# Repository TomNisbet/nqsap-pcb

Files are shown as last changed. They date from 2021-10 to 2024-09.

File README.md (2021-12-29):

# NQSAP-PCB

A multi-PCB version of the [NQSAP 8-bit computer](https://tomnisbet.github.io/nqsap/)

NQSAP-PCB

Visit the [NQSAP-PCB documentation pages](https://tomnisbet.github.io/nqsap-pcb/) for
detailed design notes and schematics.

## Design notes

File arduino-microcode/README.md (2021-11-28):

# NQSAP Microcode

This folder contains the Arduino sketch for the NQSAP Microcode Burner.  Some
documentation on the microcode is in the
[microcode documentation](https://tomnisbet.github.io/nqsap-pcb/docs/microcode/) section,
but the definitive resource is the burner code itself.

The hardware for the microcode burner is identical to the
[TommyPROM EEPROM Programmer](https://github.com/TomNisbet/TommyPROM) design.  The best
way to get started is to build and debug the hardware using that code and then compile
and load the microcode burner once the hardware is known to be working.  The TommyPROM
project has a better set of tools and more feedback to verify the design and even
includes a separate sketch for hardware troubleshooting if problems are encountered.

## Building

The Microcode Burner software is compiled using the Arduino IDE.  Load the
ardino-microcode.ino file and burn it to the target hardware.  Be sure to select the
correct Arduino board type under the tools->board menu.

## Burning microcode

The Microcode Burner sketch will burn a microcode ROM when the Arduino boots.  No user
interaction is needed.  When the burn is complete, the D13 LED will flash until the
Arduino is reset again.

If a USB cable is connected, progress messages will be printed to the serial output.

Every ROM burned receives a complete copy of the code for all of the Microcode ROMs, so
there is no need to make any selection when burning - just install each chip and then
power up the Arduino.

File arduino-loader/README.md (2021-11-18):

# NQSAP Loader and Debugger

This folder contains the Arduino sketch for the NQSAP Loader and Interactive Debugger.
The hardware design and features of the Loader/Debugger are listed in the
[Loader documentation](https://tomnisbet.github.io/nqsap-pcb/docs/loader/) in this repo.

This part of the project borrows heavily from the
[TommyPROM EEPROM Programmer](https://github.com/TomNisbet/TommyPROM) software.
Some details of the usage of the debugger, like the XMODEM transfers, may have additional
documentation available in that project.

## Building

The Loader software is compiled using the Arduino IDE.  Load the ardino-loader.ino file
and all of the supporting files should be included automatically.  Be certain to select
"Arduino Nano" as the Tools->Board menu of the IDE.

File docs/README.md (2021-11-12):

# NQSAP Documentation

To view the documentation, visit the [NQSAP-PCB github project page](https://tomnisbet.github.io/nqsap-pcb/)

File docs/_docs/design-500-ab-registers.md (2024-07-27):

---
title: "A/B and Shift Registers"
permalink: /docs/ab-registers/
excerpt: "A, B and Shift registers for the NQSAP-PCB computer"
---

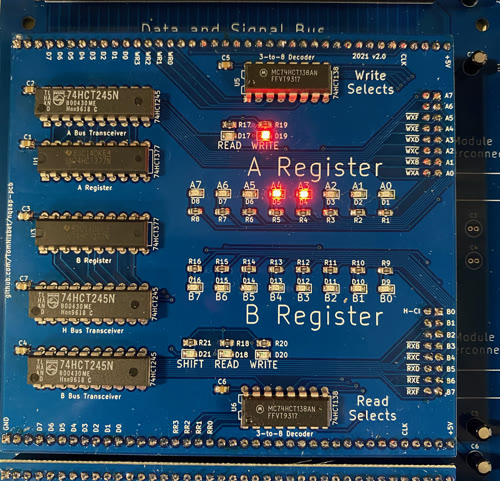
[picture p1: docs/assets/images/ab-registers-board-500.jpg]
A-B Registers


The A and B registers are 8-bit registers that provide the inputs to the ALU.  The A
register acts as an accumulator and general-purpose register that is accessible from
instructions available to the user.

The B register is only used as an operand register for the ALU operations.  It is not
accessible as a general-purpose register and there are no instructions to directly read or
write its contents.  The microcode may also use this register as temporarly storage for
non-ALU instructions.

The sHift register (register H), is a read-only register that returns the contents of the
B register shifted one position to the right.  The LSB of B shifts into the Carry flag.
The MSB of H is populated by the carry flag for the ROR (rotate right) instruction and is
hard-coded to zero for the LSR (logical shift right) instruction.  Note that H is not an
actual register.  It is simply a alternate way of reading the value of the B register.

The logic that controls the Carry Flag input, whether from the ALU or the B register, is on the [ALU Module](../alu).
The Carry Flag input for the H register is produced by the [Flags Module](../flags).

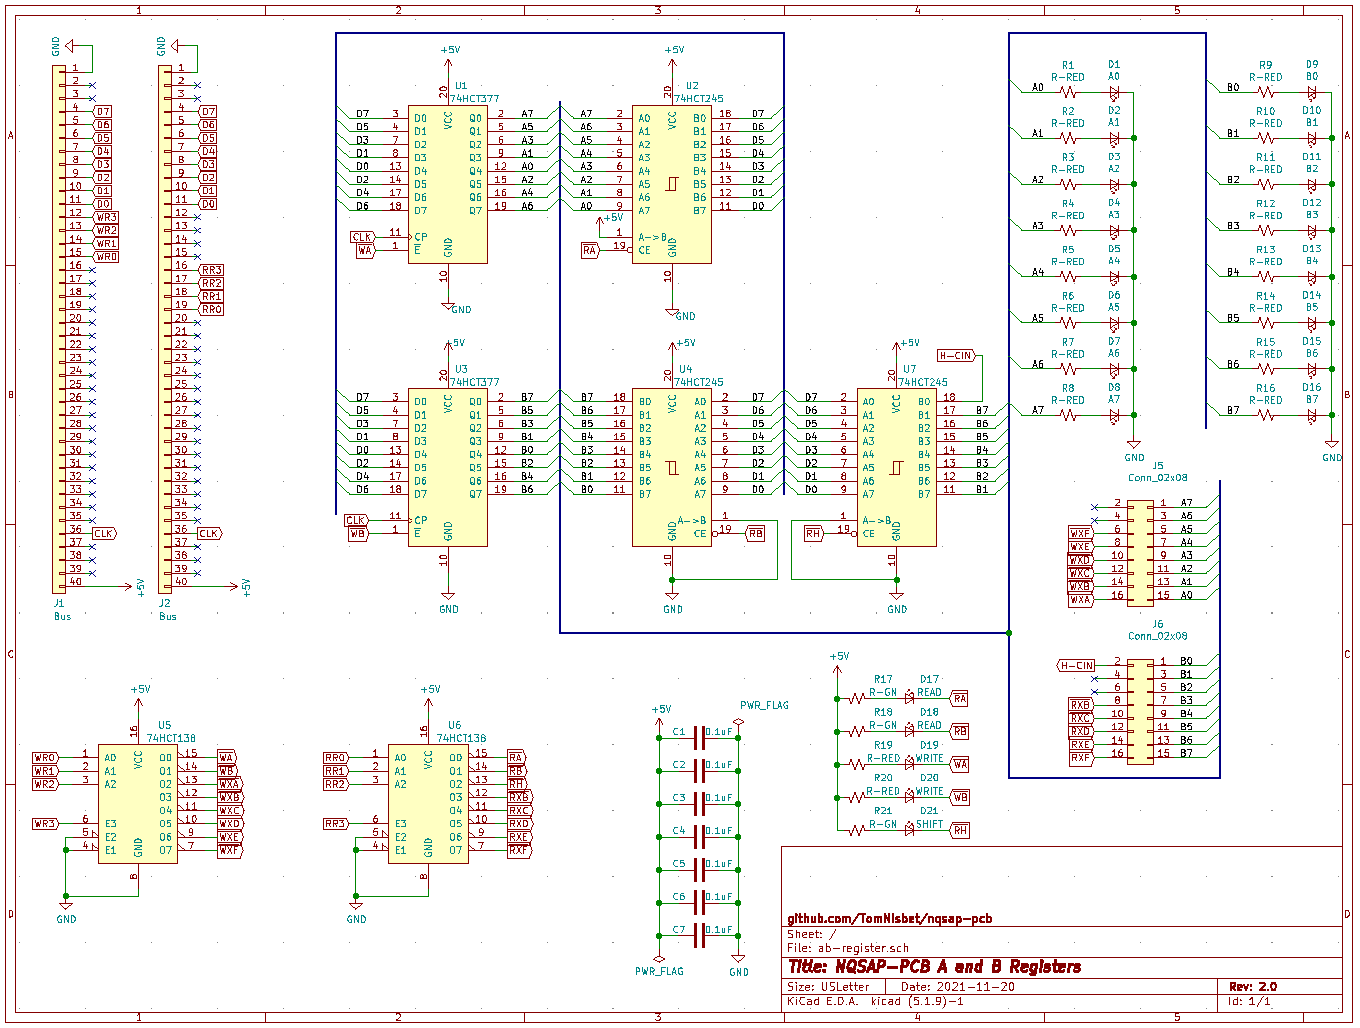
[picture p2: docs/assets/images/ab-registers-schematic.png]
A-B registers schematic


The A and B registers are each implemented using a 74HCT377 register and a 74HCT245 8-bit
bus transceiver. The H register is implemented using a second 74HCT245 wired to the B
register outputs, but offset by one bit.  The B7 bit is the H6 bit, B6 is H5 and so on.

The A/B Register module also has a pair of 74HCT138 3-to-8 decoders for read and write
register decoding.  These selects are used for the A/B/H registers on board and remaining
selects are presented on the module interconnect headers for use by the ALU and Flags
modules.

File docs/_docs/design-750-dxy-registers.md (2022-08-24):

---
title: "DXY Adder and Registers"
permalink: /docs/dxy-registers/
excerpt: "XY registers and Index Adder of the NQSAP computer"
---

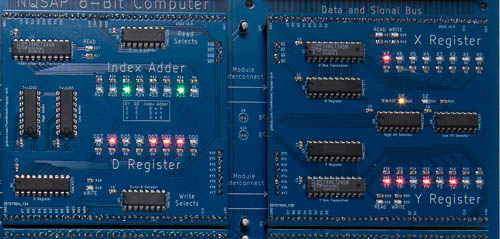
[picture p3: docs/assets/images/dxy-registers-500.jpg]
DXY Registers DXY registers and Index Adder


The XY registers and Index Adder are a set of three registers plus a dedicated adder to
implement two user-accessible registers and a set of new addressing modes.  The X and Y
registers are general-purpose registers that are also used as index registers. The D
register is a temporary register and adder that is only accessible at the microcode level.

With this hardware, NQSAP is able to use a set of addressing modes similar to those found
on a 6502.  The only difference is that the NQSAP does not have a sixteen-bit bus, so all
of the absolute address modes are the same as the zero-page modes of the 6502.  The
address modes available are:

* implicit
* accumulator
* immediate
* relative
* absolute
* absolute + X
* absolute + Y
* indirect
* indexed indirect (with X)
* indirect indexed (with Y)

With adder hardware dedicated to addressing modes, ALU instructions that access memory can
be implemented in fewer cycles.  Without the adder, the instruction _AND $40,X_ would need
to use the ALU to calculate $40+X and then would need the ALU again to do the AND
operation. This could be done in ten cycles and would need temporary storage to save the
accumulator while doing the address calculation.  With the DXY register, the instruction
can be implemented in only seven microinstructions, including the two for the opcode
fetch.

The D register can be added to either the X or Y register to produce a sum that can be
read onto the bus.  The diagram below shows how the registers are connected.

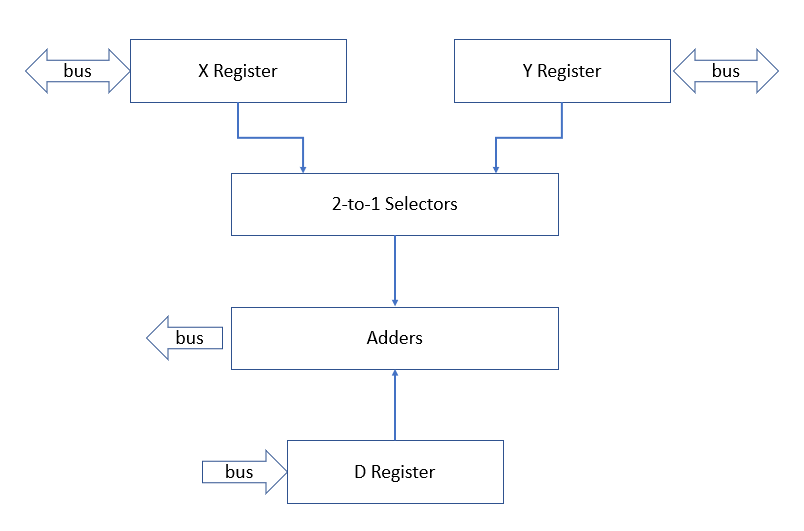
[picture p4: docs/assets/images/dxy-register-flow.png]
DXY Registers Flow DXY Registers data flow


The 2-to-one selectors allow either X or Y to be selected as a source for the adder.  The
selectors also have an enable line that presents zero at all of the outputs.  By wiring
the select and enable lines to the microcode ROMs, the functions D+X, D+Y, or D+0 can be
selected.

## Hardware

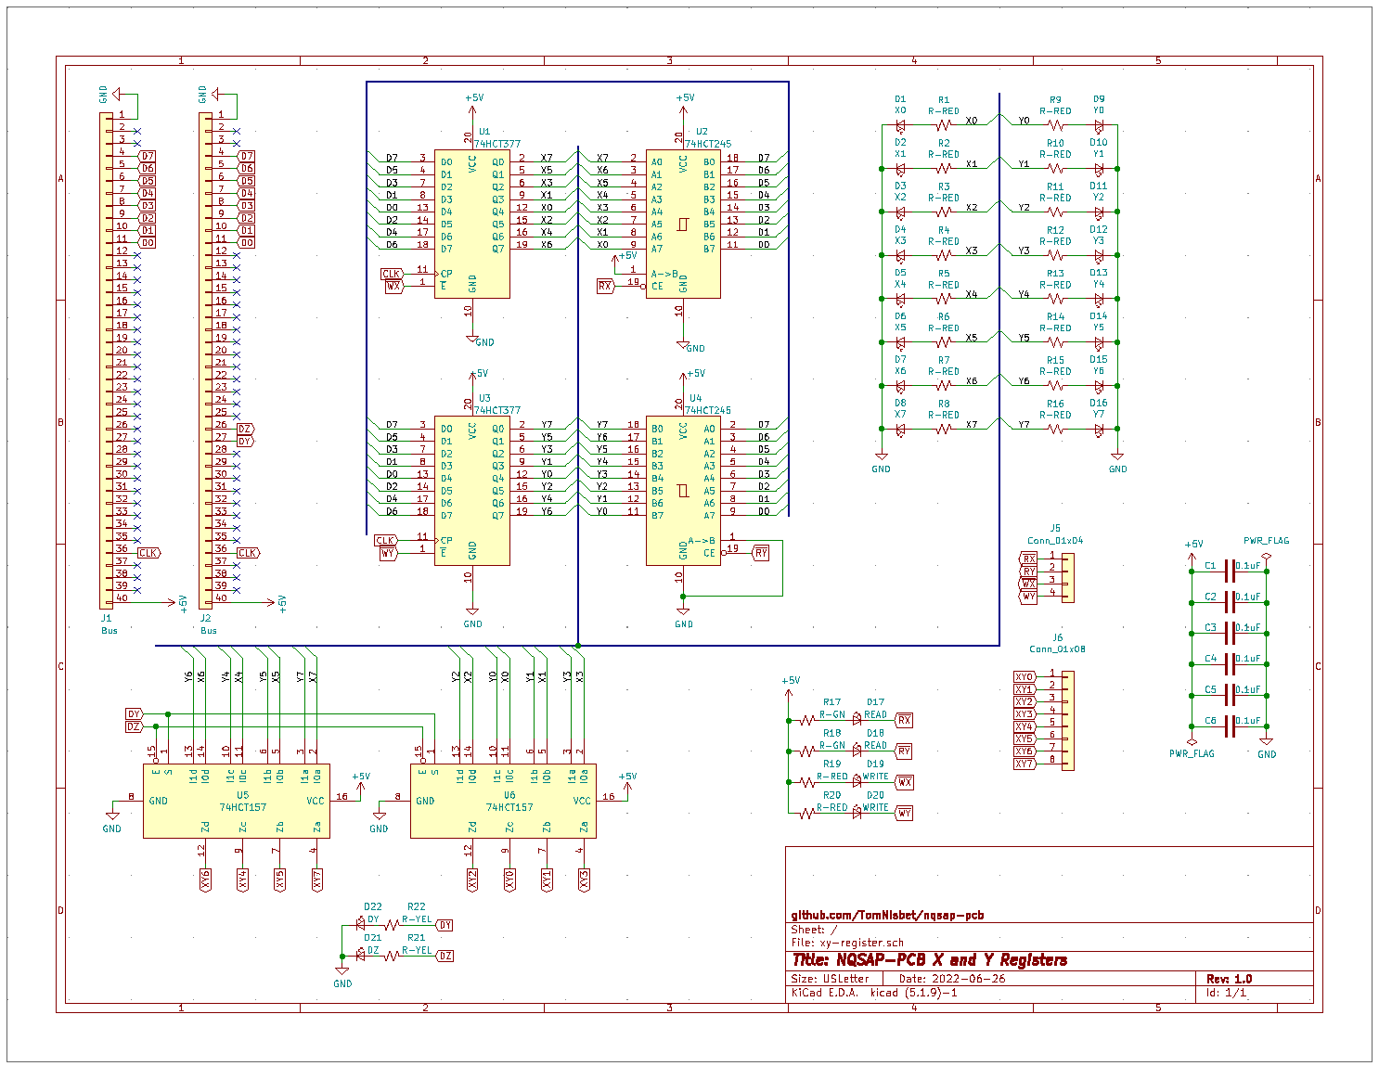
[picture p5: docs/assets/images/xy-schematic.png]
XY Registers Schematic XY registers

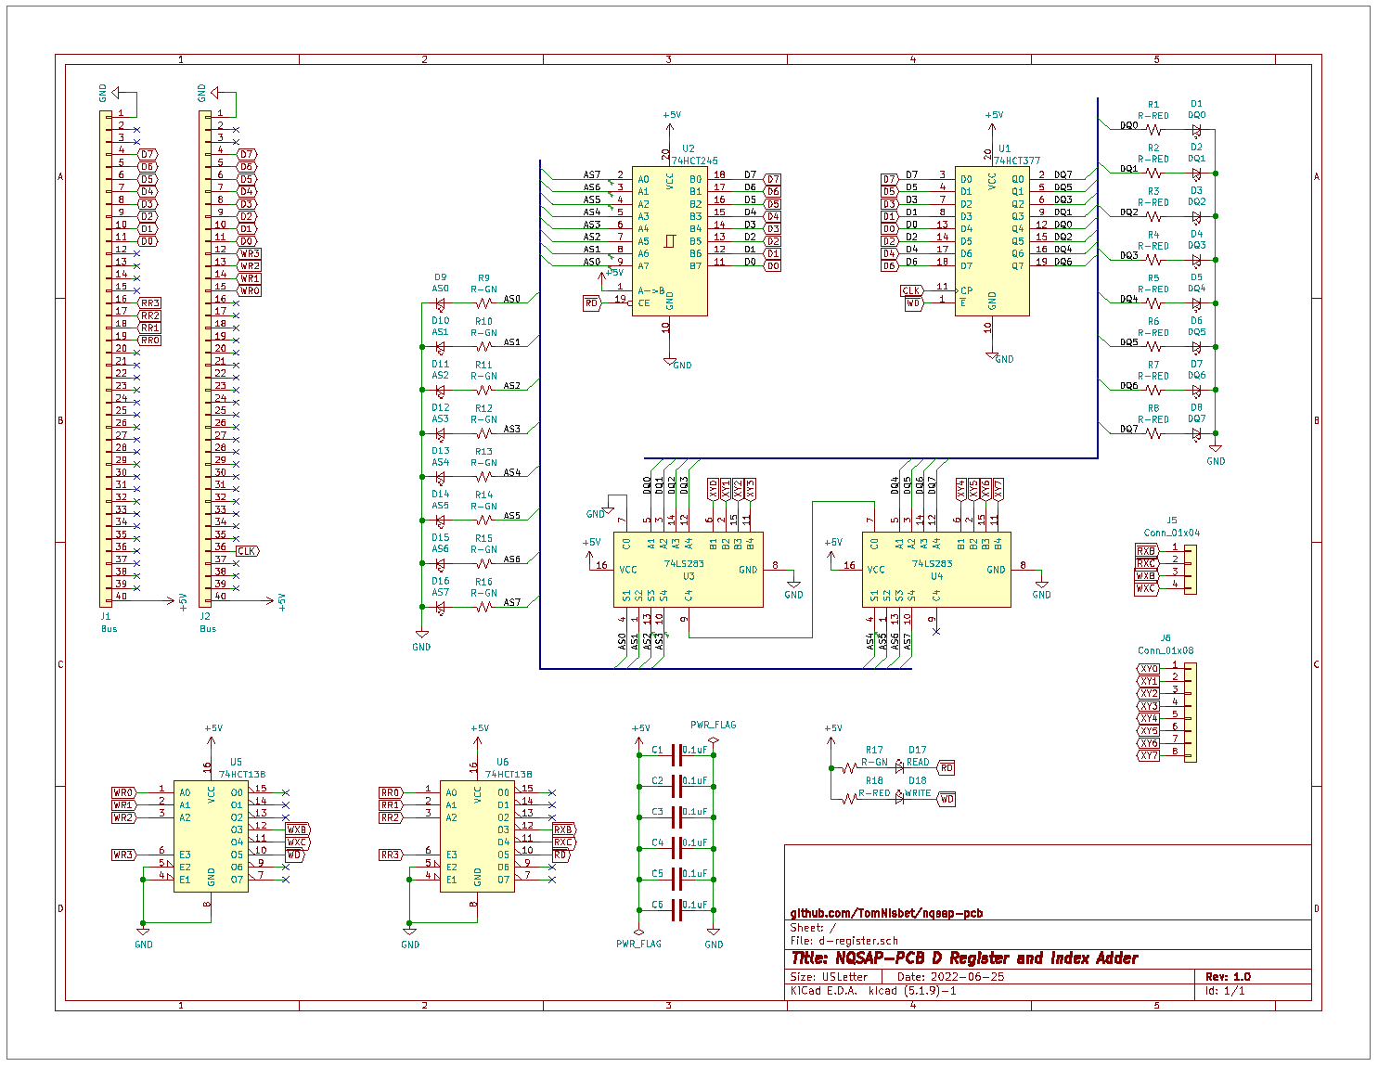
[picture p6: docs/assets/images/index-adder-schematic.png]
Index Adder D register and index adder


The Index Adder and XY Registers are spread over two module boards, mostly due to the
space needed for all of the LEDs. The X and Y registers are each implemented using a
74HCT377 8-bit register and a 74HCT245 8-bit bus transceiver.  The X and Y register
outputs are connected to the A and B inputs of a pair of 74HCT157 quad 2-to-1 selectors.
The selector outputs provide the XY<sub>0..7</sub> outputs on the module interconnect bus
for the Index Adder module.

The D register on the Index Adder module also uses the 74HCT377 register.  The board
contains a pair of 74HCT283 4-bit adders and a 74HCT245 bus transceiver.  The inputs to
the adders are the D register and the XY data output from the XY module.  The DY and DZ
lines from the microcode (shared with the C0 and C1 lines) are used to select the XY
source for the adder as X, Y, or zero.  The outputs of the adders are connected to the bus
through the 74HCT245.  The D register is not connected to the bus, but it can be read
through the adders by selecting the D+zero operation with the DZ control line.

The register select hardware for both boards is contained on the Index Adder module.  The
read and write signals for X and Y are passed through the module interconnect headers.

### Bill of Materials

* 74HCT138 3-to-8 selector(3)
* 74HCT157 quad 2-to-1 selector (2)
* 74HCT283 4-bit adder (2)
* 74HCT245 8-bit bus transceiver (3)
* 74HCT377 8-bit register (3)

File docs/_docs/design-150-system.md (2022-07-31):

---
title: "System Design"
permalink: /docs/system/
excerpt: "System-level design of the NQSAP-PCB computer"
---

## Register Decoding

The original breadboarded NQSAP had 4 control lines for read selects and 4 for write
selects.  Each of these was decoded to provide 15 rgister read and 15 register write
select signals.  The breadboard build had a single set of decoders, and then the 30
control lines were distributed out to the individual modules.  For the PCB build, the
limited number of bus lines makes this approach impractical.

The desire to keep the module boards at 100mm square and the use of a single row of
connector pins limited the bus to 40 pins total.  Using 30 of these pins just for register
decoding obviously would not work.  The tradeoff was to move the register decode hardware
to the module boards.

On the NQSAP-PCB build, the 4 register write selects and 4 register read selects are
presented on the bus, using a total of 8 pins.  Register select decoding is performed
locally and can be distributed across the module interconnects so that a group of three
module boards on a single backplane board can share a single set of decoders. Rather than
decode all 15 addresses, a module board will use a single 3-to-8 decoder to produce either
the low 7 addresses or the high eight addresses.

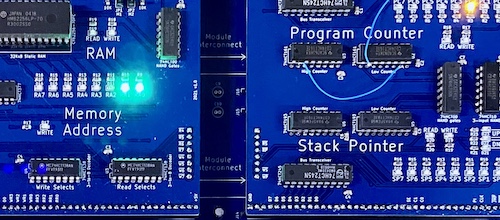
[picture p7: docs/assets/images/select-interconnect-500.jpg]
Register Select Interconnect register select interconnect


The picture above shows an example of a set of module boards sharing register select
decode logic.  The RAM board has a pair of 3-to-8 decoders to provide read and write
selects for the onboard RAM and MAR Register.  Additional selects are sent via the
interconnects for use by the PC/SP module.  While this does create dependencies between
groups of modules, it does eliminate the need for decode logic on each board or a larger
bus with centralized decoding.  In most cases, there are related boards that are already
passing other signals as well.

## Layout and Interconnects

The module interconnect headers on the backplane are used to connect signals that are
common to a small number of boards.  These interconnects keep the bus connectors limited
to signals that are typically used system-wide.  This does force the placement of some
modules in the final assembled computer.  The current design has four groups of related
modules that need to occupy the same backplane:

**Loader, Microcode, IR/RC**

The outputs of the Instruction Register and Ring Counter are sent to the Microcode module
to be used as address inputs to the EEPROMs.  The Loader sends control signals to the
Microcode board to disable the EEPROMs when the loader is active.

**A/B Registers, ALU, Flags**

The A/B board passes the outputs of its registers to the ALU as the as the operands for
arithmetic and logic calculations.  It also shares its register select signals.  The ALU
board passes calculated flag values to the Flags board and also forwards register selects
from the A/B board.

**RAM and PC/SP**

The RAM board has register select decoding for its own use and it shares additional select
lines over the intrconnect that are used by the PC/SP.  There are no other signals passed
between the boards, so the PC/SP could just as easily get its register selects from another
module or be re-spun to have them local.

**D/Index Adder and X/Y Registers**

An 8-bit value from the X/Y selector is passed to the Index Adder over the interconnects.
The D/Index Adder Module also provides the X/Y register select values.

## Register Selects

|Decimal|Hex  |Write|Read |Write Module|Read Module|
|:---:  |:---:|:---:|:---:|:---: |:---: |
|  0 | 0 |none |none | | |
|  1 | 1 |RAM  |RAM  |RAM |RAM |
|2 |2 |MAR  | |RAM | |
|3 |3 | | | | |
|4 |4 | | | | |
|5 |5 | | | | |
|6 |6 |SP |SP |RAM |RAM |
|7 |7 |PC (Jump)|PC|RAM |RAM |
|8 |8 |A |A |A/B |A/B |
|9 |9 |B |B |A/B |A/B |
|10 |A |Output|H (sHift)|Output |A/B |
|11 |B |X |X |D |D |
|12 |C |Y |Y |D |D |
|13 |D |D |Adder|D |D |
|14 |E | |ALU  | |A/B |
|15 |F |IR |Flags|IR |A/B |
|====

Note that modules use only one 3-to-8 decoder chip, so they can decode
either addresses 0-7 or 8-15.  The ALU and Flags modules use a local
copy of the IR, so even though the A/B and IR board do not share any
signals, they must both use addresses in the same group.

## Bus Signal List

|Pin|Name|Description|
|:---:|:---:|:---|
|1 |GND|Ground|
|2 |n/c|(spare)|
|3 |n/c|(spare)|
|4 |D7 |Data 7|
|5 |D7 |Data 6|
|6 |D7 |Data 5|
|7 |D7 |Data 4|
|8 |D7 |Data 3|
|9 |D7 |Data 2|
|10|D7 |Data 1|
|11|D7 |Data 0|
|12|WR3|Write Register 3|
|13|WR2|Write Register 2|
|14|WR1|Write Register 1|
|15|WR0|Write Register 0|
|16|RR3|Read Register 3|
|17|RR2|Read Register 2|
|18|RR1|Read Register 1|
|19|RR0|Read Register 0|
|20|FN |Flag write Negative|
|21|FV |Flag write oVerflow|
|22|FZ |Flag write Zero|
|23|FC |Flag write Carry|
|24|FB |write Flags from Bus|
|25|SE |Stack increment/decrement Enable|
|26|C1 |Carry select 1 (also DZ, Stack Increment)|
|27|C0 |Carry select 0 (also DY, Stack Decrement)|
|28|CS |Carry flag force Set|
|29|CC |Carry flag force Clear|
|30|M1 |Memory Select 1 (RAM)|
|31|M0 |Memory Select 0 (RAM)|
|32|LF |ALU Force select bit|
|33|~JE |Jump Enable (active low)|
|34|N  |Next instruction (clear ring counter)|
|35|PI |Program counter Increment|
|36|CLK|master Clock pulse|
|37|n/c|(spare)|
|38|n/c|(spare)|
|39|~RST|master RESET (active low)|
|40|Vcc|+5 Volts|
|====

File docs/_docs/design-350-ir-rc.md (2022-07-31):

---
title: "Instruction Register and Ring Counter"
permalink: /docs/ir-rc/
excerpt: "Instruction Register and Ring Counter for the NQSAP-PCB computer"
---

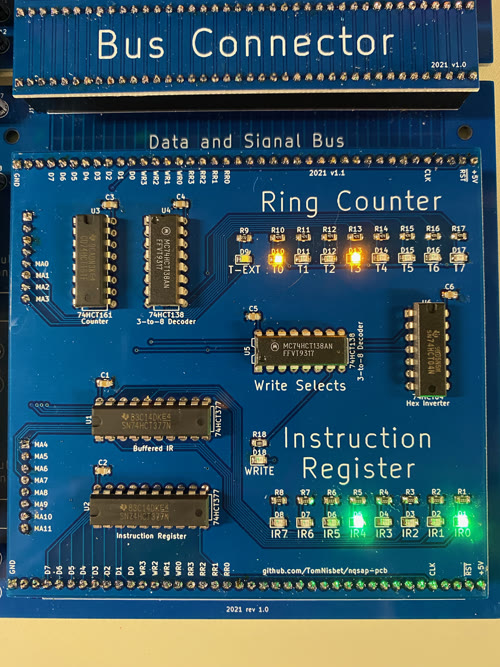
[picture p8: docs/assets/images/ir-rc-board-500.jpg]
Instruction Register and Ring Counter


The Instruction Register (IR) and Ring Counter (RC) provide a 12-bit address for the microcode ROMs.

## Ring Counter
This is really a binary microinstruction counter but it has two attached 3-to-8 decoders
that give output that looks like a ring counter.  This output is only used for the LED
display that indicates the step - the input to the ROMs will be the 4-bit binary output of
the counter. Still, the ring counter terminology is used to match the Ben Eater builds.

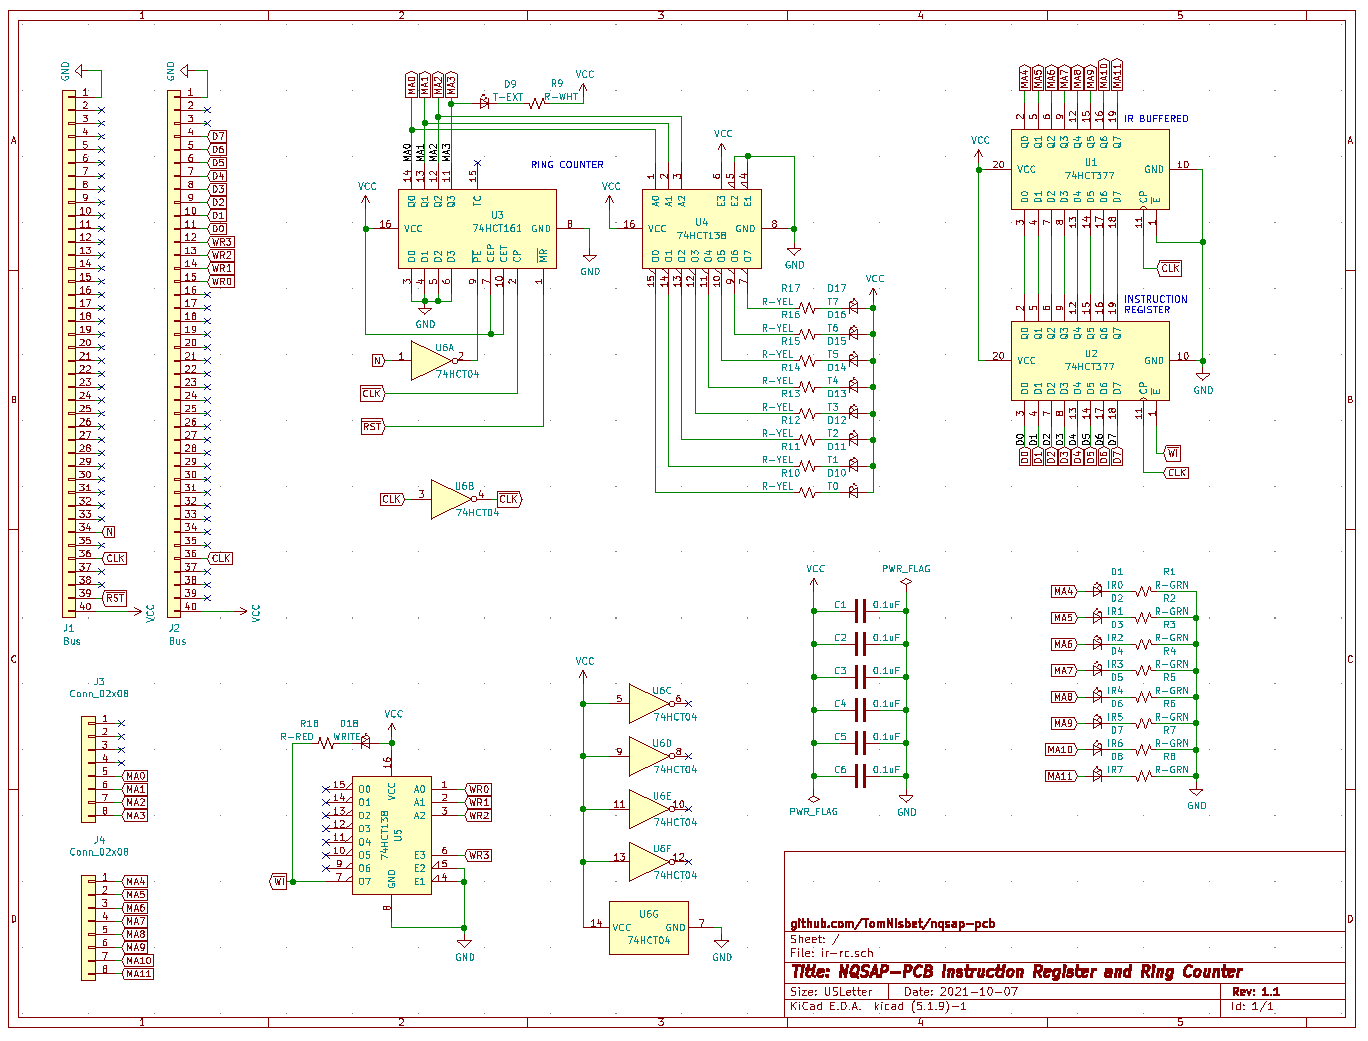
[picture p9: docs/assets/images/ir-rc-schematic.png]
Instruction Register and Ring Counter schematic


## Instruction Register

The Instruction Register is double buffered to reduce
[glitches when the EEPROM address lines change](../eeprom-glitch).  In the non-buffered
design, the EEPROM outputs will be in an unknown state for about 100ns when the Ring
Counter address changes on every falling edge of the system clock.  In addition, the
outputs will also glitch on the rising edge of the clock at instruction step T1 when the
IR is loaded with the new opcode.  The double buffer adds a second register following the
IR register that loads at T1.  This register loads the contents of the IR and presents
them to the ROM address lines on every falling edge.  As a result, the EEPROM address
lines only ever change on a falling clock edge, allowing logic that combines ROM signals
with a positive clock signal.

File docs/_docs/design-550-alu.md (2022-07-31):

---
title: "ALU"
permalink: /docs/alu/
excerpt: "Building the Arithmetic Logic Unit (ALU) of the NQSAP computer"
---

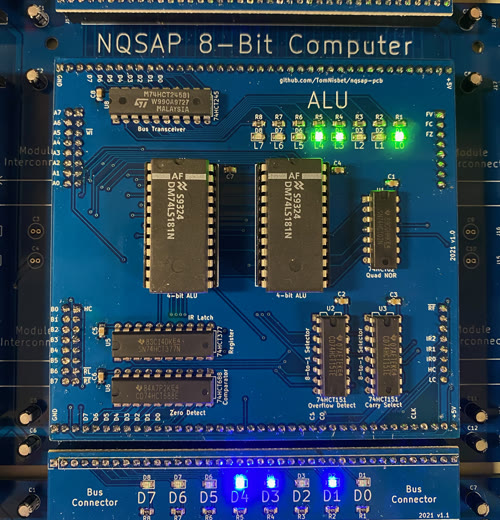
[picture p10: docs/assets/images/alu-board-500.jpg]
Arithmetic Logic Unit (ALU) ALU


The NQSAP-PCB computer uses a pair of 74LS181 4-bit ALU chips instead of the simple
adder/subtractor circuit in the SAP-1.  The advantage to this is a greatly increased set
of operations available, including increment/decrement as well as bitwise AND OR, and XOR.

The disadvantage to the use of an ALU chip is that the 74181 requires 6 control lines to
select an operation, rather than the single ADD/SUBTRACT needed for the simple adder.

In the NQSAP-PCB design, the Mode bit and the 4 Operation Select bits are hard-wired to
the Instruction Register, so that the opcode of the instruction directly determines the
operation selected on the ALU.  This saves the need for 5 additional control lines from
the microcode ROMs.  It also makes the microcode for all ALU operations identical, so they
can be generated programmatically in the Arduino code.  Because the Mode and Select lines
are wired to the Instruction Register, only the Carry-in signal is provided by the
microcode ROMs.

Rather than providing the outputs of the Instruction Register on the bus or requiring an
interconnect between the IR and ALU, the ALU module keeps its own copy of the IR in a
local register that loads on the WI signal.  Five bits of this register are used by the
ALU, and three more are passed to the Flags Module for conditinal jump selection.

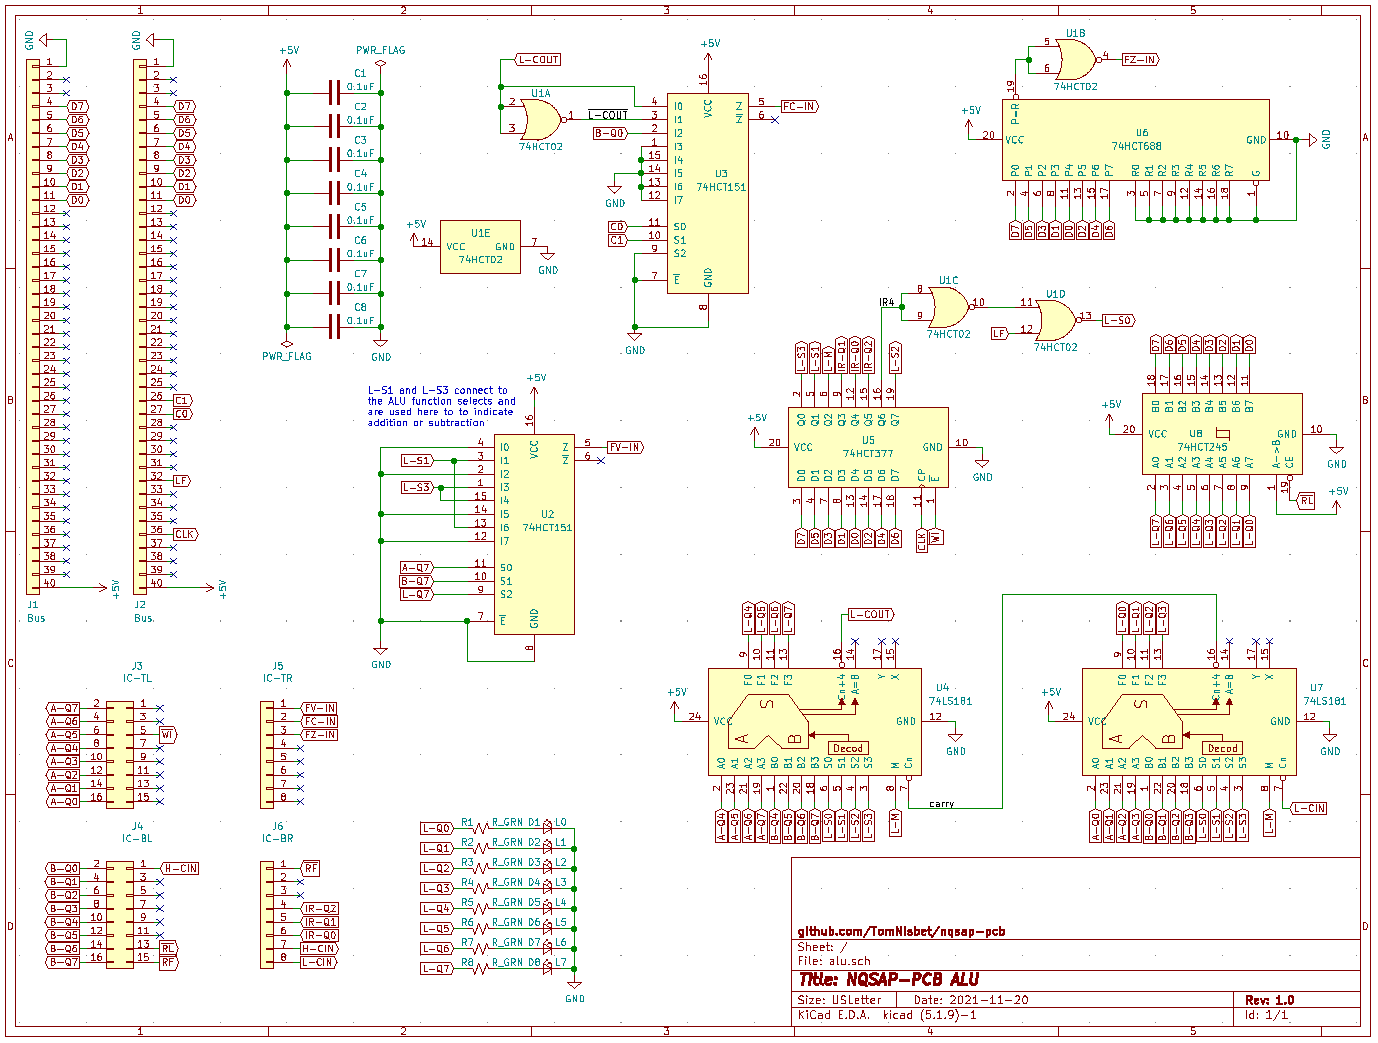
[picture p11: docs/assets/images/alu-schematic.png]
NQSAP ALU schematic) ALU schematic


The inputs to the ALU are the A Register (H) and the B register.  All ALU instructions
write their result to the A register.

Note that the subtract and compare instructions both need the ALU to be in subtract mode.
Because the ALU select lines are hard-wired to the IR, there are only eight opcodes
available that put the ALU in the correct mode.  To create the sixteen different opcodes
that are needed for all of the addressing mode combinations of the subtract and compare
instructions, a NOR gate is placed between the inverted IR output and the ALU S0 input.
The other NOR input is the microcode ROM LF (aLu Force) line.  When this is asserted,
the ALU S0 is forced to zero.  This is used to create a new set of eight subtract mode
instructions by setting the ALU select bits to 0110 when the low IR bits are 0111.  The
ALU operation for 0111 would normally be A and not B, which isn't useful.

In addition to the 74181 ALUs, the NQSAP ALU module needs a few more chips.  As with other
read registers in the NQSAP, a 74HCT245 bus transceiver is used to selectively place the
ALU result on the bus.  

Note that the ALU result is a read-only register.

## 74181 ALU operations used by NQSAP

|M | Cn| S3| S2| S1| S0|Operation|
|:---:|:---:|:---:|:---:|:---:|:---:|---|
|0 | 0 | 0 | 0 | 0 | 0 | A plus 1
|0 | 0 | 0 | 0 | 1 | 1 | zero
|0 | 0 | 0 | 1 | 1 | 0 | A minus B
|0 | 1 | 0 | 0 | 1 | 1 | all ones
|0 | 1 | 1 | 0 | 0 | 1 | A plus B
|0 | 1 | 1 | 1 | 0 | 0 | A plus A _[left shift]_
|0 | 1 | 1 | 1 | 1 | 1 | A minus 1
|1 | x | 0 | 0 | 0 | 0 | not A
|1 | x | 0 | 1 | 1 | 0 | A xor B
|1 | x | 1 | 0 | 1 | 0 | B
|1 | x | 1 | 0 | 1 | 1 | A and B
|1 | x | 1 | 1 | 1 | 0 | A or B
|====

The ALU all-zero bits and all-one bits operations are used in the microcode to get zeros
or ones onto the bus for the flag set and clear operations.

The B operation is no longer used.  It was originally used by the CALL instruction to read
B for temporary storage.  The B register was later redesigned to add its own bus
transceiver to allow direct read access.

## Flags

Most of the flag condition detection circuitry is present on the ALU module, rather than
on the Flags module.  Ths was done because the Flags module was already densly populated
and the ALU module had free space.  It was easy enough to place the three flag detection
outputs on the interconnect between the boards.

See the [Flag Calculations section of the Flags page](../flags/#flag-calculations) for a
description of the flag detection hardware.

### Zero flag

The 74181 ALU does not have an output to indicate a zero result from an operation so a
74HCT688 8-bit comparator is used to detect all zeroes on the bus.  The ALU does have an
_A=B_ bit that can be used for comparison operations, but it is not used in the NQSAP
design.

Using the bus instead of the ALU output for zero-detect means that it can also be used
with non-ALU operations like register loads or transfers.

### Carry flag

Using the carry flag output (C<sub>n+4</sub>) as a processor flag is not straightforward
to understand because the logic state used to indicate an overflow changes depending on
the operation.  For the addition operations, a logic LOW indicates carry occurred, but
logic HIGH is used to indicate borrow needed for subtraction.  See the
[74181 ALU notes](../74181-alu-notes/) section for an explanation of why the chip does
this.

|Selects|Operation|C<sub>n+4</sub> on overflow|
|:---:  |:---: |:---:|
| LLLL  | A + 1 |  L  |
| LHHL  | A - B |  H  |
| HLLH  | A + B |  L  |
| HHLL  | A + A |  L  |
| HHHH  | A - 1 |  H  |
|====

The NQSAP addition and subtraction operations are modeled after the 6502 processor.  An
addition with carry instruction will produce A+B when carry is clear and A+B+1 when carry
is set.  The carry flag will be set at the completion of the operation if the addition
carried into the non-existent ninth bit.

A subtraction with carry operation will produce A-B-1 when the carry bit is clear and A-B
when the carry is set.  The carry flag will be cleared at the completion of the operation
if the subtraction required a borrow from the non-existent ninth bit.

This usage is consistent with the 74181 ALU, but the use of the flag is inverted because
the 74181 uses an active low carry signal.  The C<sub>n+4</sub> carry out signal from the
high ALU is inverted to provide the 6502-like flag.

### oVerflow flag

## Bill of Materials

* 74HCT02 quad 2-input NOR gates (1)
* 74HCT151 8-to-1 selector (2)
* 74LS181 4-bit Arithmetic Logic Unit (2)
* 74HCT245 8-bit bus transceiver (1)
* 74HCT377 8-bit register (1)
* 74HCT688 8-bit comparator (1)

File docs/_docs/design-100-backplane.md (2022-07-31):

---
title: "Backplane"
permalink: /docs/backplane/
excerpt: "Backplane for the NQSAP-PCB computer"
---

The NQSAP-PCB backplane and interconnect design is based on an [8-bit PCB implementation
by
djh82uk](https://www.reddit.com/r/beneater/comments/pn4j6j/finally_complete_with_all_bugs_fixed/)

The system is built from three types of boards.  The Backplane board is a passive base
board with a generic 40 pin bus.  Module boards have the functional circuitry for the
computer, like the registers, ALU, or Program Counter.  Module boards plug into the bus
connectors on the Backplane board.  A single Backplane can hold three Module boards.  Bus
Connector boards connect two adjacent Backplane boards, extending the system vertically to
accomodate additional modules.  

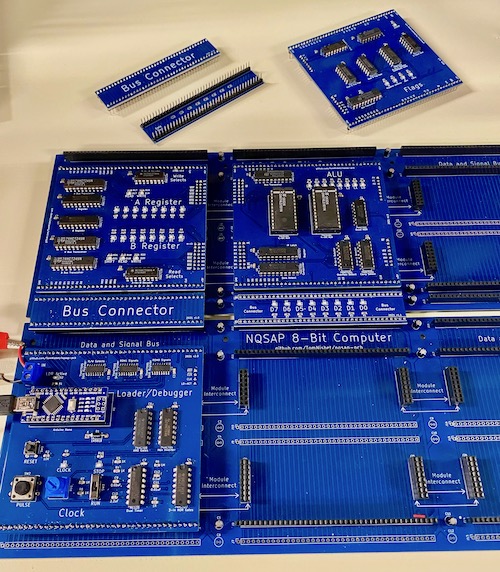
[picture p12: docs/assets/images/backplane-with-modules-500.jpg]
Backplane with modules backplane with module boards


In addition to the bus signals, which connect to all modules, the Backplane board also has
interconnect headers that allow signals to be passed between two adjacent Module boards.
For example, the A/B Register module uses the interconnects to pass the A and B outputs to
the ALU module.

The Backplane boards contain no active components.  Other than the ground and power
connections on pins 1 and 40 of the bus, there are no other bus signals that are
interpreted by the backplane.  This makes it suitable to any number of generic designs.

## Backplane and Bus

The main system bus is 40 pins using 2.54mm spacing.  This was chosen as the largest
number of pins that would find on a 100mm board.  All of the 40 pin connectors on the
bakplane are wired together, so pin one on a connector is wired to pin one on every other
connector.

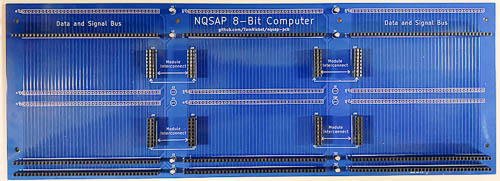
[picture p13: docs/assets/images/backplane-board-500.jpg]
Backplane backplane


Each Backplane board can hold three full-height modules across.  Any module slot can hold
one full-height or two half-height modules.  The full size module boards measure 90mm from
the top row of pins to the bottom row.  The total board height is 96mm.  The current
system is not using and half-height modules.

Module boards attach to the Backplane board using 40 pin headers along the top and bottom
edge of the module.  This provides both the electirial and mechanical connection - there
are no screws or fasteners to hold the modules in place.  The signals are identical on the
top and bottom connectors, so the modules can pull signals from either set of pins, giving
flexibility in their routing.

Backplane boards have additional 40-pin bus connectors along the top and bottom so that
multiple backplane boards can be chained together to accomodate additional groups of three
module boards.  A small Bus Connector board is used to connect the backplanes. Three Bus
Connectors are used to provide mechanical stability between a pair of backplanes. Each one
of the three is connecting the entire bus, so only one Bus Connector is technically needed
to make the electrical connections.

## Backplane module interconnects

A 2x8 pin header is provided between each half-height board to make module-to-module
connections.  A full height board can use both sets of connectors for a total of 32 pins.
Rather than being connected left to left and right to right, the interconnects have the
inner pins connected and the outer pins connected.  A module needing 8 or fewer
connections could populate just a 1x8 connector instead of a 2x8 to save space.

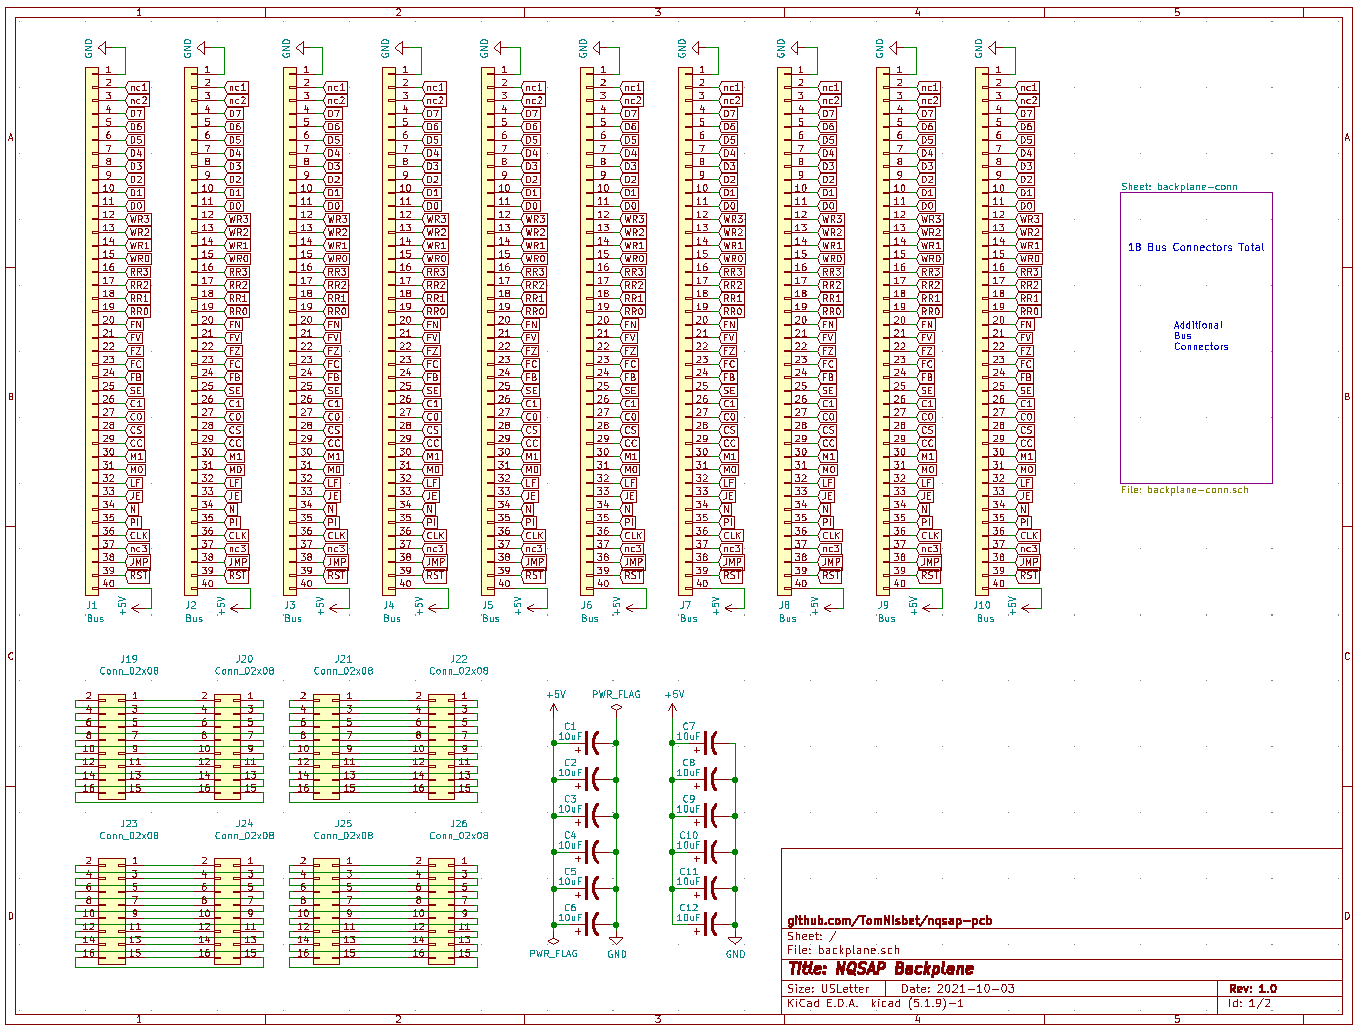
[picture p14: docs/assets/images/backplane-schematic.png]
Backplane backplane


Note that the interconnects are not connected all the way across the backplane.  If the
left module and right module need to talk, the signals will need to route through the
middle module.  Because the interconnects do not connect all the way across, it is
possible that the left and middle modules could use a different set of interconnects as
the middle and right modules.

There are no module-specific interconnects vertically, so related boards should share the
same backplane board to leverage the horizontal interconnects.

## Bus connectors

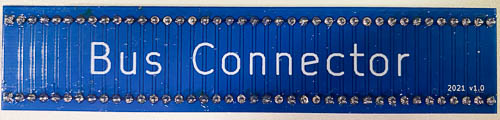
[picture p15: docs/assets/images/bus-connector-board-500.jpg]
Bus connector bus connector
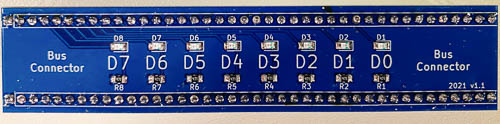
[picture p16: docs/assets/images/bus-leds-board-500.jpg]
Bus LEDs bus LEDs


The Bus Connector boards connect Backplane boards together to expand the computer
vertically. Three connectors are used between each pair of backplane boards.  The bus
connectors wire all 40 lines top-to-bottom.

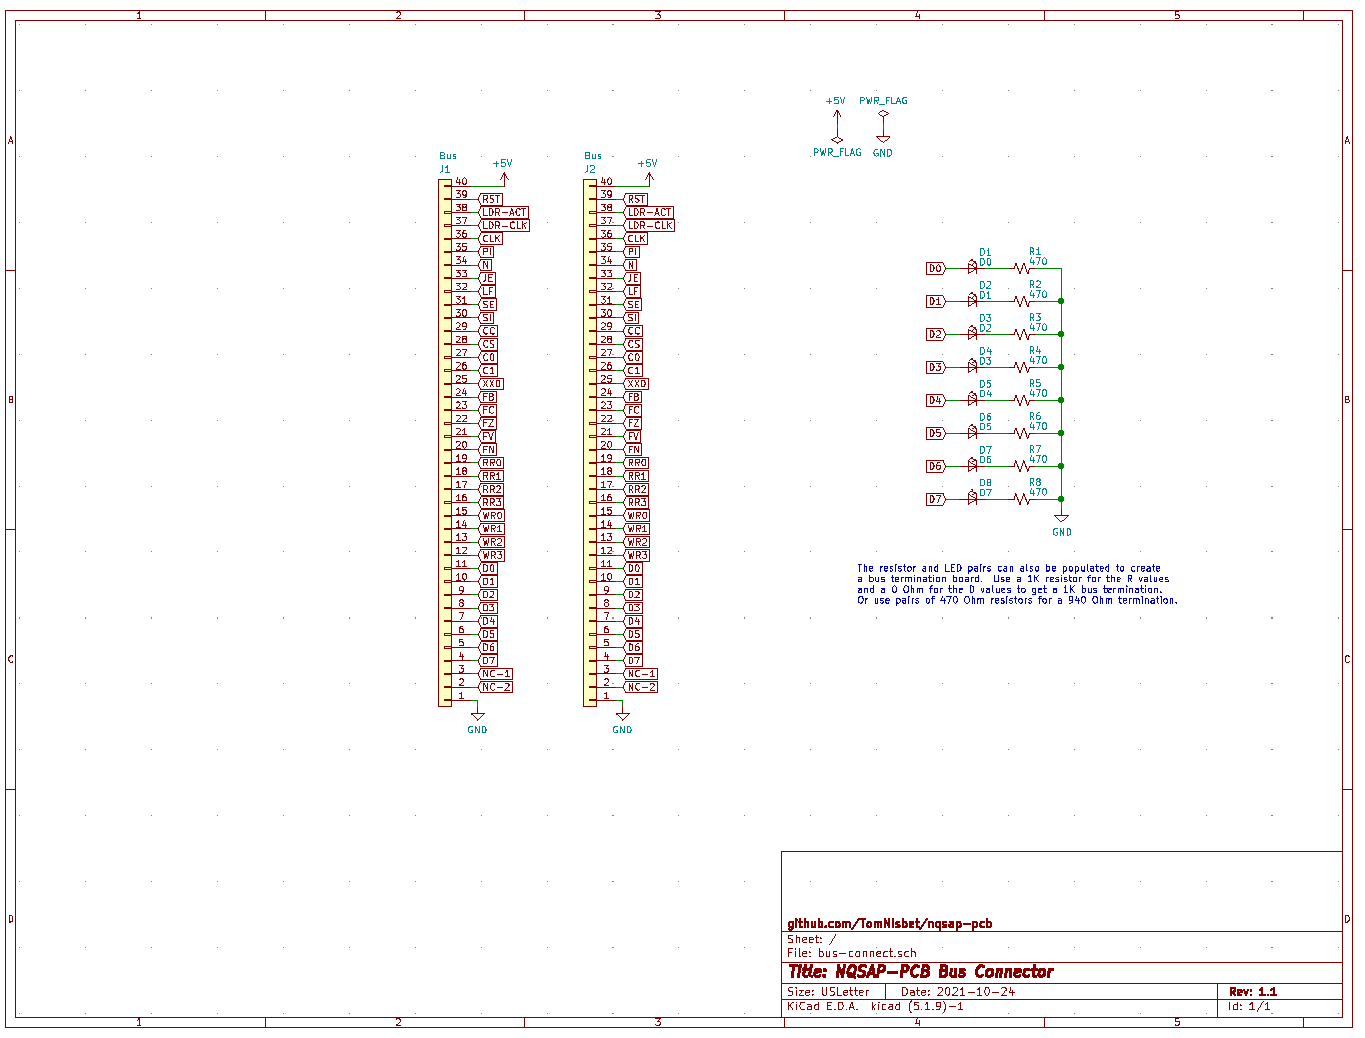
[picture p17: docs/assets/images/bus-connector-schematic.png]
Bus connector schematic bus connector schematic


### Data LEDs and termination
The Bus Connector boards have additional functionality on the reverse side.  With the board flipped and the pin headers installed on the other side, LEDs and resistors can be added to display the status of the data bus.

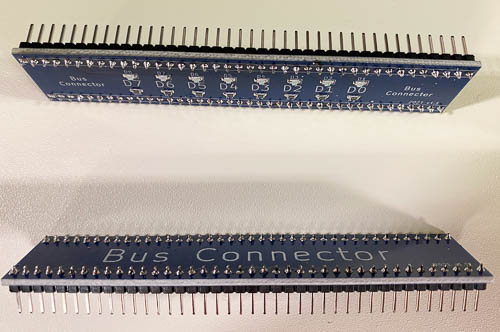
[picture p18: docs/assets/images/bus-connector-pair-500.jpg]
Bus connector variations bus connector variations


The resistor and LED pairs can also be populated to create a bus termination board.  Use a 1K resistor for the R values and a 0 Ohm for the D values to get a 1K bus termination. Or use pairs of 470 Ohm resistors for a 940 Ohm termination.

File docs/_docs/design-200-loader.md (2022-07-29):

---
title: "Loader / Debugger"
permalink: /docs/loader/
excerpt: "Arduino-based Loader/Debugger for the NQSAP-PCB computer"
---

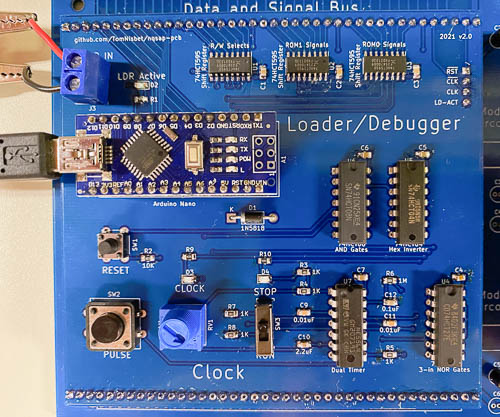
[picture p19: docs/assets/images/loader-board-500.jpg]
Arduino Loader loader


Version 2.0 of the Loader module adds the system clock and master reset circuits to the
board.  There was space on the board and it makes sense to co-locate these functions to
reduce the number of signals that need to be on the control bus.  The
[clock module page](../clock/) has the schematics and circuit description for the clock
functionality.

The program memory loader uses an Arduino Nano in place of manual-entry DIP switches on
the SAP-1.  The Loader/Debugger has eight of the Arduino I/O lines connected directly to
the NQSAP host bus for read and write access.  It can drive all of the microcode control
lines plus the CLK and RST lines.

Beyond the ability to simply load programs into memory, the Loader can read and write all
of the NQSAP registers and drive any other control signals. This gives the Loader the
capability to perform a comprehensive system verification.  This system test is helpful
for verifying the operation of new modules.

The Loader writes a default program to the NQSAP memory at power up, allowing unattended
operation.  If a USB connection is established, the Loader provides a ROM monitor-like
command line interface to interact with the NQSAP hardware.  The following features are
available via the USB interface:

* Memory
  * Load memory from a set of programs or patterns that are hard-coded into the Loader
  * Dump the contents of memory in hex and ASCII
  * Edit memory values
  * Fill a section of memory with a value
  * Load or save memory to a file using the XMODEM protocol
* Registers
  * Read and print the value from a register
  * Write a value to a register
  * Transfer the value from one register to another
* Diagnostics
  * Test all microcode control lines with a walking LED pattern
  * Test all registers with a pattern that can be visually observed
  * Test all read/write registers by reading back the patterns written
  * Test memory with a set of patterns including walking bits
  * Test the ALU by writing operands and operations and verifying the result
  * Test the right-shifted value of the B register as presented on the H register
  * Test the calculation of the flag values and the conditional jumps
  * Test the increment and decrement operations of the Stack Pointer

## Loader Design

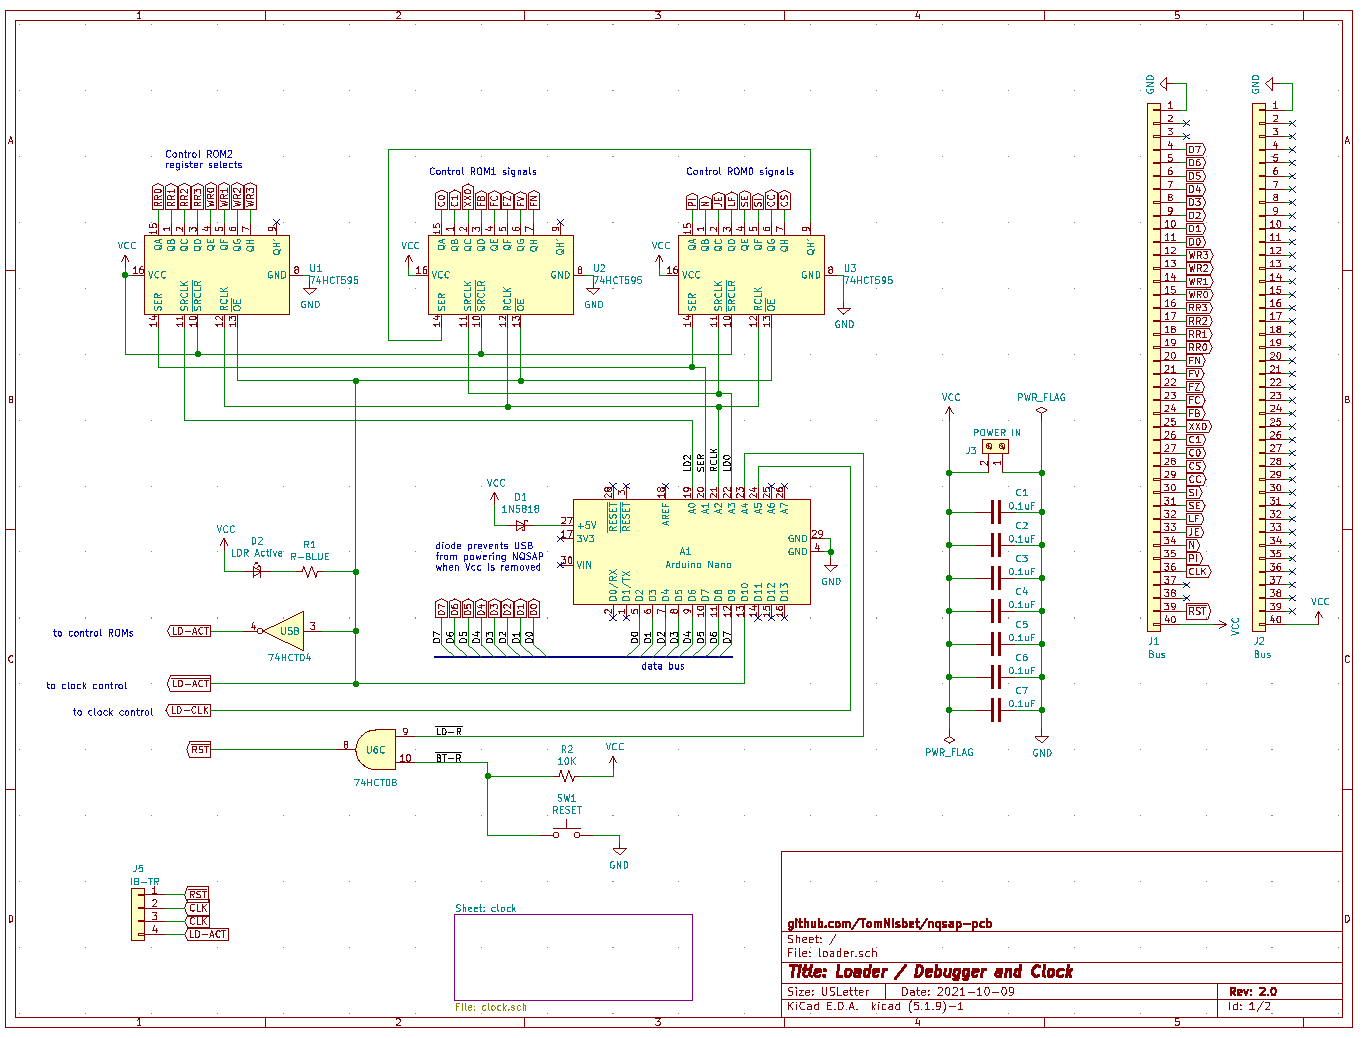
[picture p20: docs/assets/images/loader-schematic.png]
Arduino Loader loader/debugger


The Loader uses three 74HCT595 8-bit shift registers to drive the twenty-four microcode
ROM control outputs. The output enable of these registers is tied to the Loader's ACTIVE
signal and the output enable of the microcode ROMs is the inverted ACTIVE signal, ensuring
that only one source will be outputting a signal at any time. The Loader uses four Arduino
outputs to drive the inputs of the shift registers.  

## Loader implementation

The loader uses an Arduino Nano clone.  Note that the Loader Arduino is designed to be
left in the circuit even when not connected to a controlling computer through USB.  Upon
power up, the loader will activate itself and then load a default program into the NQSAP.
So even in standalone mode, the NQSAP will power up into a state where it has code to
execute.  There is no manual dip switch loader, so there is no way to load memory without
the Arduino.

The Arduino is powered from the NQSAP Vcc through a diode so that if the NQSAP is powered
off it does not try to draw power from the Arduino's USB port.  The USB port is connected
to the host computer with a hub that has individual power switched, allowing the host
computer's power to be disconnected from the NQSAP.

## Bill of Materials

This BOM includes the reset and clock circuitry as well as the Loader.
* 74HCT04 hex inverter (1)
* 74HCT08 quad 2-input AND gate (1)
* 74HCT27 triple 3-input NOR gate (1)
* 74HCT595 8-bit shift register (3)
* NE556 dual timer (1)
* Arduino Nano

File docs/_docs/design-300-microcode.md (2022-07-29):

---
title: "Microcode ROMs"
permalink: /docs/microcode/
excerpt: "Microcode ROMs for the NQSAP-PCB computer"
---

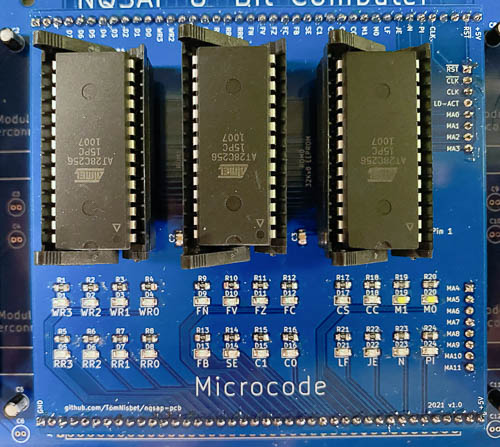
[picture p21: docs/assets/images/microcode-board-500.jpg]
Microcode ROMs


The microcode ROMs drive the 24 control signals for the NQSAP-PCB computer.  This board
contains LEDs for all control signals.

With an 8-bit Instruction Register and a 4-bit Ring Counter, the NQSAP
can support 256 unique instructions with 16 microcode steps each.  This consumes 12 of the 15 available address pins on the ROMs.  The
chip select uses 2 more pins, and 1 address pin is unused.

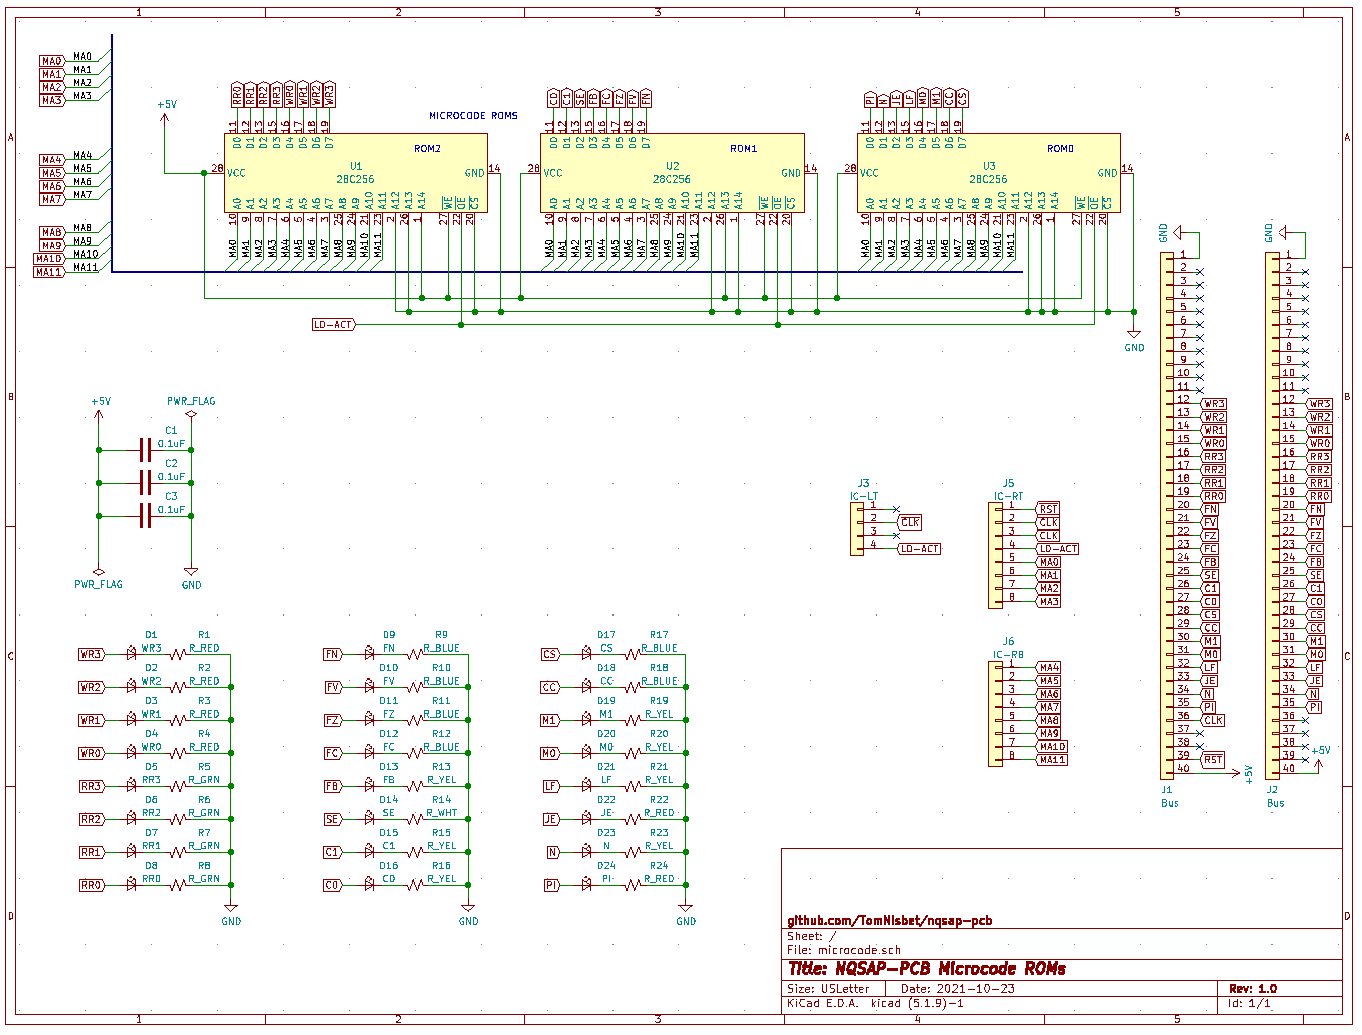
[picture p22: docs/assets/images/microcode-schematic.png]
Microcode ROMs schematic


The microcode is stored in three 28C256 32Kx8 EEPROMs, giving 24 control signals.  The
signals can be driven by the ROMs or by the Arduino Loader/Debugger.  When the Arduino
is active, the OE signal of the ROMs is disabled.  The LEDs always show the state of the
control lines, whether they are driven by the ROMs or by the Loader.

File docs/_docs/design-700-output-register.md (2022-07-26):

---
title: "Output Register"
permalink: /docs/output-register/
excerpt: "Output register and display of the NQSAP computer"
---

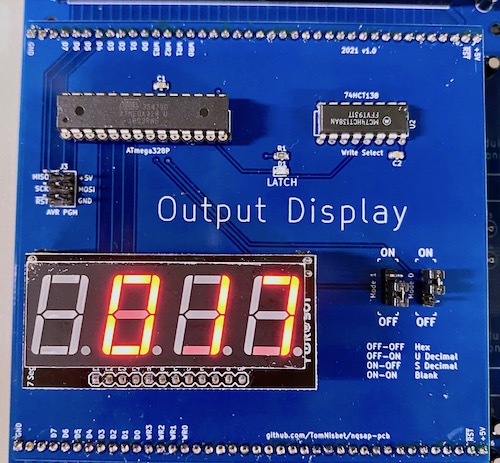
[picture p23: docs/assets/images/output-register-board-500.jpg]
Output register and display output register


The NQSAP uses a different approach to the output display than the Ben Eater SAP-1.
Instead of driving an LED display with a sequencer and an EEPROM, an ATmega328 is used.
The Atmega replaces not only the EEPROM and counter hardware, but it also takes care of
the buffering, eliminating the 74ls173 registers.

The board includes its own address decoding hardware, so it has no dependencies on other boards and requires no interconnet. There is a space to populate an AVR connector to
flash new code onto the ATmega328P.

The output register can be jumpered to display its result in one of three modes:

* hex (00 to ff)
* signed decimal (-128 to 127)
* unsigned decimal (0 to 255)

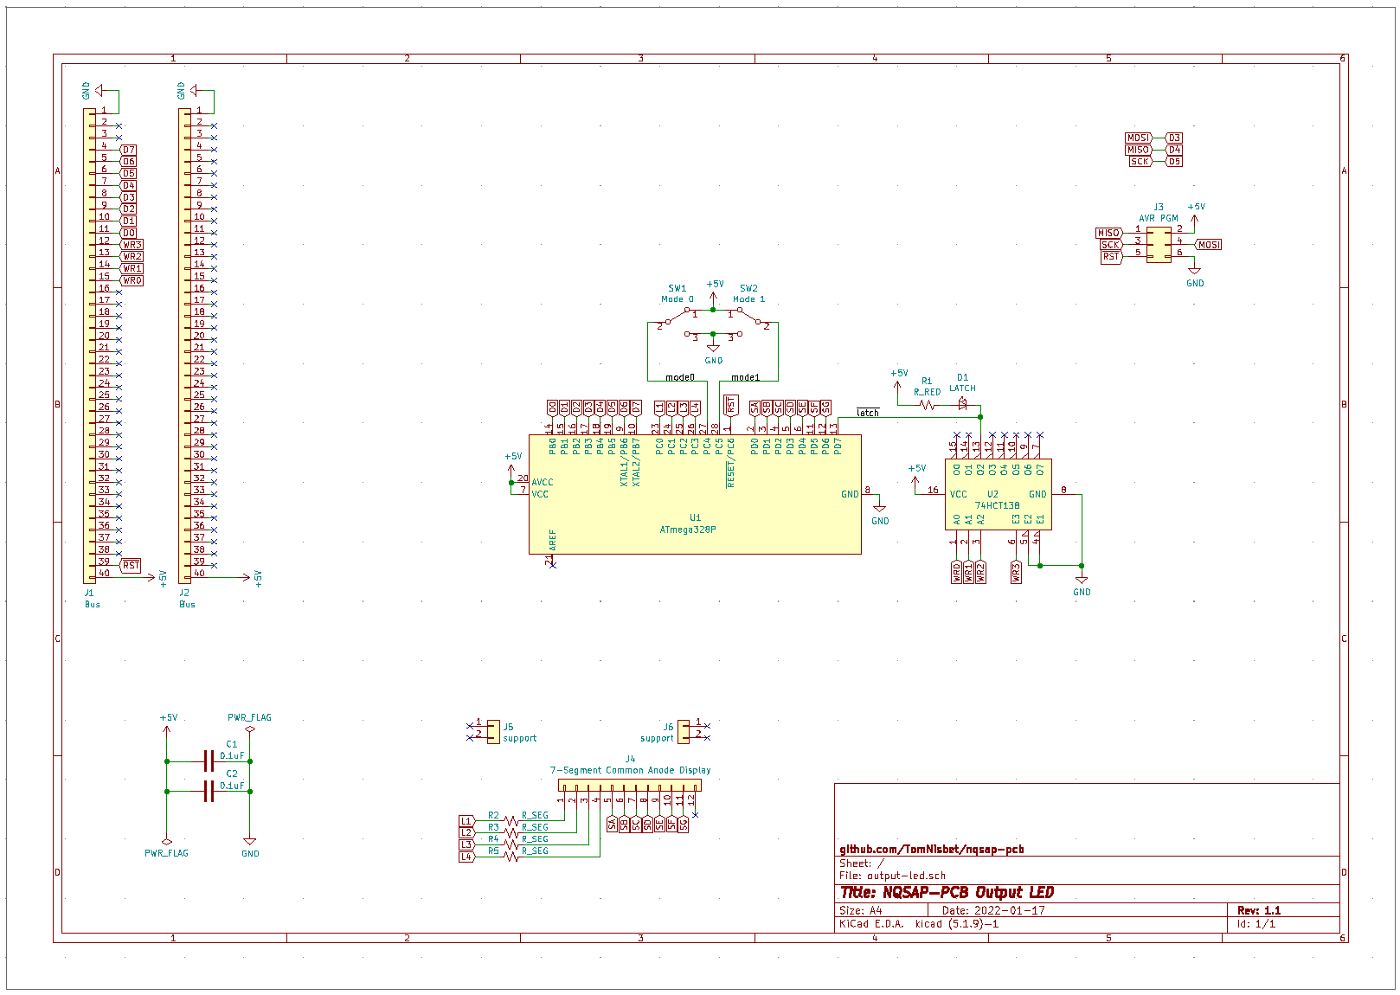
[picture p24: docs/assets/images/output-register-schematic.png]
Output Register Schematic output register


The output register hardware is exteremely minimal due to the use of segment multiplexing
instead of digit multiplexing.  The removes the need for transistors or other drivers so
that the complete hardware consists of just the Atmege328, the display, and four
resistors.

Because the design is useful outside of the NQSAP-PCB, the Output Register is documented
in its own repository.  The
[minimal-hardware 7 segment display](https://github.com/TomNisbet/minimal-hardware-7-segment-display)
repository has complete details, including source code.

It is a bit of a cheat for a TTL computer build to use a microcontroller that has vastly
more power than the entire resulting computer.  But the 328 version was an interesting
design exercise and it can be argued that the display is really more of a peripheral than
an integrated part of the computer.

## Bill of Materials

* ATmega328P microcontroller
* 74HCT138 3-to-8 decoder
* 4-digit, 7-segment LED display

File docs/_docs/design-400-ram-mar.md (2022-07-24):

---
title: "RAM and MAR"
permalink: /docs/ram-mar/
excerpt: "RAM and Memory Address Register (MAR) for the NQSAP-PCB computer"
---

RAM and MAR

The RAM provides 256 bytes of storage for programs and storage.  The Memory Address
Register (MAR) provides the 8-bit address. Two additional address lines from the microcode
can segment the RAM into separate areas for program, data, and stack storage to allow for
a total of 1K of storage.

RAM and MAR schematic

The RAM is implemented using a 32Kx8 bit static RAM.  Only a small portion of this is
used and the additional address lines are tied to ground.

The MAR is read-only, using a single 74HCT377 register.  The RAM uses a 32Kx8 static RAM
which is extreme overkill, since only 256 of the 32768 bytes are used.  But it is easy to
wire because it does not require a separate bus driver.

The 32K RAM chip is only using eight of the fifteen available address lines to access only
256 bytes of memory.  Two additional address lines from the microcode (M0 and M1) can
segment the RAM into separate areas for program, data, and stack storage to allow for a
total of 1K of storage.  Jumpers are used to connect the M0 and M1 lines to the RAM, so
the use of either of these features is optional.  This allows the RAM to be used as 256,
512, or 1024 bytes with separate or combined data/code and data/stack areas.  Because ROM
control lines are scarse in this design, the use of jumpers also lets the M0 and M1 lines
be used elsewhere to add new functionality.

This use of separate data and code areas would mean that the NQSAP-PCB would not support
self-modifying code because the register load and store operations would not be able to
access program storage.  This is another reason to use jumpers for the M0 and M1 selects.
Combined areas can be used if self-modifying code is desired and separate areas can be
used to maximize RAM for larger programs.

Note that the M0 and M1 jumpers allow for a total of four RAM areas.  In addition to data,
code, and stack, a fourth area could be defined by adding additional instructions in the
microcode.  This could be a second stack with its own push and pull instructions, or a
second data area with new register load and save instructions to access the new block.

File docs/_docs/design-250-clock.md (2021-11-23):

---
title: "System Clock"
permalink: /docs/clock/
excerpt: "System clock for the NQSAP-PCB computer"
---

System clock

The system clock and master reset circuits are co-located with the Loader/Debugger module.
board.  There was space on the board and it makes sense to co-locate these functions to
reduce the number of signals that need to be on the control bus.

System clock

## Clock implementation

The clock uses an NE556 dual-timer for the astable and one-shot clock pulses.  An S-R
latch is used for the run-stop switch debounce, rather than using a third timer as in the
Ben Eater design.  This could have been constructed from a pair of 2-input NAND or 2-input
NOR gates, but there was already a spare pair of 3-input gates available, so those were
used instead.

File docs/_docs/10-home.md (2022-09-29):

---
title: "NQSAP-PCB 8-bit TTL Computer"
permalink: /
excerpt: "NQSAP-PCB: PCB version of the Not Quite Simple As Possible computer"
---

NQSAP-PCB TTL computer NQSAP-PCB
The Not Quite Simple As Possible Computer - PCB version

NQSAP-PCB is the second iteration of the
[NQSAP breadboard TTL computer](https://tomnisbet.github.io/nqsap/).

Highlights of the design are:

* Modular [backplane](docs/backplane) and bus connectors, providing flexible arrangement
 of the computing boards to easily modify and extend the computer's functionality.
* [Arduino-based loader/debugger](docs/loader/) with full access to all data and microcode
control lines to load programs and run interactive diagnostics
* [74LS181 ALU](docs/alu) provides arithmetic and logic operations including add,
subtract, AND, OR, and XOR
* Four [flag registers](docs/flags) with hardware-based conditional jumps
* Double-buffered [Instruction Register](docs/ir-rc) to mitigate issues with control EEPROM output glitching
* [Instruction set](docs/in-summary) and addressing modes similar to the 6502.

Most of this design was prototyped in original
[NQSAP breadboard build](https://tomnisbet.github.io/nqsap/). Some of the enhancements
from that original design are:

* Loader design with shift registers now allows access to all microcode control lines
* Microcode ROM count reduced from 4 to 3 by combining some signals
* ALU shift register design replaced with a simple offset register for the right shift
operation
* Maximum number of microcode steps increased from 8 to 16
* RAM can now optionally address four different 256-byte blocks, allowing for separate
program, data, and stack areas.

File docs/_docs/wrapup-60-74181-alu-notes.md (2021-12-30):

---
title: "74181 ALU Notes"
permalink: /docs/74181-alu-notes/
excerpt: "74181 / 74LS181 Arithmetic Logic Unit (ALU) notes"
---

## Pitfalls
### A=B Bit

The _A=B_ bit does not detect that the A and B inputs are the same.  Instead, it is active
when all result bits are one. This can be used with the A minus 1 operation to detect
A==0, or with A-B-1 to detect A=B, but it is not useful for other operations. A bit that detects an all-zero result would seem to be more useful.

**NOTE:** The _A=B_ pin is wired as low or tri-state rather than low or high, so it will
never display anything if an LED is wired from _A=B_ to ground.  Instead, the state can
be observed by wiring an LED and resistor from Vcc to _A=B_ pin. See
<https://electronics.stackexchange.com/a/454342> for details.

### Conflicting datasheets

Several datasheets for the 74181 have errors or inconsistencies:
* The Texas Instruments 1988 datasheet appears to be correct
* The Fairchild 2000 datasheet has differences compared to the TI sheet
  * the _A and not B_ operation is incorrectly listed as _A and B_
  * the _not (A xor B)_ operation is listed as _not A xor not B_ (which would be the same
      as just _A xor B_)
* The Texas Instruments 1983 Databook shows the _A plus A_ operation as _A_

## Carry flag

The carry flag output (C<sub>n+4</sub>) is not a simple output that indicates overflow
for all arithmetic operations.  Instead, it outputs LOW for addition overflow and HIGH
for subtraction overflow.  While this seems confusing at first glance, it makes sense
when seen in the context of chaining multiple ALUs together to do operations on larger
word lengths.

For the purpose of this discussion, some terminology is defined here that is not in the 74181 datasheet:
* CIN, or carry in, refers to the C<sub>n</sub> pin of the ALU
* COUT, or carry out, refers to the C<sub>n+4</sub> pin of the ALU
* The "normal case" refers to an operation that does not cause a carry or borrow condition
* The "upper" and "lower" ALU refer to a case where two ALUs are wired together to do operations on 8 bits, where the lower ALU holds the least significant 4 bits and the upper ALU holds the most significant 4 bits

The CIN pin is active low.  When it is low, any arithmetic operation adds an additional 1
to the final result.

The table below shows five useful arithmetic operations that can be performed by the 74181
ALU.  By showing the CIN=1 and CIN=0 operations side by side, it is  easier to see how
operations are related so that two (or more) ALUs can be used together to work with more
than 4 bits.

| Selects|CIN=H Operation|CIN=L Operation|
|:---: |:---: |:---: |
| LLLL | A | **A + 1** |
| LHHL | A - B - 1 | **A - B** |
| HLLH | **A + B** | A + B + 1 |
| HHLL | **A + A** | A + A + 1 |
| HHHH | **A - 1** | A |
|====

When using more than one ALU, the Mode and Select bits are connected to the same sets of pins on all ALUs.  the COUT (C<sub>n+4</sub>) of the lower ALU is connected to
the CIN (C<sub>n</sub>) of the upper ALU.  The CIN of the lower ALU is used, along with
the Mode and Select bits, to select an operation to be performed.  The COUT of the upper
ALU can be used, with some interpretation, to indicate an overflow of the entire
operation.  

The examples below use two ALUs, but the principles are the same using any arbitrary
number of 74181s to achieve the desired bit width.  There may be delay issues when using
multiple ALUs, but those are beyond the scope of this discussion.  See the 74S182 Carry
Lookahead chip datasheets for details.

For the _A+B_ addition operation, the CIN of the lower ALU is not asserted.  Note that
this means it is in a HIGH state, because the CIN pin is active low. The COUT from the
lower ALU is also not asserted in the normal case where the result of the addition does
not cause an overflow out of the lower 4 bits.  The COUT of the lower ALU is connected to
the CIN of the upper ALU, so both ALUs will do an _A+B_ operation on their respective 4
bits of data.

In the case where the lower ALU addition overflows, the COUT connected to the upper ALU's
CIN is asserted, so the lower ALU will do an _A+B_ operation on its 4 bits, and the upper
ALU will do an _A+B+1_ operation on its 4 bits. This gives the desired result of the carry
from the overflow of the lower ALU cascading into the upper ALU.

The addition cases described above for _A+B_ are identical for the _A+A_ operation as
well.

For subtraction, the no-carry operation is _A-B-1_, but asserting the CIN bit gives an
_A-B_ operation.  This is why CIN must be asserted on the lower ALU for subtraction but
not for addition.  Similar to addition, the lower ALU asserts the same value on COUT as it
receives on CIN for the normal case, so the lower ALU and upper ALU will both perform an
_A-B_ operation on their respective 4 bits.

In the case where the subtraction in the lower ALU needs a borrow from the upper ALU, the
lower ALU will not assert the COUT signal, causing the upper ALU to perform an _A-B-1_
operation.  This effectively borrows a one from the upper ALU value.

From the above operations, it would seem like a carry/borrow bit to indicate 8-bit
overflow/underflow could be implemented by checking to see if the CIN to the lower ALU has
a different value than the COUT of the upper ALU.  This could be accomplished by just an
XOR of the two signals and would work for both the addition and subtraction case.
Unfortunately, the increment and decrement (_A+1_ and _A-1_) operations break this model.

For both addition and subtraction, the upper and lower ALUs perform the same operation in the normal case and perform different operations in the lower ALU overflow case.  The
increment and decrement functions behave differently.

Consider the case to increment the number 5, or 0000 0101 in binary.  The lower ALU will
perform an _A+1_ operation, but the upper ALU must perform an _A_ operation to leave the
upper 4 bits unchanged.  The result would be 6, or 0000 0110.  In this normal case, the
lower ALU will have CIN asserted and the upper ALU will not.  For the overflow case, such
as an increment of 0000 1111, both ALUs will have CIN asserted and will both do an _A+1_
operation, giving 0001 0000 as the result. The decrement operation is similar, with the
ALUs doing different operations in the normal case and the same operation in the lower ALU
overflow case.

The following tables summarize the usage of the carry bits for the 5 arithmetic operations.

The columns in the table represent these pins and conditions:
* Selects - function select bits S<sub>3</sub> to S<sub>0</sub>
* Upper ALU - function performed by lower ALU
* Lower ALU - function performed by upper ALU
* CIN<sub>U</sub> - CIN (C<sub>n</sub>) to upper ALU produced by COUT (C<sub>n+4</sub>) of lower ALU
* CIN<sub>L</sub> - CIN (C<sub>n</sub>) to lower ALU
* COUT<sub>UN</sub> - COUT (C<sub>n+4</sub>) from upper ALU in "normal" (non-overflow) case
* COUT<sub>UC</sub> - COUT (C<sub>n+4</sub>) from upper ALU in overflow case

This table shows the five operations in the normal case, when the lower ALU does not have
an overflow condition.

|Selects|Lower ALU|Upper ALU|CIN<sub>L</sub>|CIN<sub>U</sub>|COUT<sub>UN</sub>|COUT<sub>UC</sub>|
|:---: |:---: |:---: |:---:|:---:|:---:|:---:|
| LLLL | A + 1 | A |  L  |  H  |  H  |  L  |
| LHHL | A - B | A - B |  L  |  L  |  L  |  H  |
| HLLH | A + B | A + B |  H  |  H  |  H  |  L  |
| HHLL | A + A | A + A |  H  |  H  |  H  |  L  |
| HHHH | A - 1 | A |  H  |  L  |  L  |  H  |
|====

The next table shows the same five operations in the case when the lower ALU has an
overflow condition.  The only differences with the previous table are the upper ALU
operations that are produced by the different values produced by the COUT of the lower ALU
pin that is connected to the CIN of the upper ALU.

|Selects|Lower ALU|Upper ALU|CIN<sub>L</sub>|CIN<sub>U</sub>|COUT<sub>UN</sub>|COUT<sub>UC</sub>|
|:---: |:---: |:---: |:---:|:---:|:---:|:---:|
| LLLL | A + 1 | A + 1 |  L  |  L  |  H  |  L  |
| LHHL | A - B | A - B - 1 |  L  |  H  |  L  |  H  |
| HLLH | A + B | A + B + 1 |  H  |  L  |  H  |  L  |
| HHLL | A + A | A + A + 1 |  H  |  L  |  H  |  L  |
| HHHH | A - 1 | A - 1 |  H  |  H  |  L  |  H  |
|====

## Carry Flag Usage in 8-bit Microprocessors

To understand how the 74LS181 might be used, it is helpful to compare the use of the carry
flag with arithmetic operations of some real microprocessors.

The Z-80 and 8080/8085 have a Carry Flag for arithmetic operations.  This same flag is
sometimes referred to as the Borrow Flag for subtraction, but it is still just one
physical flag.

For addition with carry, the operation is A+B+C.  A cleared carry flag produces A+B and a
set carry flag produces A+B+1.  The carry bit is set if the result overflows into the
ninth bit.  For subtraction, the operation is A-B-C.  A cleared carry flag produces A-B
and a set carry flag produces A-B-1.  The carry flag is set if the result of the
subtraction borrows from the ninth bit.

The 6502 processor also has a single Carry Flag that is used for addition and subtraction
operations, but it functions differently than the Z-80/8080/8085.

Like the Z-80, the addition with carry the operation is A+B+C.  A cleared carry flag
produces A+B and a set carry flag produces A+B+1.  The carry flag is set if the result
overflows into the ninth bit.  

Subtraction on the 6502 is a bit different. The operation is A-B-(1-C), which can also be
written as A-B-1+C.  A cleared carry flag produces A-B-1 and a set carry flag produces
A-B.  The carry flag is cleared if the result of the subtraction borrows from the
ninth bit.

In both processors, the carry can be used to do multiple byte addition or subtraction
because the carry result produced by an operation is the result needed to do the operation
on the next byte of data.

The Z-80 model is easier to understand - a set carry flag always indicates a carry or
borrow from the operation.  The 6502 model is actually a better match for the 74LS181 ALU
because it uses different values of the carry bit depending on whether addition or
subtraction is performed.  The only complication is that interpretation of the carry bit
is inverted between the 6502 and the 74181.

## ALU Operations List

The following is a list of all possible operations of the ALU using a simplified syntax.
All operations are spelled out explicitly, like 'or' and 'plus' instead of '+' and 'plus'
as in the datasheets.

### Arithmetic
```
M Cn S3 S2 S1 S0
0  0  0  0  0  0  A plus 1
0  0  0  0  0  1  (A or B) plus 1
0  0  0  0  1  0  (A or not B) plus 1
0  0  0  0  1  1  zero   [all zeroes]
0  0  0  1  0  0  A plus (A and not B) plus 1
0  0  0  1  0  1  (A or B) plus (A and not B) plus 1
0  0  0  1  1  0  A minus B
0  0  0  1  1  1  A and not B
0  0  1  0  0  0  A plus (A and B) plus 1
0  0  1  0  0  1  A plus B plus 1
0  0  1  0  1  0  (A or not B) plus (A and B) plus 1
0  0  1  0  1  1  A and B
0  0  1  1  0  0  A plus A plus 1
0  0  1  1  0  1  (A or B) plus A plus 1
0  0  1  1  1  0  (A or not B) plus A plus 1
0  0  1  1  1  1  A
0  1  0  0  0  0  A
0  1  0  0  0  1  A or B
0  1  0  0  1  0  A or not B
0  1  0  0  1  1  negative 1   [all ones]
0  1  0  1  0  0  A plus (A and not B)
0  1  0  1  0  1  (A or B) plus (A and not B)
0  1  0  1  1  0  A minus B minus 1
0  1  0  1  1  1  (A and not B) minus 1
0  1  1  0  0  0  A plus (A and B)
0  1  1  0  0  1  A plus B
0  1  1  0  1  0  (A or not B) plus (A and B)
0  1  1  0  1  1  (A and B) minus 1
0  1  1  1  0  0  A plus A
0  1  1  1  0  1  (A or B) plus A
0  1  1  1  1  0  (A or not B) plus A
0  1  1  1  1  1  A minus 1
```

### Logic
```
M Cn S3 S2 S1 S0
1  x  0  0  0  0  not A
1  x  0  0  0  1  not A or not B
1  x  0  0  1  0  not A and B
1  x  0  0  1  1  0
1  x  0  1  0  0  not (A and B)
1  x  0  1  0  1  not B
1  x  0  1  1  0  A xor B
1  x  0  1  1  1  A and not B
1  x  1  0  0  0  not A or B
1  x  1  0  0  1  not (A xor B)
1  x  1  0  1  0  B
1  x  1  0  1  1  A and B
1  x  1  1  0  0  1
1  x  1  1  0  1  A or not B
1  x  1  1  1  0  A or B
1  x  1  1  1  1  A
```

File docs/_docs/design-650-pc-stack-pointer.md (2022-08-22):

---
title: "Program Counter and Stack Pointer"
permalink: /docs/program-counter-stack-pointer/
excerpt: "Building the stack pointer of the NQSAP computer"
---

Program Counter and Stack Pointer program counter and stack pointer build

The Program Counter and Stack Pointer module implements two unrelated resisters.  There
are no interconnections or dependencies between the PC and SP, so they are co-located only
because each design is simple and both could be implemented together on one board.  The
PC/SP board does not contain any register select hardware, so the read and write selects
for the PC and SP are provided over the interconnects from the
[RAM/MAR board](../ram-mar).

Program Counter and Stack Pointer Schematic program counter and stack pointer

## Program Counter

The Program Counter (PC) is implemented using two 74HCT161 4-bit counters.  It increments
on any clock cycle that has the Program Increment (PI) signal asserted.  The PC is loaded
with a new value when either the Write Program (WP) signal or the conditional JMP signal
is low. The WP signal is produced by the register selects to perform an unconditional jump.
The JMP signal is produced by the [Flags Module](../flags).

## Stack Pointer

The stack pointer (SP) is an 8-bit register with read/write access to the bus.  It enables
new instructions to push and pull registers (PHA, PLA) and to call and return from
subroutines (JSR, RTS).  There are also instructions to load the SP to and from the X
register using the TXS and TSX instructions.  If no stack operations are needed, the SP
can also be used as a general-purpose register.

The SP is implemented using a pair of 74HCT193 4-bit up/down counters.  Output to the bus
is controlled via the usual 74LS245 bus transceiver.

The CLR signal is not used to reset the counter at system reset so the SP always starts in
an unknown state.  This isn't a problem, because any programs that use the SP will want to
initialize it to point to a free memory area before any stack operations are performed.

Unlike the 74HCT161, the 74HCT193 counters do not have a master clock or a count enable
control.  Counting is performed by pulsing the UP or DOWN pins and loading a new value is
performed by pulsing the LOAD signal.  Additional logic is used to AND these signals with
the master system clock.  To load a new value, the CLK and WS signals are combined.

Spare bus and microcode signals are in short supply.  Rather than adding two new signals
for the SP count up and down operations, a single Stack Enable (SE) signal was added.
This is used in conjunction with the C0 and C1 carry control signals to control counting
in the SP. The SE and C0 signals are asserted to count down and the SE and C1 signals are
used to count up.  These are combined with the CLK signal to produce the pulses for the
DOWN and UP lines.

The shared use of the C0 and C1 signals means that the carry flag cannot be modified in
the same microinstruction step where the SP is counting.  The normal use of the C0 and C1
signals will not cause the SP to count because the SE signal will not be asserted.  Note
that the C0 and C1 signals will also be shared by the XY registers, so SP and indexing
operations also cannot happen in a single microinstruction step.

## Microcode

The SP counts up when pushing values to the stack and counts down when pulling values.
There is no overflow protection, so the counter will quietly wrap if it hits the top
or bottom of memory.  The push operation uses a post-increment, so the value is stored and
then the SP is bumped to point to the next available stack address.  In other words, the
SP always points to the address after the location of the value on the top of the stack.
The pull operations pre-decrement, so the SP is moved to point to the value and then the
value is retrieved.

Note that the Jump to Subroutine (JSR) uses a few tricks in the microcode.  The value of
the PC is needed to retrieve the subroutine address, but the PC also needs to be saved
onto the stack before being overwritten with the new address.  The ALU B register is used
for temporary storage to save the subroutine address.  The B register is not directly
accessible by the user, so it is a good candidate for the microcode to use.  The example
below shows a JSR instruction at memory address 20.

| Address | Contents |
|:---: | :--- |
| 20 | JSR opcode  |
| 21 | JSR address |
| 22 | next opcode |
|====

After the instruction fetch, the PC will have the value 21 and JSR microcode performs the
following steps:

1. move the PC value to the MAR and increment the PC.  MAR contains 21 and PC contains 22.
1. read the subroutine address from RAM[21] and place it in B for temp storage
1. move the SP value into the MAR and increment the SP.
1. store the PC value (which points to the next instruction) in memory, i.e. push the JSR return address on the stack.
1. move the B register value into the PC, effectively jumping to the subroutine

Note that the B register is needed because the PC value that is pushed to the stack is the
one address after the location that hold the subroutine address.  If the PC value was
incremented and pushed before fetching the subroutine address, there would be no way to
fetch the address because the PC has already moved past it.

An alternate approach that would not require temporary storage would be to push the PC
while it was still pointing to the subroutine address instead of pointing to the next
opcode. The RTS instruction would then need to increment the PC after fetching it from the
stack. The downside to this is that the PC address on the stack would not be the true
return address.

## Bill of Materials

* 74HCT00 quad 2-input NAND gate(1)
* 74HCT10 triple 3-input NAND(1)
* 74LS161 4-bit counter (2)
* 74LS193 4-bit up/down counter (2)
* 74HCT245 8-bit bus transceiver (2)

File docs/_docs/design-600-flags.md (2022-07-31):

---
title: "Flags and Conditional Jumps"
permalink: /docs/flags/
excerpt: "Building the flags and conditional jump logic of the NQSAP computer"
---

Flags Design flags and jump logic

The processor status flags and conditional jump logic is the most complex part of the
NQSAP computer.  It consumes a large number of the available
[microcode ROM outputs](#control-rom-summary).

The flags and conditional jump design has the following features:
* Four flags that match the behavior of the 6502's Carry, Zero, oVerflow, and Negative flags
* Hardware-controlled conditional jump instructions require no ROM address lines
* An instruction's microcode can alter any or all of the flags independently
* Flags can be read or written to the bus, allowing save and restore of the processor status

## Differences from SAP-1

The Ben Eater SAP-1 supports two flags, Zero and Carry, using a single 74HCT173 register to
store the values.  This means that any instruction that alters flags needs to provide a
value for both flags.  The conditional jump logic of SAP-1 design is implemented in
microcode by wiring the status flag register outputs to address lines of the microcode
ROMs.  

The NQSAP design addresses the following SAP-1 limitations:
* Flags cannot be set independently
* Limited number of ROM address lines available to expand to more flags
* Changing flag values causes the control ROM outputs to briefly glitch to unknown values

## Hardware overview

Flags Schematic flags and jump logic

The left side of the schematic contains logic to calculate values input to the flags based
on the ALU and other sources.  The 74HCT157 selector in the center allows the flags to be
loaded from the calculation hardware or loaded from the value on the bus.  The flag values
are stored in the pair of 74HCT74 flip flops in the center of the drawing. On the right
side of the schematic, the outputs of the flags go to a 74HCT245 that allows them to be
placed on the bus.  The outputs also go to a 74HCT151 8-to-1 selector that controls the
conditional jump.

The NQSAP-PCB data bus is used as an input for flag calculations on the left side of the
drawing, a direct input to the flag registers in the center, and an output source for the
flags on the right.

The star of this design is the 74HCT151 8-to-1 selector.  It is used to replace conditional
logic for the Carry and oVerflow flag calculations and also to select a flag source for
the conditional jump.

## Flag registers

Each of the four flags is stored in its own D flip flop rather than a single register chip
for all flags.  This is implemented as a pair of 74HCT74 dual D flip flops.  Each flag has
its own Flag Load (FC,FZ,FV,FN) signal from the Control ROMs that is ANDed with the master
clock (CLK) to load new data into a flag register.  This allows selective updating of
only the flags that are appropriate for each instruction.  For example, the Add with Carry
(ADC) instruction sets all four flags, but the Increment Memory (INC) sets only the Zero
and Negative flags.

The outputs of the flag registers go to the conditional jump circuit and also to a
74HCT245 8-bit transceiver that is connected to the bus.  This allows the all of the flag
bits to be read as a single byte of processor status on the bus.  This capability is used
by the Push Processor Status (PSP) instruction to save flag values to memory.

The inputs to the flag registers are connected to a 74HCT157 quad 2-to-1 selector.  This
selects from either the bus or the individual flag calculation hardware as the source when
loading new values into the flags.  The Pull Processor Status (PLP) instruction uses the
bus read capability to restore previously saved values of the flags.

## Setting and clearing

The Reset inputs of the flag registers are tied to the master reset (RST) signal so that
the flags are all cleared at reset.  The Set inputs are not used.

The CLC, CLV, and SEC instructions clear or set individual flags.  This requires no
additional hardware or ROM control signals.  The NQSAP's ALU has modes that will output
all-ones or all-zeros to the bus, regardless of the ALU inputs.  The flag registers can be
loaded from the bus, so putting zeroes on the bus and then selectively loading individual
flags allows instructions to clear flags.  Similarly, flags are set using the ALU all-ones
and loading from the bus.

## Conditional jump

The conditional jump determination is done in hardware, with a circuit that drives the
LOAD enable of the Program Counter (PC).  Unlike the SAP-1, the flag values are not
connected to address lines in the Control ROM and the microcode cannot execute differently
dependent on flag values.  The choice was made to allow for more flags, because ROM
address lines are in short supply.  The other benefit is reduced
[EEPROM output glitching](../eeprom-glitch) because changes in flags don't cause a new
address to be set on the microcode ROM in the middle of an instruction execution.

The inverted and non-inverted values of the four flags are fed into the inputs of a
74HCT151 8-to-1 selector.  Because the flip flops provide both Q and not-Q outputs, the
selector can choose to jump on a flag set or flag clear value with no additional inverters
or gates needed.  The active-low JMP output of the selector drives the LOAD line of the
PC.  The enable line of the selector is controlled by the Conditional Jump Enable (JE)
signal from the microcode ROM.  If the JE signal is not asserted then the values at the
selector inputs are ignored and the PC LOAD is not enabled.

Before going to the PC LOAD input, the output of the conditional jump selector is NORed
with the Write PC (WP) signal from the register selectors.  This allows the control ROM to
do an unconditional jump and it also allows the Loader to do self-tests on the PC.

The three select inputs that determine the flag for the conditional jump are tied to the
three least significant output bits of the Instruction Register (IR).  This encodes the
flag selection into the opcode of the conditional jump instructions and does not require
any additional control lines from the Control ROM.  It also simplifies the microcode
because all of the conditional jump instructions will have identical microcode.  This is
similar to the operation selection for the ALU, which uses the upper five bits of the
opcode to select an ALU function so that ALU instructions with the same addressing mode
shared common microcode.

Note that the Instruction Register bits for the conditional jump select are provided by
the ALU module over the module interconnect lines.

All conditional jump instructions are coded as unconditional jumps in the ROM with the JE
signal asserted.  If the selected flag (or the selected inverted flag) is not HIGH, the
jump steps are executed but the LOAD line will not go active and the instruction will have
no effect.  

The downside to this is that a jump not taken will effectively be a long NOP instruction,
using more cycles than other approaches might need.  It might be possible for the
conditional jump logic to drive the Next Instruction (N) signal instead of the PC LOAD
signal, allowing a flag condition to terminate a jump instruction early.

## Flag calculations

The Negative flag is simply the MSB of the data bus.  Because it is wired to the bus
instead of the ALU output, the Negative flag can be updated on non-ALU  operations such as
register to register transfers or shift register instructions.

The Zero flag uses a 74HCT688 8-bit comparator to test for zero.  This saves a chip over
the AND/OR circuit used in the Ben Eater SAP-1 computer but is functionally equivalent.
One other difference from the SAP-1 is that the zero test, like the negative test, is
performed on the value on the bus instead of the output value of the ALU.

The oVerflow flag is calculated using a 74HCT151 8-to-1 selector as described in
[74181 with V_Flag](http://6502.org/users/dieter/v_flag/v_4.htm) on 6502.org.  The MSB of
the ALU operands in H and B, as well as the MSB of the ALU result, are used as inputs.
Two of the ALU operation select lines are used to differentiate between addition and
subtraction.

The Carry flag has several inputs that can set it.  For arithmetic operations, it uses the
carry output or the inverted carry output of the 74HCT181 ALU chip.  For shift right
operations, it is set by the LSB of the B register.  A 74HCT151 chooses from the
different inputs as selected by the C0 and C1 bits from the control ROMs.

Any or all of the flags can also be loaded from the bus.  This allows for a "pull flags"
instruction to restore the set of flags.  This capability is also leveraged for the
individual flag set and clear instructions, like CLC, CLV, and SEC.  The ALU chip has an
operation that puts all ones on the bus and another that puts out all zeroes.  By putting
the ALU in one of these modes and enabling individual flag load lines, a flag can be set
or cleared by the microcode.

## Carry Flag usage by the ALU and H Register

In addition to its use in the conditional jump instructions, the Carry flag output is also
used as an input to the ALU (L) and the sHift (H) Register.  Depending on the operation,
the carry supplied to the ALU and H registers can be either a hard-coded one or zero, the
value of the Carry flag, or the inverted value of the Carry flag.  The inversion is needed
because the Carry flag uses positive logic, with a one indicating a carry is present, but
the ALU uses negative logic, where a zero indicates that a carry should be used in the
operation being performed.  

Two control signals from the ROM are used to force the carry flag output HIGH or LOW or
just pass it through unchanged.  The initial design used three different types of gates,
but applying De Morgan to the AND gate simplified the design to just two NOR gates.  The
two versions of the circuit are shown below.

Carry Flag Output carry flag output logic

The table below shows the usage of the carry flag for each instruction.

| Operation|Register|Input to Register|Input to Carry Flag|
|:---: |:---: |:---: |:---: |
| ADC | ALU | ~C | ~ALU-carry-out |
| ASL | H | 0 | ~ALU-carry-out |
| DEC | ALU | 1 | flag not changed  |
| INC | ALU | 0 | flag not changed  |
| LSR | H | 0 | B-Q<sub>0</sub> |
| ROL | H | C | ~ALU-carry-out |
| ROR | H | C | B-Q<sub>0</sub> |
| SBC | ALU | ~C | ~ALU-carry-out |
|====

The input to the Carry flag is described in the [Flag Calculations](#flag-calculations)
section.  

The output of the Carry flag to the ALU and H register is controlled by the CC and CS
lines from the Control ROM.  These two lines can force a clear or set value or just pass
through the current value of the Carry flag.  Note that the ALU uses negative logic for
the carry flag, so the inverted value of the Carry flag is used.  The inverter is placed
after the CC and CS logic, so asserting CS will present a LOW to the ALU and CC will
present a HIGH to the ALU.

## Control ROM summary

The table below shows the Control ROM lines related to flags.

|Signal|Description |
|:---: |:--- |
| FC | write Carry flag |
| FZ | write Zero flag |
| FV | write oVerflow flag |
| FN | write Negative flag |
| FB | load flags from the bus|
| JC | jump conditional |
| C0 | carry source select 0  |
| C1 | carry source select 1  |
| LC | ALU carry input clear  |
| LC | ALU carry input clear  |
|====

## Bill of materials

* 74HCT02 quad 2-input NOR gate (1)
* 74HCT08 quad 2-input AND gate (1)
* 74HCT75 dual D flip flop (2)
* 74HCT151 8-to-1 selector (1)
* 74HCT157 quad 2-to-1 selector (1)
* 74HCT245 8-bit bus transceiver (1)

## Other References

[Question for all 74ls181 alu people](https://www.reddit.com/r/beneater/comments/kmuuex/question_for_all_74ls181_alu_people)
on reddit led to the design of the oVerflow flag.

[How to add a decremental and incremental circuit to the ALU ?](https://www.reddit.com/r/beneater/comments/jwxke0/how_to_add_a_decremental_and_incremental_circuit/)
on reddit inspired the idea to drive the PC load line from the flags instead of running
the flags through the microcode.

[Opcodes and Flag decoding circuit](https://www.reddit.com/r/beneater/comments/m76ijz/opcodes_and_flag_decoding_circuit/)
on reddit has a different approach to conditional jumps using hardware.  Instead of
driving the LOAD line of the PC, the circuit sits between the Instruction Register and the
ROM and conditionally jams a NOP or JMP instruction to the microcode depending on the
state of the flags.  One interesting part of the design is that the opcodes of the jump
instructions are arranged so that the flag of interest can be determined by bits from the
IR.  NQSAP already did something similar with the ALU select lines, so the concept was
used again for the conditional jump select lines.

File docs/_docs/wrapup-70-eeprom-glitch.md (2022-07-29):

---
title: "EEPROM Glitch"
permalink: /docs/eeprom-glitch/
excerpt: "Issues when using EEPROMs to produce control signals"
---

EEPROMs are a straightforward and convenient way to produce the system control signals.
Microcode is stored in EEPROMs with the Step Counter (Ring Counter) and Instruction
Register values driving the EEPROM address lines and the EEPROM data outputs providing the
system control signals.  However, there is an important property of EEPROM operation that
causes problems.

## The EEPROM "glitch"

When the address lines on an EEPROM are changed, there is a settling period before the
outputs show the data value at the associated address.  During this time, the outputs are
still being driven (they are not floating), but it is not known if they will be in a high
state or a low state.  For example, if the bytes at address 4 and address 5 both contain a
zero bit for pin D0, the pin could still briefly produce a one value when the address is
changed from 4 to 5.  Although this is a normal property of memory chips, it causes issues
because of the way the chips are used in TTL computer builds.  The problem has been
referred to as EEPROM glitching.

Unpredictable signals from the Microcode EEPROM can cause spurious signals to be
generated.  For example, if multiple register read lines are active at once, it will cause
brief bus contention.  If the signals are combined with other logic to generate clocks for
other chips, then spurious clock pulses could be generated.

## Instruction cycle

The [WaveDrom](https://wavedrom.com) timing diagram below shows the first four clock
cycles for an instruction in the SAP-1 and NQSAP computers.  The Ring Counter value
changes on every falling clock edge and the Instruction Register value changes on the
rising edge of instruction step 1 (T1).  Both of these events change the address
inputs to the EEPROMs and cause a brief period of uncertainty for all of the control
outputs.  In addition, the SAP-1 also drives address lines with the outputs of the Flags
Register, so this causes uncertainty on any rising edge that modifies the flags.

Instruction cycle timing cycle timing showing EEPROM glitch

For the SAP-1 design, these output glitches are not usually a problem.
Many of the instruction steps in the SAP-1 designs move values from one register to
another.  The SAP-1 uses 74LS173 registers to read and store values from the bus and
74LS245 tranceivers to put values on the bus. For example, the T0 step of every instruction
moves the contents of the Program Counter (PC) to the Memory Address Register (MAR).  
The timing diagram below shows the Program Counter Out (CO) and MAR In (MI) lines.

Move PC to MAR timing cycle timing to move PC to MAR

The following steps take place during the first instruction step:
* At marker 1, the Ring Counter is set to zero on the falling edge of CLK
* The Control EEPROM address is set to the T0 instruction cycle
* The CO and MI signals are asserted after briefly being in an unknown state while the EEPROM settles
* The CO signal places the contents of the PC on the bus
* At marker 3, the rising CLK edge, along with the MI signal, causes the PC value on the bus to be loaded into the MAR

The glitching of the MI signal does not cause any problems because the 74LS173 registers
only load new values when the Load Enable signal is asserted and the clock is at a rising edge.  The signals are always in a known state at the rising CLK edge.

## Issues when generating clock signals

Unlike the 74LS173 registers, some chips do not have two independent lines for Load Enable
and CLK.  Instead, a single pin is pulsed and the chip loads when a clock pulse edge is
detected.  Examples in the NQSAP-PCB design are the static RAM, the 74HCT193 counters used
by the Stack Pointer, and the 74HCT74 flip flops used to store the flags. For these chips,
a clock signal is generated by ANDing a control signal with the system clock.  This
produces a pulse whenever the signal is asserted and the CLK is high.  

The timing diagram below shows a control clock pulse being generated in instruction
cycle T3.  The control signal is asserted at marker 13 and the clock pulse begins at
marker 15.  

Instruction cycle with control clock cycle timing with control clock

Note that the signal uncertaintly at marker 13 does not cause a problem because the clock
signal is still low at that point, so the state of the control signal does not matter.  Similarly, none of the other EEPROM glitching on the falling edge of the clock causes
an issue.

The EEPROM glitch behavior does cause a problem in instruction step T1 at marker 7.
This is the point where the Instruction Register is loaded, and that causes the EEPROM
address to change on the positive edge of the system clock.  With the CLK signal high,
any glitch on the control line will produce one or more brief control clock pulses that
could cause their register to idadvertantly load a value from the bus.  

In the SAP-1 design, the flag outputs also drive microcode EEPROM address lines to do
conditional jumps, so the glitch would also be a problem after the rising edge clock of
any instruction step that loads new flag values.

## Mitigating the glitch with analog solutions

Several analog solutions have been proposed to mitigate the EEPROM glitching in TTL
computer builds.  One approach is to add low-pass filters to the control lines to
eliminate the high frequency spikes that occur during the EEPROM address switching.

Another solution is to use pull-up or pull-down resistors on the control lines.
Because the lines are not floating during the glitch period, this does not actually
pull the signals to a desired state.  Instead, it just flattens the rise or fall time of
the signal a bit.  If the period of the glitch is short enough, this may cause the
glitch pulse to never cross a logic threshold that would make other hardware act on it.

## NQSAP-PCB design to avoid the glitch

The NQSAP-PCB solves the EEPROM glitch in the digital domain by making changes
to the design of the conditional jumps and the Instruction Register.  The
[conditional jumps](../flags#conditional-jump) are performed completly in hardware, without the use of separate microcode for
the flag set and flag clear conditions.  Because the flags are not wired to the EEPROM
address lines, changing flag values does not cause any glitches.

The Instruction Register uses a double-buffered design to move the address line changes to
the falling edge of the clock pulse.  The IR is loaded as usual on the positive edge of
the clock in T1.  The outputs of this register are connected to the inputs of a second
register which is loaded on every falling clock pulse.  The outputs of this second
register are used to drive the address lines of the EEPROM.  The result is that the
address lines driven by the IR now change on the falling edge of instruction cycle T1, at
the same time as the address lines driven by the Ring Counter.  With these two design
changes, the outputs of the microcode EEPROMs are always stable when the clock is high, so
they can safely be used with rising clock edges or ANDed with the clock signal.

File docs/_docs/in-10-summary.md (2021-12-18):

---
title: "NQSAP and 6502 Instructions"
permalink: /docs/in-summary/
excerpt: "Instruction set summary for the NQSAP Computer"
---

## 6502 Compatibility

The NQSAP has a 6502-inspired architecture and instruction set.  The instructions and
registers are similar, but the opcodes of the NQSAP do not map to the same values as
a 6502.  This means that the NQSAP and 6502 are somewhat compatible at the assembly
language source level, but the object code they use is completely different.

The major difference in the two implementations is that the NQSAP is an 8-bit only machine
with no 16-bit addressing modes.  This means that the absolute addressing modes and the
zero-page addressing modes are the same because all memory is in page zero.  For
simplicity of the documentation, the instructions are listed as using absolute,
absolute+X, and absolute+Y modes instead of the zero-page modes.

Two other features of the 6502 are also not implemented: decimal mode and interrupts.
This removes a few instructions from the complete set.

One interesting difference between the two implementations is the branch instructions.
On the 6502, these use fewer cycles than an unconditional jump instruction because they
only need to specify a single byte offset instead of a two byte absolute or relative
address.  On the NQSAP, the branch instructions are expensive because they need to save
and restore one of the index registers in order to calculate relative addresses.  A set
of conditional jump instructions was added that mimics all of the conditional branches
but uses absolute addressing instead of relative addressing.  These jumps use only four
cycles instead of the eight needed for a conditional branch.

## Instructions Common to 6502 and NQSAP

|Name|Description|Flags|Address Modes|
|:---|:---|:---:|:---|
|[ADC](../in-details#adc)|Add with Carry|CZVN|IM,AB,AX,AY,IX,IY|
|[AND](../in-details#and)|Logical AND|-Z-N|IM,AB,AX,AY,IX,IY|
|[ASL](../in-details#asl)|Arithmetic Shift Left|CZ-N|AA,AB,AX|
|[BCC](../in-details#bcc)|Branch if Carry Clear|----|RE|
|[BCS](../in-details#bcs)|Branch if Carry Set|----|RE|
|[BEQ](../in-details#beq)|Branch if Equal|----|RE|
|[BIT](../in-details#bit)|Bit Test|-Z--|AB|
|[BMI](../in-details#bmi)|Branch if Minus|----|RE|
|[BNE](../in-details#bne)|Branch if Not Equal|----|RE|
|[BPL](../in-details#bpl)|Branch if Positive|----|RE|
|[BVC](../in-details#bvc)|Branch if Overflow Clear|----|RE|
|[BVS](../in-details#bvs)|Branch if Overflow Set|----|RE|
|[CLC](../in-details#clc)|Clear Carry|C---|IP|
|[CLV](../in-details#clv)|Clear Overflow|--V-|IP|
|[CMP](../in-details#cmp)|Compare A|CZ-N|IM,AB,AX,AY,IX,IY|
|[CPX](../in-details#cpx)|Compare X|CZ-N|IM,AB|
|[CPY](../in-details#cpy)|Compare Y|CZ-N|IM,AB|
|[DEC](../in-details#dec)|Decrement Memory|-Z-N|AB,AX|
|[DEX](../in-details#dex)|Decrement X|-Z-N|IP|
|[DEY](../in-details#dey)|Decrement Y|-Z-N|IP|
|[EOR](../in-details#eor)|Exclusive OR|-Z-N|IM,AB,AX,AY,IX,IY|
|[INC](../in-details#inc)|Increment Memory|-Z-N|AB,AX|
|[INX](../in-details#inx)|Increment X|-Z-N|IP|
|[INY](../in-details#iny)|Increment Y|-Z-N|IP|
|[JMP](../in-details#jmp)|Jump|----|AB,IN|
|[JSR](../in-details#jsr)|Jump to Subroutine|----|AB|
|[LDA](../in-details#lda)|Load A|-Z-N|IM,AB,AX,AY,IX,IY|
|[LDX](../in-details#ldx)|Load X|-Z-N|IM,AB,AY|
|[LDY](../in-details#ldy)|Load Y|-Z-N|IM,AB,AX|
|[LSR](../in-details#lsr)|Logical Shift Right|CZ-N|AA,AB,AX|
|[NOP](../in-details#nop)|No Operation|----|IP|
|[ORA](../in-details#ora)|Logical Inclusive OR|-Z-N|IM,AB,AX,AY,IX,IY|
|[PHA](../in-details#pha)|Push A|----|IP|
|[PHP](../in-details#php)|Push Processor Status|----|IP|
|[PLA](../in-details#pla)|Pull A|-Z-N|IP|
|[PLP](../in-details#plp)|Pull Processor Status|CZVN|IP|
|[ROL](../in-details#rol)|Rotate Left|CZ-N|AA,AB,AX|
|[ROR](../in-details#ror)|Rotate Right|CZ-N|AA,AB,AX|
|[RTS](../in-details#rts)|Return from Subroutine|----|IP|
|[SBC](../in-details#sbc)|Subtract with Carry|CZVN|IM,AB,AX,AY,IX,IY|
|[SEC](../in-details#sec)|Set Carry|C---|IP|
|[STA](../in-details#sta)|Store A|----|AB,AX,AY,IX,IY|
|[STX](../in-details#stx)|Store X|----|AB,AY|
|[STY](../in-details#sty)|Store Y|----|AB,AX|
|[TAX](../in-details#tax)|Transfer A to X|-Z-N|IP|
|[TAY](../in-details#tay)|Transfer A to Y|-Z-N|IP|
|[TSX](../in-details#tsx)|Transfer SP to X|-Z-N|IP|
|[TXA](../in-details#txa)|Transfer X to A|-Z-N|IP|
|[TXS](../in-details#txs)|Transfer X to SP|----|IP|
|[TYA](../in-details#tya)|Transfer Y to A|-Z-N|IP|

## 6502 Instructions Not Implemented in NQSAP

|Name|Description|Flags|Address Modes|
|:---|:---|:---:|:---|
|[BRK](../in-details#brk)<sub>1</sub>|Force Interrupt|----||
|[CLD](../in-details#cld)<sub>2</sub>|Clear Decimal Mode|----||
|[CLI](../in-details#cli)<sub>1</sub>|Clear Interrupt Disable|----||
|[RTI](../in-details#rti)<sub>1</sub>|Return from Interrupt|----||
|[SED](../in-details#sed)<sub>2</sub>|Set Decimal Mode|----||
|[SEI](../in-details#sei)<sub>1</sub>|Set interrupt Disable|----||

**Notes:**
1. No support for interrupts
1. No support for decimal mode

## NQSAP Extensions

|Name|Description|Flags|Address Modes|
|:---|:---|:---:|:---|
|[DEA](../in-details#dea)|Decrement A|-Z-N|AA|
|[INA](../in-details#ina)|Increment A|-Z-N|AA|
|[JCC](../in-details#jcc)|Jump if Carry Clear|----|AB|
|[JCS](../in-details#jcs)|Jump if Carry Set|----|AB|
|[JEQ](../in-details#jeq)|Jump if Equal|----|AB|
|[JMI](../in-details#jmi)|Jump if Minus|----|AB|
|[JNE](../in-details#jne)|Jump if Not Equal|----|AB|
|[JPL](../in-details#jpl)|Jump if Positive|----|AB|
|[JVC](../in-details#jvc)|Jump if Overflow Clear|----|AB|
|[JVS](../in-details#jvs)|Jump if Overflow Set|----|AB|
|[NOT](../in-details#not)|Bitwise NOT A|-Z-N|AA|
|[OUT](../in-details#out)|Output A|----|IP|

*this file was generated by nqsap-instructions.py at 17-Dec-2021 21:15:08*

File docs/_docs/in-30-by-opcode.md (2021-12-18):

---
title: "NQSAP Instructions by Opcode"
permalink: /docs/in-by-opcode/
excerpt: "NQSAP Computer Instruction set by opcode"
---

## NQSAP Instructions by Opcode

| |  x0  |  x1  |  x2  |  x3  |  x4  |  x5  |  x6  |  x7  |  x8  |  x9  |  xa  |  xb  |  xc  |  xd  |  xe  |  xf  |
|:---: |:---: |:---: |:---: |:---: |:---: |:---: |:---: |:---: |:---: |:---: |:---: |:---: |:---: |:---: |:---: |:---: |
|**0x**|[IP_NOP](../in-details#nop)|[**AA_INA**](../in-details#ina)|[**AB_INC**](../in-details#inc)|[**AX_INC**](../in-details#inc)| |[**IP_INX**](../in-details#inx)|[**IP_INY**](../in-details#iny)| |[**AA_NOT**](../in-details#not)| | | | | | | |
|**1x**|[IP_OUT](../in-details#out)|[IM_LDA](../in-details#lda)|[AB_LDA](../in-details#lda)|[AX_LDA](../in-details#lda)|[AY_LDA](../in-details#lda)|[IX_LDA](../in-details#lda)|[IY_LDA](../in-details#lda)| | |[IM_LDX](../in-details#ldx)|[AB_LDX](../in-details#ldx)|[IP_TAX](../in-details#tax)|[AY_LDX](../in-details#ldx)|[IP_TSX](../in-details#tsx)| | |
|**2x**| | |[AB_STA](../in-details#sta)|[AX_STA](../in-details#sta)|[AY_STA](../in-details#sta)|[IX_STA](../in-details#sta)|[IY_STA](../in-details#sta)| | | |[AB_STX](../in-details#stx)|[IP_TXA](../in-details#txa)|[AY_STX](../in-details#stx)|[IP_TXS](../in-details#txs)| | |
|**3x**|[**IP_CLC**](../in-details#clc)|[**IP_SEC**](../in-details#sec)|[**IP_CLV**](../in-details#clv)| | | | | | |[IM_LDY](../in-details#ldy)|[AB_LDY](../in-details#ldy)|[AX_LDY](../in-details#ldy)|[IP_TAY](../in-details#tay)| | | |
|**4x**| | | | | | | | | | |[AB_STY](../in-details#sty)|[AX_STY](../in-details#sty)|[IP_TYA](../in-details#tya)| | | |
|**5x**| | | | | | | | | | | | | | | | |
|**6x**|[**IM_CPX**](../in-details#cpx)|[**IM_SBC**](../in-details#sbc)|[**AB_SBC**](../in-details#sbc)|[**AX_SBC**](../in-details#sbc)|[**AY_SBC**](../in-details#sbc)|[**IX_SBC**](../in-details#sbc)|[**IY_SBC**](../in-details#sbc)|[**AB_CPX**](../in-details#cpx)|[IP_PHA](../in-details#pha)|[**IM_EOR**](../in-details#eor)|[**AB_EOR**](../in-details#eor)|[**AX_EOR**](../in-details#eor)|[**AY_EOR**](../in-details#eor)|[**IX_EOR**](../in-details#eor)|[**IY_EOR**](../in-details#eor)| |
|**7x**|[**IM_CPY**](../in-details#cpy)|[**IM_CMP**](../in-details#cmp)|[**AB_CMP**](../in-details#cmp)|[**AX_CMP**](../in-details#cmp)|[**AY_CMP**](../in-details#cmp)|[**IX_CMP**](../in-details#cmp)|[**IY_CMP**](../in-details#cmp)|[**AB_CPY**](../in-details#cpy)| | | | | | | | |
|**8x**| | | | | | | | | | | | | | | | |
|**9x**|[IP_PHP](../in-details#php)|[**IM_ADC**](../in-details#adc)|[**AB_ADC**](../in-details#adc)|[**AX_ADC**](../in-details#adc)|[**AY_ADC**](../in-details#adc)|[**IX_ADC**](../in-details#adc)|[**IY_ADC**](../in-details#adc)| | | | | | | | | |
|**ax**|[IP_RTS](../in-details#rts)| |[AB_JSR](../in-details#jsr)| | | | | | | | | | | | | |
|**bx**|[IN_JMP](../in-details#jmp)| |[AB_JMP](../in-details#jmp)| | | | | |[**AB_BIT**](../in-details#bit)|[**IM_AND**](../in-details#and)|[**AB_AND**](../in-details#and)|[**AX_AND**](../in-details#and)|[**AY_AND**](../in-details#and)|[**IX_AND**](../in-details#and)|[**IY_AND**](../in-details#and)| |
|**cx**|[**AA_ASL**](../in-details#asl)| |[**AB_ASL**](../in-details#asl)|[**AX_ASL**](../in-details#asl)|[**AA_ROL**](../in-details#rol)| |[**AB_ROL**](../in-details#rol)|[**AX_ROL**](../in-details#rol)|[RE_BCS](../in-details#bcs)|[RE_BCC](../in-details#bcc)|[RE_BEQ](../in-details#beq)|[RE_BNE](../in-details#bne)|[RE_BVS](../in-details#bvs)|[RE_BVC](../in-details#bvc)|[RE_BMI](../in-details#bmi)|[RE_BPL](../in-details#bpl)|
|**dx**|[AA_LSR](../in-details#lsr)| |[AB_LSR](../in-details#lsr)|[AX_LSR](../in-details#lsr)|[AA_ROR](../in-details#ror)| |[AB_ROR](../in-details#ror)|[AX_ROR](../in-details#ror)|[AB_JCS](../in-details#jcs)|[AB_JCC](../in-details#jcc)|[AB_JEQ](../in-details#jeq)|[AB_JNE](../in-details#jne)|[AB_JVS](../in-details#jvs)|[AB_JVC](../in-details#jvc)|[AB_JMI](../in-details#jmi)|[AB_JPL](../in-details#jpl)|
|**ex**| | | | | | | | |[IP_PLA](../in-details#pla)|[**IM_ORA**](../in-details#ora)|[**AB_ORA**](../in-details#ora)|[**AX_ORA**](../in-details#ora)|[**AY_ORA**](../in-details#ora)|[**IX_ORA**](../in-details#ora)|[**IY_ORA**](../in-details#ora)| |
|**fx**|[IP_PLP](../in-details#plp)|[**AA_DEA**](../in-details#dea)|[**AB_DEC**](../in-details#dec)|[**AX_DEC**](../in-details#dec)| |[**IP_DEX**](../in-details#dex)|[**IP_DEY**](../in-details#dey)| | | | | | | | | |

*this file was generated by nqsap-instructions.py at 17-Dec-2021 21:15:08*

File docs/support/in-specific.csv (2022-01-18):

Instance | Opcode | Description | ALU | Bytes | Cycles | Bold
IP_NOP | 0x00 | no operation | n | 1 | 3
AA_INA | 0x01 | increment A | y | 1 | 3
AB_INC | 0x02 | increment memory | y | 2 | 7
AX_INC | 0x03 | increment memory | y | 2 | 8
IP_INX | 0x05 | increment X | y | 1 | 6
IP_INY | 0x06 | increment Y | y | 1 | 6
AA_NOT | 0x08 | NOT A | y | 1 | 3
IP_OUT | 0x10 | output A | n | 1 | 3
IM_LDA | 0x11 | load immediate to A | n | 2 | 4
AB_LDA | 0x12 | load A from memory | n | 2 | 5
AX_LDA | 0x13 | load A from memory | n | 2 | 6
AY_LDA | 0x14 | load A from memory | n | 2 | 6
IX_LDA | 0x15 | load A from memory | n | 2 | 7
IY_LDA | 0x16 | load A from memory | n | 2 | 7
IM_LDX | 0x19 | load immediate to X | n | 2 | 4 | y
AB_LDX | 0x1a | load X from memory | n | 2 | 5 | y
IP_TAX | 0x1b | transfer A to X | n | 1 | 3 | y
AY_LDX | 0x1c | load X from memory | n | 2 | 6 | y
IP_TSX | 0x1d | transfer SP to X | n | 1 | 3 | y
AB_STA | 0x22 | store A to memory | n | 2 | 5
AX_STA | 0x23 | store A to memory | n | 2 | 6
AY_STA | 0x24 | store A to memory | n | 2 | 6
IX_STA | 0x25 | store A to memory | n | 2 | 7
IY_STA | 0x26 | store A to memory | n | 2 | 7
AB_STX | 0x2a | store X to memory | n | 2 | 5 | y
IP_TXA | 0x2b | transfer X to A | n | 1 | 3 | y
AY_STX | 0x2c | store X to memory | n | 2 | 6 | y
IP_TXS | 0x2d | transfer X to SP | n | 1 | 3 | y
IP_CLC | 0x30 | clear carry flag | y | 1 | 3 | y
IP_SEC | 0x31 | set carry flag | y | 1 | 3 | y
IP_CLV | 0x32 | clear overflow flag | y | 1 | 3 | y
IM_LDY | 0x39 | load immediate to Y | n | 2 | 4 | y
AB_LDY | 0x3a | load Y from memory | n | 2 | 5 | y
AX_LDY | 0x3b | load Y from memory | n | 2 | 6 | y
IP_TAY | 0x3c | transfer A to Y | n | 1 | 3 | y
AB_STY | 0x4a | store Y to memory | n | 2 | 5 | y
AX_STY | 0x4b | store Y to memory | n | 2 | 6 | y
IP_TYA | 0x4c | transfer Y to A | n | 1 | 3 | y
IM_CPX | 0x60 | compare X immediate | y | 2 | 7 | y
IM_SBC | 0x61 | subtract with carry | y | 2 | 5
AB_SBC | 0x62 | subtract with carry memory | y | 2 | 6
AX_SBC | 0x63 | subtract with carry memory | y | 2 | 7
AY_SBC | 0x64 | subtract with carry memory | y | 2 | 7
IX_SBC | 0x65 | subtract with carry memory | y | 2 | 8
IY_SBC | 0x66 | subtract with carry memory | y | 2 | 8
AB_CPX | 0x67 | compare X | y | 2 | 8 | y
IP_PHA | 0x68 | push A | n | 1 | 4
IM_EOR | 0x69 | exlcusive OR A | y | 2 | 5
AB_EOR | 0x6a | exlcusive OR A | y | 2 | 6
AX_EOR | 0x6b | exlcusive OR A | y | 2 | 7
AY_EOR | 0x6c | exlcusive OR A | y | 2 | 7
IX_EOR | 0x6d | exlcusive OR A | y | 2 | 8
IY_EOR | 0x6e | exlcusive OR A | y | 2 | 8
IM_CPY | 0x70 | compare Y immediate | y | 2 | 7 | y
IM_CMP | 0x71 | compare A immediate | y | 2 | 5 | y
AB_CMP | 0x72 | compare A | y | 2 | 6 | y
AX_CMP | 0x73 | compare A | y | 2 | 7 | y
AY_CMP | 0x74 | compare A | y | 2 | 7 | y
IX_CMP | 0x75 | compare A | y | 2 | 8 | y
IY_CMP | 0x76 | compare A | y | 2 | 8 | y
AB_CPY | 0x77 | compare Y | y | 2 | 8 | y
IP_PHP | 0x90 | push PS | n | 1 | 4 | y
IM_ADC | 0x91 | add with carry A | y | 2 | 5
AB_ADC | 0x92 | add with carry memory | y | 2 | 6
AX_ADC | 0x93 | add with carry memory | y | 2 | 7
AY_ADC | 0x94 | add with carry memory | y | 2 | 7
IX_ADC | 0x95 | add with carry memory | y | 2 | 8
IY_ADC | 0x96 | add with carry memory | y | 2 | 8
IP_RTS | 0xa0 | return from subroutine | n | 1 | 5
AB_JSR | 0xa2 | jump to subroutine | n | 2 | 7
IN_JMP | 0xb0 | jump | n | 2 | 5
AB_JMP | 0xb2 | jump | n | 2 | 4
AB_BIT | 0xb8 | bit test A with memory | y | 2 | 5
IM_AND | 0xb9 | AND A | y | 2 | 5
AB_AND | 0xba | AND A | y | 2 | 6
AX_AND | 0xbb | AND A | y | 2 | 7
AY_AND | 0xbc | AND A | y | 2 | 7
IX_AND | 0xbd | AND A | y | 2 | 8
IY_AND | 0xbe | AND A | y | 2 | 8
AA_ASL | 0xc0 | arithmetic shift left A | y | 1 | 4
AB_ASL | 0xc2 | arithmetic shift left memory | y | 1 | 8
AX_ASL | 0xc3 | arithmetic shift left memory | y | 1 | 9
AA_ROL | 0xc4 | rotate left thru carry | y | 1 | 4
AB_ROL | 0xc6 | rotate left thru carry memory | y | 2 | 8
AX_ROL | 0xc7 | rotate left thru carry memory | y | 2 | 9
RE_BCS | 0xc8 | branch if carry set | n | 2 | 8 | y
RE_BCC | 0xc9 | branch if carry clear | n | 2 | 8 | y
RE_BEQ | 0xca | branch if equal (zero set) | n | 2 | 8 | y
RE_BNE | 0xcb | branch if not equal (zero clear) | n | 2 | 8 | y
RE_BVS | 0xcc | branch if overflow set | n | 2 | 8 | y
RE_BVC | 0xcd | branch if overflow clear | n | 2 | 8 | y
RE_BMI | 0xce | branch if minus (negative set) | n | 2 | 8 | y
RE_BPL | 0xcf | branch if plus (negative clear) | n | 2 | 8 | y
AA_LSR | 0xd0 | logical shift right A | n | 1 | 4
AB_LSR | 0xd2 | logical shift right memory | n | 2 | 6
AX_LSR | 0xd3 | logical shift right memory | n | 2 | 7
AA_ROR | 0xd4 | rotate right thru carry | n | 1 | 4
AB_ROR | 0xd6 | rotate right thru carry memory | n | 2 | 6
AX_ROR | 0xd7 | rotate right thru carry memory | n | 2 | 7
AB_JCS | 0xd8 | jump if carry set | n | 2 | 4 | y
AB_JCC | 0xd9 | jump if carry clear | n | 2 | 4 | y
AB_JEQ | 0xda | jump if equal (zero set) | n | 2 | 4 | y
AB_JNE | 0xdb | jump if not equal (zero clear) | n | 2 | 4 | y
AB_JVS | 0xdc | jump if overflow set | n | 2 | 4 | y
AB_JVC | 0xdd | jump if overflow clear | n | 2 | 4 | y
AB_JMI | 0xde | jump if minus (negative set) | n | 2 | 4 | y
AB_JPL | 0xdf | jump if plus (negative clear) | n | 2 | 4 | y
IP_PLA | 0xe8 | pull A | n | 1 | 5
IM_ORA | 0xe9 | OR A | y | 2 | 5
AB_ORA | 0xea | OR A | y | 2 | 6
AX_ORA | 0xeb | OR A | y | 2 | 7
AY_ORA | 0xec | OR A | y | 2 | 7
IX_ORA | 0xed | OR A | y | 2 | 8
IY_ORA | 0xee | OR A | y | 2 | 8
IP_PLP | 0xf0 | pull PS | n | 1 | 5 | y
AA_DEA | 0xf1 | decrement A | y | 1 | 3
AB_DEC | 0xf2 | decrement memory | y | 2 | 7
AX_DEC | 0xf3 | decrement memory | y | 1 | 8
IP_DEX | 0xf5 | decrement X | y | 1 | 6
IP_DEY | 0xf6 | decrement Y | y | 1 | 6

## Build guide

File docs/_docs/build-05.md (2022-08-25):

---
title: "Build 5"
permalink: /docs/build-05/
excerpt: "NQSAP-PCB computer build 5"
---

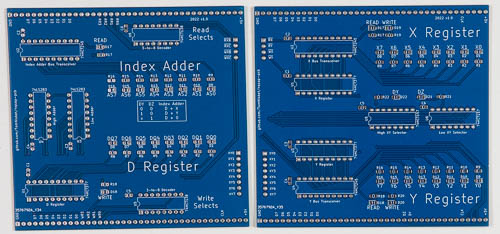
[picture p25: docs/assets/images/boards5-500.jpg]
Fifth set of boards


The fifth batch of boards contained the first boards for the Index Adder and the XY
registers.  Updated versions of the PC/SP board and the Output register were also included
to address minor errors.  A new ALU board was also done to add more status LEDs.

The eleven boards from the five builds can be assembled to form a Turing-complete 8-bit
CPU with many of the [instructions and addressing modes of a 6502 processor](../in-summary).

## X and Y Register and Index Adder

X and Y registers XY registers and index adder

The [XY Registers and Index Adder](../dxy-registers/) boards passed all self tests and ran
test programs with no issues.  The design of these was similar to the original NQSAP
breadboard build, but the functionality was split between two modules to accomodate the
LEDs needed to display three registers and the adder output.

## Program Counter and Stack Pointer

The swapped count enable pins were fixed on the [Program Counter](../program-counter-stack-pointer/)
and the module now works without the need for repair wires.

### Output Register

The missing enable pins on the [Output Register](../output-register/) boards were fixed
and the new boards worked as expected.

## Results

Fifth set running fifth set of boards

This shows the NQSAP-PCB with all of the boards from the first five builds. A fourth
backplane was added to hold the new XY and Index Adder modules.  This now leaves a module
slot empty - another opportunity!

The Arduino Loader is not active and the system is running a simple program that counts
and saves and restores values from the stack.

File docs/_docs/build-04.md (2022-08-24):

---
title: "Build 4"
permalink: /docs/build-04/
excerpt: "NQSAP-PCB computer build 4"
---

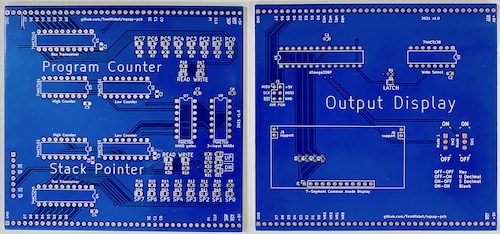
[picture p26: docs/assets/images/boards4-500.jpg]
Fourth set of boards


The fourth batch of boards contained the first boards for the Program Counter / Stack
Pointer and the LED Output Display.  The nine boards from the first four builds can be
assembled to form a Turing-complete 8-bit CPU.  One additional build is planned to add
the DXY Register functionality from the original breadboard NQSAP computer.

## Program Counter and Stack Pointer

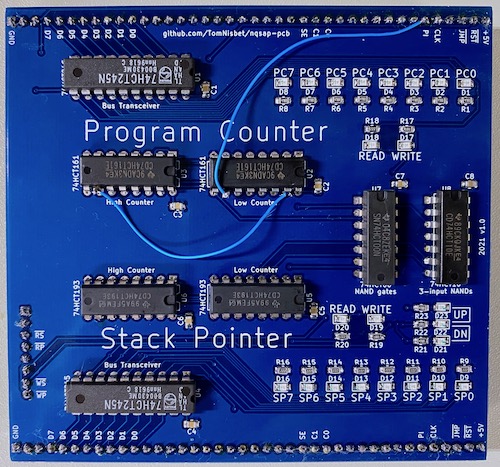
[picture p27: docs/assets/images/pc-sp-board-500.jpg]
Program Counter and Stack Pointer program counter / stack pointer


The [Program Counter and Stack Pointer](../program-counter-stack-pointer/) boards passed
the register load test, but the Program Counter (PC) would not count correctly.  The
Program Increment (PI) signal was mistakenly wired to the high counter and the carry out
from that counter was wired to the carry in of the low counter.  After a few wires to swap
the signals between the two chips, the PC passed all tests.

### Output Register

Despite the simple design, the [Output Register](../output-register/) boards
had one clumsy mistake.  Two enable pins on the 74HCT138 were left unconnected.  A simple
patch wire was added to ground these pins and then the board worked as expected.

## Results

Fourth set running fourth set of boards

This shows the NQSAP-PCB with all of the boards from the first four builds. The new PC/SP
board is in the upper right and the new Output Register is upper left.  The Arduino Loader
is not active and the system is running a simple program that counts and saves and
restores values from the stack.

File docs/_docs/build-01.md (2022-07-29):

---
title: "Build 1"
permalink: /docs/build-01/
excerpt: "NQSAP-PCB computer build 1"
---

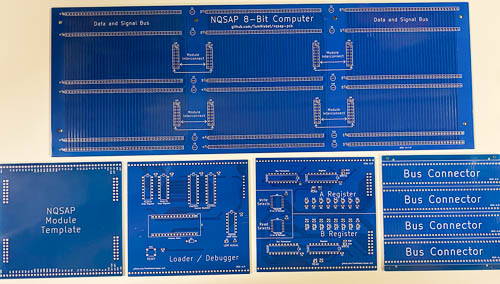
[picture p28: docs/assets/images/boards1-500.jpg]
Initial build initial NQSAP-PCB build


The goal of the initial order of boards was to verify the overall physical and electrical
design.  The backplane and interconnect boards were designed, along with a few other
boards to verify fit and basic functionality.

### Backplane and Interconnects

No errors were discovered with the [backplane boards](../backplane/).  This was fortunate,
because these were the most expensive to manufacture.  All of the interconnect and module
board connections fit perfectly.

The Bus Interconnect boards functioned as designed, but there was some missing silkscreen
text that will require a 1.1 version to fix.

### Loader

The version 1.0 [Loader board](../loader/) worked as designed and was able to test
operation of the backplane and the A/B registers.  While writing the Loader software, a
bus contention issue was discovered that required a hardware change.  In addition, the
design needed to use two different types of registers for the control signals.  

A new design was developed for a version 2.0 board that corrects the bus issue and
replaces the four register chips with three shift registers instead.  This had the added
advantage of simpler wiring and fewer Arduino pins used.

### A and B Registers

The [A and B registers](../ab-registers/) functioned as designed with no changes required.

A new version will be created when the ALU is completed.  This version will add a second
output bus transceiver to the B register to implement a right-shift operation.  

The original AB Register board mistakenly used a wide SIOC-16 footprint for the 74HCT138
selectors.  This required the sourcing of some obscure parts to complete the build.  The
next version will use a more common footprint, either DIP or SOIC, for the parts.

### Template Boards

A blank module board was created to serve as a layout template for all module boards.  A
set of these boards was included in the first board build.  A populated template board was
used as a guide when soldering connections onto backplane boards.  

A second template was assembled using longer pin connectors.  By inserting this template
board in place of a module and then using the top pins for breadboard connections,
temporary boards can be created that can be plugged in and removed from the system while
keeping all of the bus connections to the breadboard intact.

## Results

Initial build initial NQSAP-PCB build

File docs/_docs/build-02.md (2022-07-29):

---
title: "Build 2"
permalink: /docs/build-02/
excerpt: "NQSAP-PCB computer build 2"
---

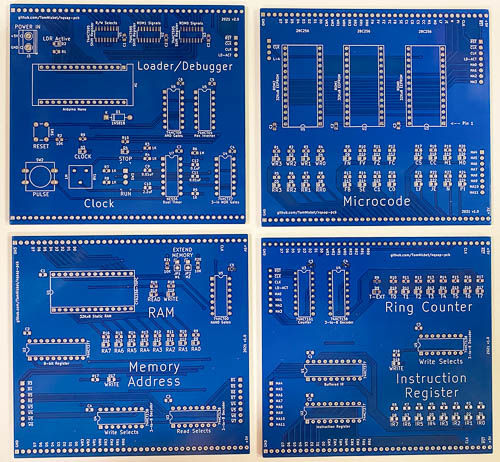
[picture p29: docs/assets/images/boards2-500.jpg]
Second set of boards


The second batch of boards contained a new Loader/Debugger as well as the first boards for
the microcode ROMs, Instruction Register/Ring Counter, and RAM/MAR.  These boards were
chosen for the second build because they form the core of the control circuitry.  The
addition of a program counter would allow a fully-functional, although somewhat boring,
computer. The next build will include the ALU and flags to round out the functionality.

### Loader plus Clock and Reset

The new [Loader](../loader/) functioned as designed.  The Arduino software from the V1
board was simplified to use the new shift register scheme.

### Microcode ROMs

The LED portion of the [Microcode module](../microcode/) was assembled early to help
verify operation of the Loader and other modules.  The actual ROMs were added later and
their operation was checked with the Loader/debugger.

### Instruction Register and Ring Counter

The dream of a perfect build ended with the [IR-RC](../ir-rc/) board.  This one had two minor
problems that will be fixed with a new board update.  

The first problem was the T-EXT LED wired to Vcc instead of ground.  The temporary fix was
to install the LED backwards, causing it to display the inverted signal.

The second problem is that the Ring Counter requires an inverted N signal from the bus.
The Loader was providing some inverted signals over the module interconnects, but this one
was not included.  As a temporary fix, the load input to the ring counter was wired to an
unused bus line where it can be manually set or wired to an external inverter.  The next
version of the board will add a hex inverter to produce the needed signals locally.

### RAM and MAR

The [RAM and MAR](../ram-mar/) module worked as designed and was verified by the self test
routines on the Loader/Debugger.  The timing of this test will need to be adjusted because
the Loader's new shift register design is slower that the previous parallel register
design. Most of the tests have timing delays built-in to allow visual observation of the
test, so these will be shortened appropriately.

## Results

Second set self test second set of boards

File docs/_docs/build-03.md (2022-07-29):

---
title: "Build 3"
permalink: /docs/build-03/
excerpt: "NQSAP-PCB computer build 3"
---

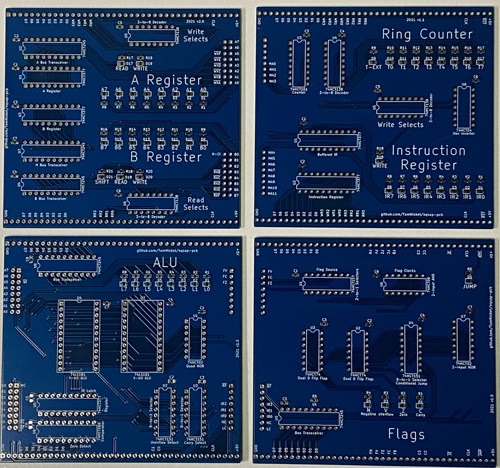
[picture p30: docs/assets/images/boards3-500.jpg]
Third set of boards


The third batch of boards contained an updated A/B Register module, an updated IR/RC
module, and the first boards for the ALU and Flags modules. The ALU and flags round out
the functionality and allow for programs that actually perform calculations and do
conditional jumps.

### Instruction Register and Ring Counter

The updated v1.1 [IR-RC](../ir-rc/) board fixes two minor problems from the initial board.
The T-EXT LED is now correctly wired so that it lights to indicate that the Ring Counter
is executing the extended microcode steps 8 to 15.

The new board also adds a onboard hex inverter to invert The CLK and N control signals for
its use. The inverted CLK was originaly created by the Loader module and passed through
the Microcode module on the interconnect bus.

### A/B Registers

The original [A and B Registers](../ab-registers/) functioned as designed, but a v2.0
board was designed for this build to add new functionality.  The new version adds a
virtual shift register (register H) output from the B register.  When selected, this
outputs the contents of the B register shifted one place to the right.  The LSB of B is
shifted into the Carry flag.  The MSB of the H register is the current contents of the
Carry flag, although it can also be forced to zero using the CC bit from the microcode.
This register is used for the LSR and ROR instructions.  Note that left shift instructions
(ASL and ROL) don't require a shift register because they can be produced by the ALU's A+A
operation.  Note also that H is not actually a register, it is just a second bus
transceiver that reads to contents of the B register.

The new A/B Register module also swapped out the hard-to-find SOP-16 74HCT138s for
standard DIP-16 packages.

The v2.0 board worked as designed with no changes required. The Loader's self test code
was updated to add a new test for the shift register.

### ALU

The [ALU board](../alu/) functioned as designed with no errors found.  This board also
contains the flag detection circuits for the Zero, Carry, and oVeflow flags.  

On thing that was overlooked for this board was the addition of LEDs to indicate status.
At a minimum, it should have a READ indicator when the ALU results are being output to the
bus.  Indicators for the flag detection would be helpful as well.  By themselves, these
missing features probably don't warrant a new spin of the board, but should be added if a
new version is built for any other reason.

### Flags and Jump Control

The [Flags board](../flags/) functioned as designed with no errors found.  This
functionality was never fully working on the original breadboard NQSAP, so it was a nice
surprise that it didn't need any follow-up debugging for the PCB version.

The Flags board also contains logic to produce the conditional jump signal for the
Program Counter.  The Loader's self test code was updated with several new tests:
* load and store of the flags to the bus
* program counter conditional jump for all flag value combinations
* flag register values as the result of all ALU operations

Like the ALU module, the Flags module should have had additional LED indicators.  At a
minumum, a READ signal should be present to show when the flag bits are being read to the
bus.

## Results

Third set self test third set of boards

This shows the NQSAP-PCB with the ALU and Flags boards from the third build, as well as a
prototyped Program Counter (upper right) and a proof-of-concept Stack Pointer (upper
left). The Arduino Loader is not active and the system is running a simple program that
loads a sequence of values into the A register.

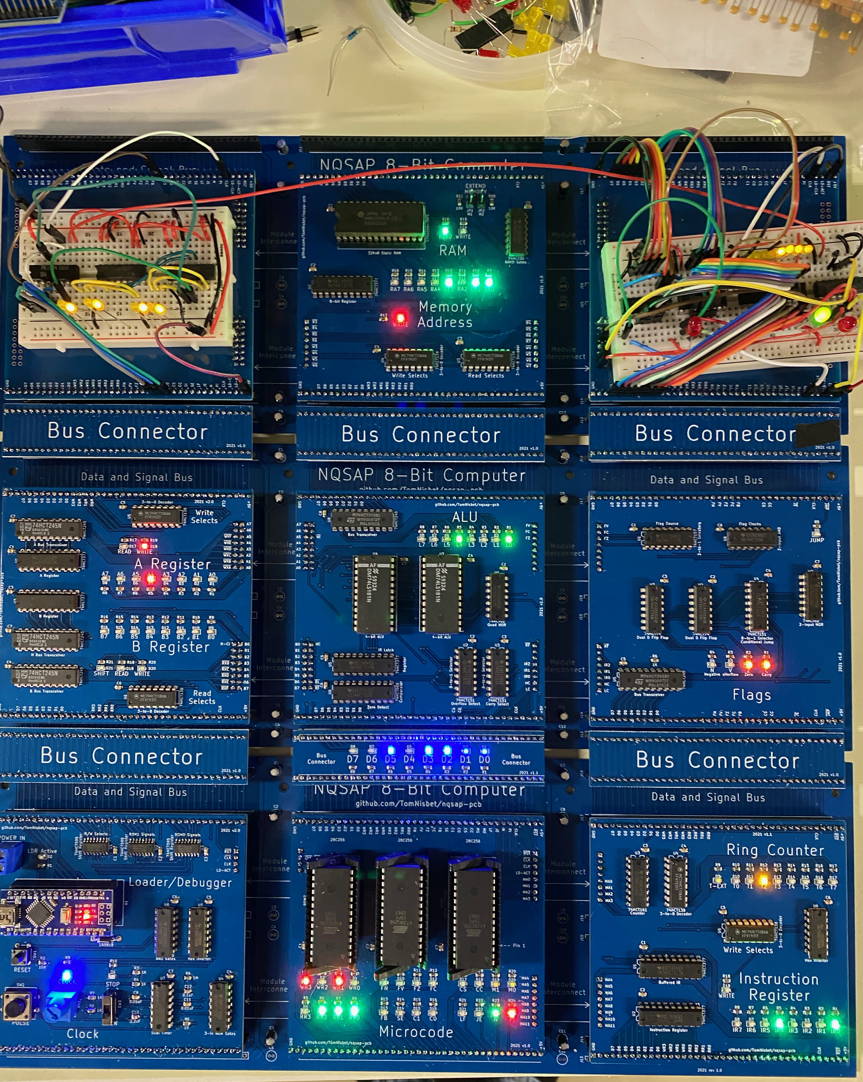
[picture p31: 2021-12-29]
docs/assets/images/build3.jpg

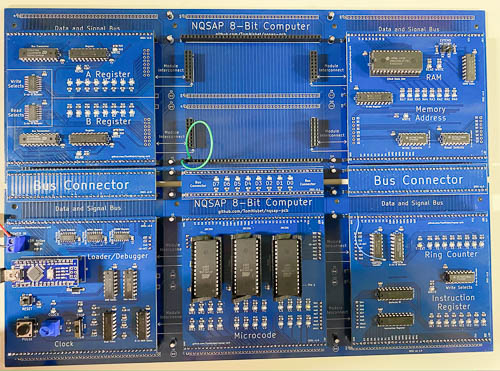
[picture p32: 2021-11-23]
docs/assets/images/build2-500.jpg

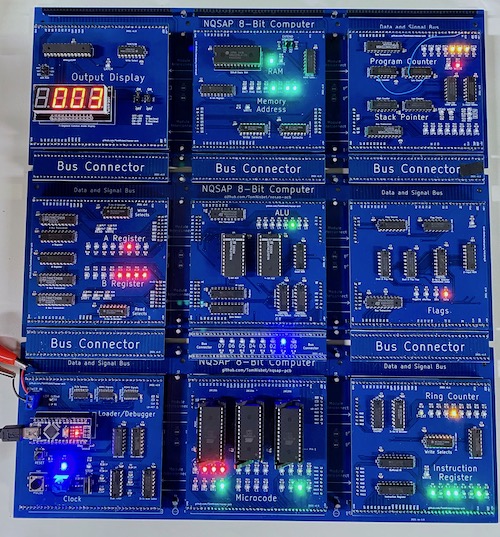
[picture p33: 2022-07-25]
docs/assets/images/build4-500.jpg

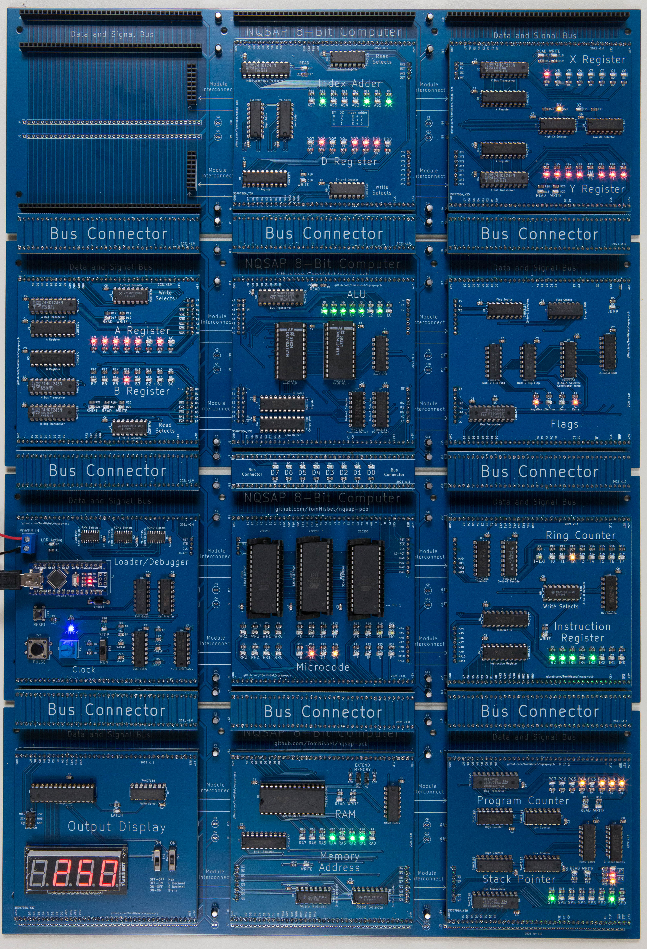
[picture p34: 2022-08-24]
docs/assets/images/build5.jpg

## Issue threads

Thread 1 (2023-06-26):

Not Programming

kpennel, 2023-06-26:
I get this when programming with the nqsap-pcb arduino microcode.

Burning NQSAP microcode version 6.0
0  burning 0 - Address Mode 0
burnBlock fail at 0x70
addr=0070, data=02, readback=ff
Write FAILED

The programmer works fine the with the arduino microcode for the original nqsap.

TomNisbet, 2023-06-28:
The actual burn code for both NQSAP and NQSAP-PCB should be identical.  Is it consistently failing, or does it work if you try it a few times?

It should be well within spec, but you could try changing mMaxWriteTime at line 926.  Maybe bump it up to 15.

Also, in the burnBlock code at line 1010, try enabling and disabling the chip outside of the enable and disable of the write enable.  So it would read:
```
        delayMicroseconds(1);
        enableChip();
        enableWrite();
        delayMicroseconds(1);
        disableWrite();
        disableChip();
```
What is the part number of the EEPROM chip you are using?

kpennel, 2023-06-28:
The part I am trying to program is an Atmel AT28C256 15PC. It programmed with the original code. I verified it with a TL866 programmer. I will try the changes you suggested today. Thank you for your quick response.

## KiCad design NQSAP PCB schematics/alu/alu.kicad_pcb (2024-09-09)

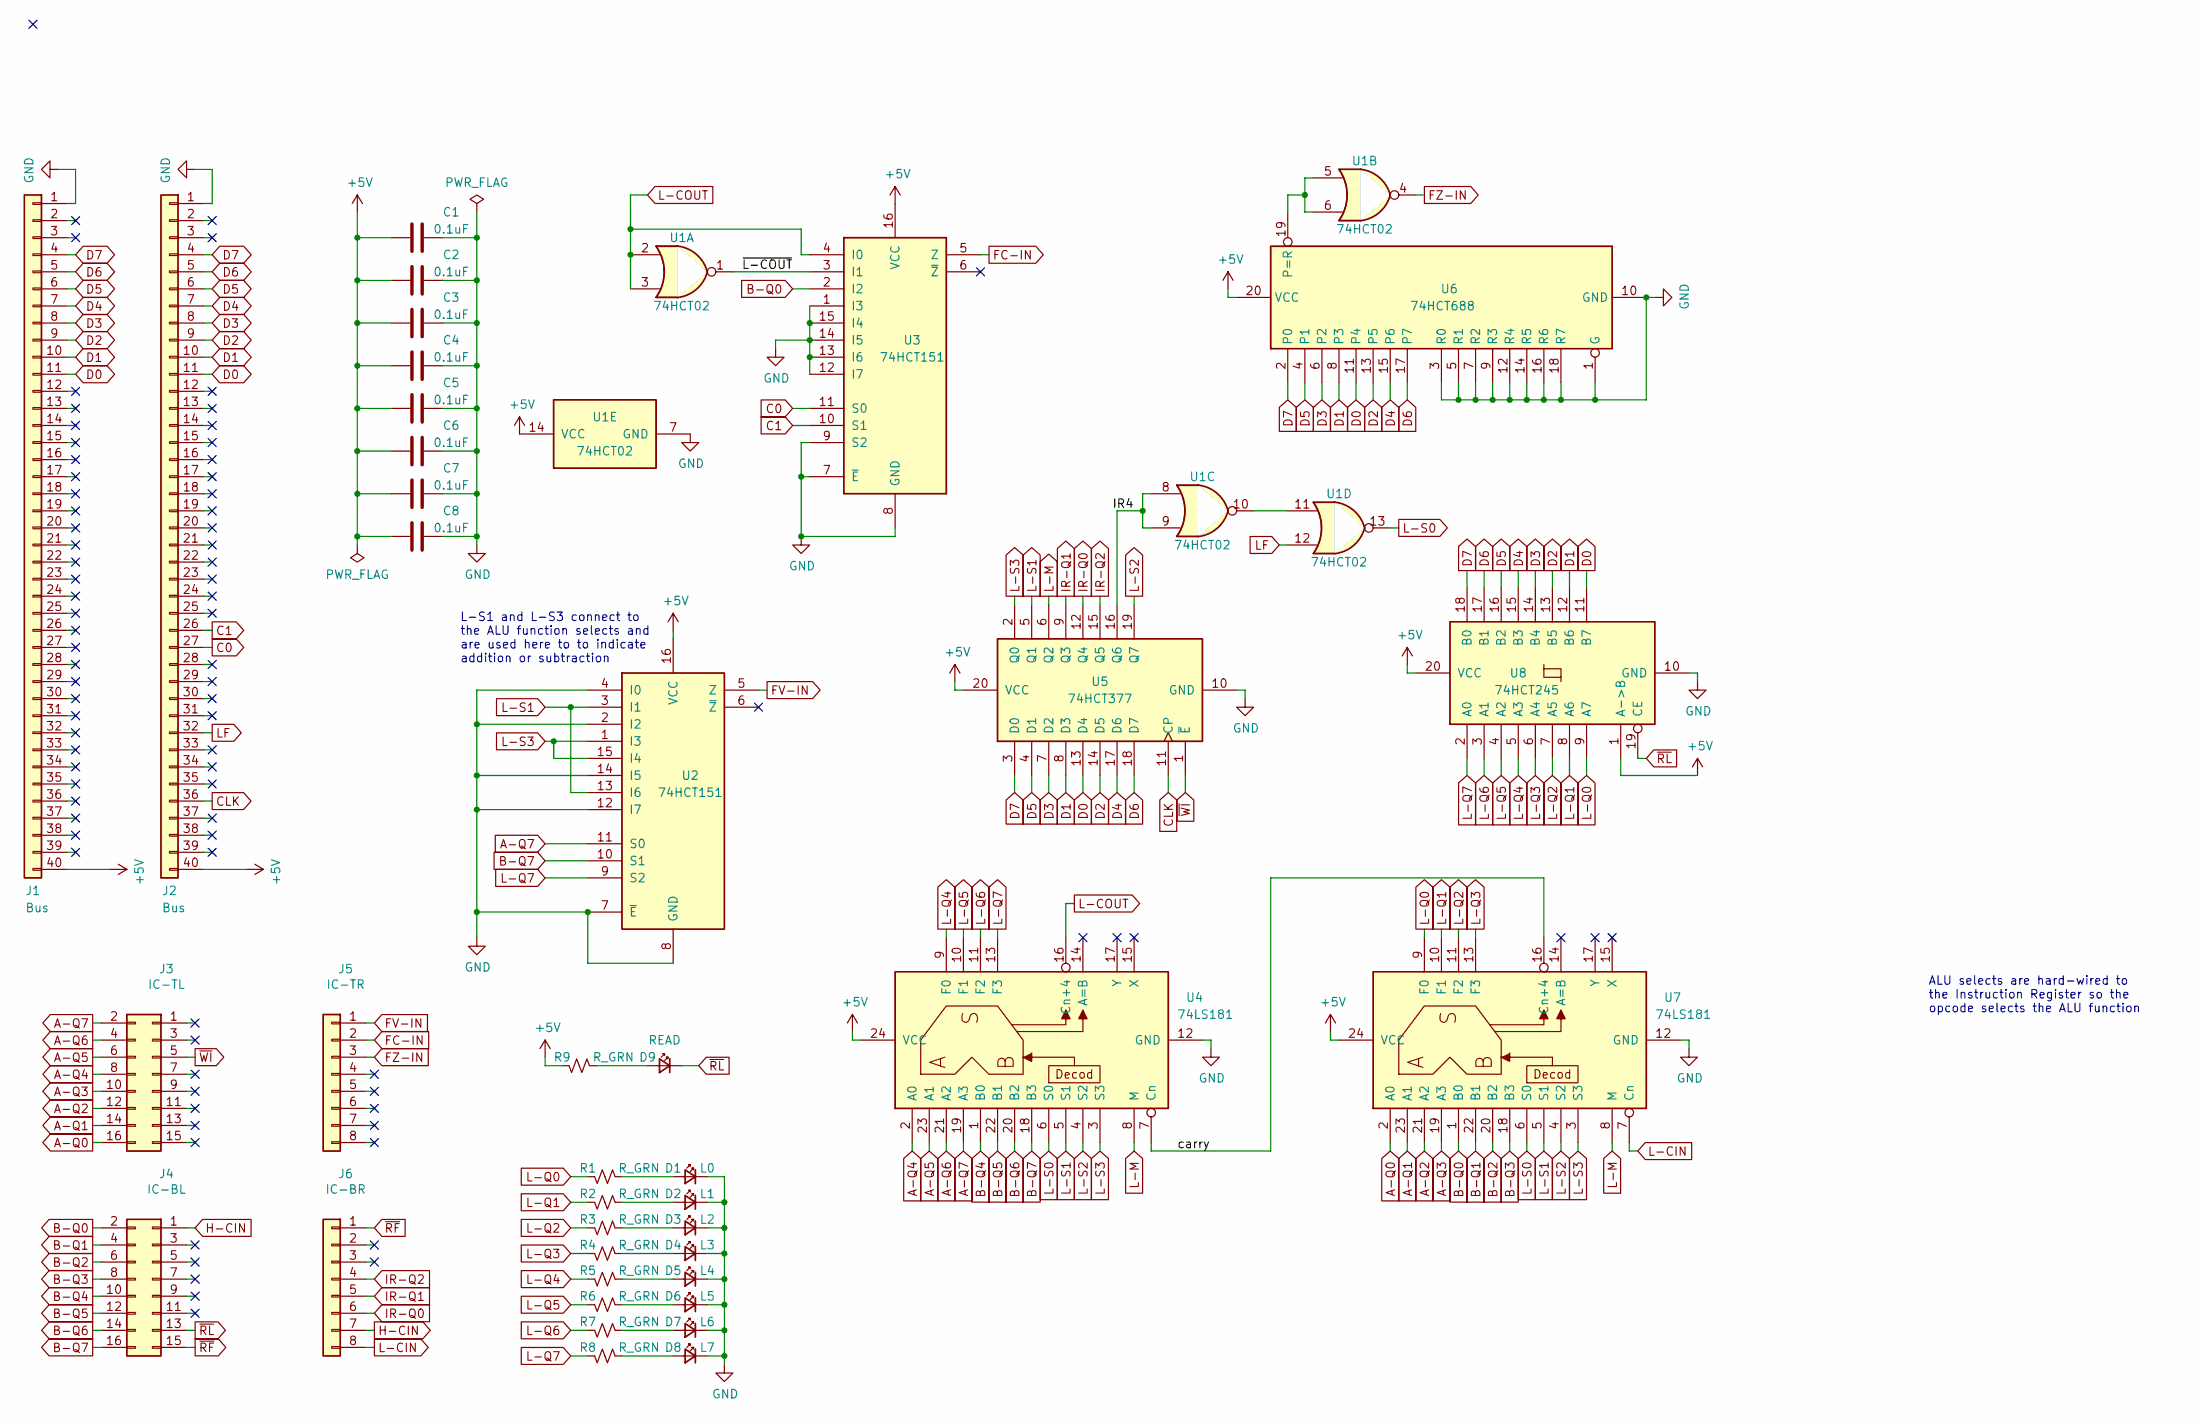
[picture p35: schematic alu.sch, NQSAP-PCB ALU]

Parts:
C1, C2, C3, C4, C5, C6, C7, C8: 0.1uF; C_0805_2012Metric_Pad1.18x1.45mm_HandSolder
D1: L0; LED_0805_2012Metric_Pad1.15x1.40mm_HandSolder
D2: L1; LED_0805_2012Metric_Pad1.15x1.40mm_HandSolder
D3: L2; LED_0805_2012Metric_Pad1.15x1.40mm_HandSolder
D4: L3; LED_0805_2012Metric_Pad1.15x1.40mm_HandSolder
D5: L4; LED_0805_2012Metric_Pad1.15x1.40mm_HandSolder
D6: L5; LED_0805_2012Metric_Pad1.15x1.40mm_HandSolder
D7: L6; LED_0805_2012Metric_Pad1.15x1.40mm_HandSolder
D8: L7; LED_0805_2012Metric_Pad1.15x1.40mm_HandSolder
D9: READ; LED_0805_2012Metric_Pad1.15x1.40mm_HandSolder
J1, J2: Bus; PinHeader_1x40_P2.54mm_Vertical
J3: IC-TL; PinHeader_2x08_P2.54mm_Vertical
J4: IC-BL; PinHeader_2x08_P2.54mm_Vertical
J5: IC-TR; PinHeader_1x08_P2.54mm_Vertical
J6: IC-BR; PinHeader_1x08_P2.54mm_Vertical
R1, R2, R3, R4, R5, R6, R7, R8, R9: R_GRN; R_0805_2012Metric_Pad1.20x1.40mm_HandSolder
U1: 74HCT02; DIP-14_W7.62mm
U2, U3: 74HCT151; DIP-16_W7.62mm
U4, U7: 74LS181; DIP-24_W15.24mm_Socket
U5: 74HCT377; DIP-20_W7.62mm
U6: 74HCT688; DIP-20_W7.62mm
U8: 74HCT245; DIP-20_W7.62mm

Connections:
+5V: C1.2, C2.2, C3.2, C4.2, C5.2, C6.2, C7.2, C8.2, J1.40, J2.40, R9.1, U1.14 (VCC), U2.16 (VCC), U3.16 (VCC), U4.24 (VCC), U5.20 (VCC), U6.20 (VCC), U7.24 (VCC), U8.1 (A->B), U8.20 (VCC)
/IR4: U1.8, U1.9, U5.16 (Q6)
/carry: U4.7 (Cn), U7.16 (Cn+4)
/~L-COUT: U1.1, U3.3 (I1)
A-Q0: J3.16, U7.2 (A0)
A-Q1: J3.14, U7.23 (A1)
A-Q2: J3.12, U7.21 (A2)
A-Q3: J3.10, U7.19 (A3)
A-Q4: J3.8, U4.2 (A0)
A-Q5: J3.6, U4.23 (A1)
A-Q6: J3.4, U4.21 (A2)
A-Q7: J3.2, U2.11 (S0), U4.19 (A3)
B-Q0: J4.2, U3.2 (I2), U7.1 (B0)
B-Q1: J4.4, U7.22 (B1)
B-Q2: J4.6, U7.20 (B2)
B-Q3: J4.8, U7.18 (B3)
B-Q4: J4.10, U4.1 (B0)
B-Q5: J4.12, U4.22 (B1)
B-Q6: J4.14, U4.20 (B2)
B-Q7: J4.16, U2.10 (S1), U4.18 (B3)
C0: J2.27, U3.11 (S0)
C1: J2.26, U3.10 (S1)
CLK: J2.36, U5.11 (CP)
D0: J1.11, J2.11, U5.13 (D4), U6.11 (P4), U8.11 (B7)
D1: J1.10, J2.10, U5.8 (D3), U6.8 (P3), U8.12 (B6)
D2: J1.9, J2.9, U5.14 (D5), U6.13 (P5), U8.13 (B5)
D3: J1.8, J2.8, U5.7 (D2), U6.6 (P2), U8.14 (B4)
D4: J1.7, J2.7, U5.17 (D6), U6.15 (P6), U8.15 (B3)
D5: J1.6, J2.6, U5.4 (D1), U6.4 (P1), U8.16 (B2)
D6: J1.5, J2.5, U5.18 (D7), U6.17 (P7), U8.17 (B1)
D7: J1.4, J2.4, U5.3 (D0), U6.2 (P0), U8.18 (B0)
FC-IN: J5.2, U3.5 (Z)
FV-IN: J5.1, U2.5 (Z)
FZ-IN: J5.3, U1.4
GND: C1.1, C2.1, C3.1, C4.1, C5.1, C6.1, C7.1, C8.1, D1.1 (K), D2.1 (K), D3.1 (K), D4.1 (K), D5.1 (K), D6.1 (K), D7.1 (K), D8.1 (K), J1.1, J2.1, U1.7 (GND), U2.2 (I2), U2.4 (I0), U2.7 (~E), U2.8 (GND), U2.12 (I7), U2.14 (I5), U3.1 (I3), U3.7 (~E), U3.8 (GND), U3.9 (S2), U3.12 (I7), U3.13 (I6), U3.14 (I5), U3.15 (I4), U4.12 (GND), U5.10 (GND), U6.1 (G), U6.3 (R0), U6.5 (R1), U6.7 (R2), U6.9 (R3), U6.10 (GND), U6.12 (R4), U6.14 (R5), U6.16 (R6), U6.18 (R7), U7.12 (GND), U8.10 (GND)
H-CIN: J4.1, J6.7
IR-Q0: J6.6, U5.12 (Q4)
IR-Q1: J6.5, U5.9 (Q3)
IR-Q2: J6.4, U5.15 (Q5)
L-CIN: J6.8, U7.7 (Cn)
L-COUT: U1.2, U1.3, U3.4 (I0), U4.16 (Cn+4)
L-M: U4.8 (M), U5.6 (Q2), U7.8 (M)
L-Q0: R1.1, U7.9 (F0), U8.9 (A7)
L-Q1: R2.1, U7.10 (F1), U8.8 (A6)
L-Q2: R3.1, U7.11 (F2), U8.7 (A5)
L-Q3: R4.1, U7.13 (F3), U8.6 (A4)
L-Q4: R5.1, U4.9 (F0), U8.5 (A3)
L-Q5: R6.1, U4.10 (F1), U8.4 (A2)
L-Q6: R7.1, U4.11 (F2), U8.3 (A1)
L-Q7: R8.1, U2.9 (S2), U4.13 (F3), U8.2 (A0)
L-S0: U1.13, U4.6 (S0), U7.6 (S0)
L-S1: U2.3 (I1), U2.13 (I6), U4.5 (S1), U5.5 (Q1), U7.5 (S1)
L-S2: U4.4 (S2), U5.19 (Q7), U7.4 (S2)
L-S3: U2.1 (I3), U2.15 (I4), U4.3 (S3), U5.2 (Q0), U7.3 (S3)
LF: J2.32, U1.12
unnamed: D1.2 (A), R1.2
unnamed: D2.2 (A), R2.2
unnamed: D3.2 (A), R3.2
unnamed: D4.2 (A), R4.2
unnamed: D5.2 (A), R5.2
unnamed: D6.2 (A), R6.2
unnamed: D7.2 (A), R7.2
unnamed: D8.2 (A), R8.2
unnamed: D9.2 (A), R9.2
unnamed: U1.5, U1.6, U6.19 (P=R)
unnamed: U1.10, U1.11
~RF: J4.15, J6.1
~RL: D9.1 (K), J4.13, U8.19 (CE)
~WI: J3.5, U5.1 (~E)

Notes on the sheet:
ALU selects are hard-wired to the Instruction Register so the opcode selects the ALU function
L-S1 and L-S3 connect to the ALU function selects and are used here to to indicate addition or subtraction

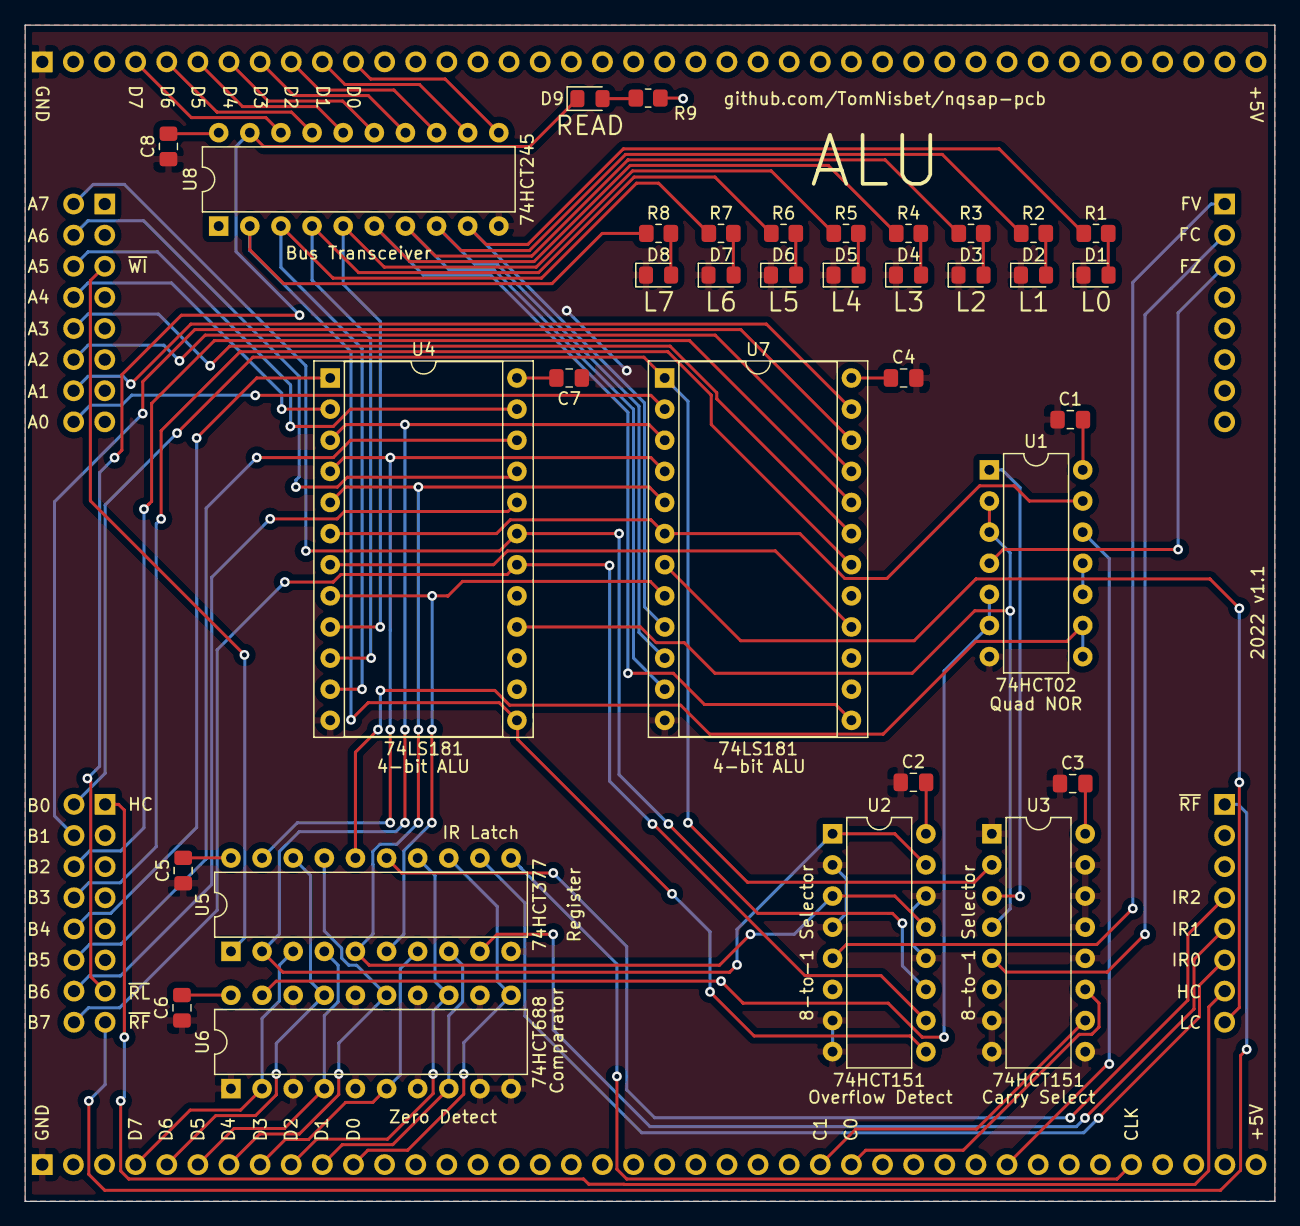
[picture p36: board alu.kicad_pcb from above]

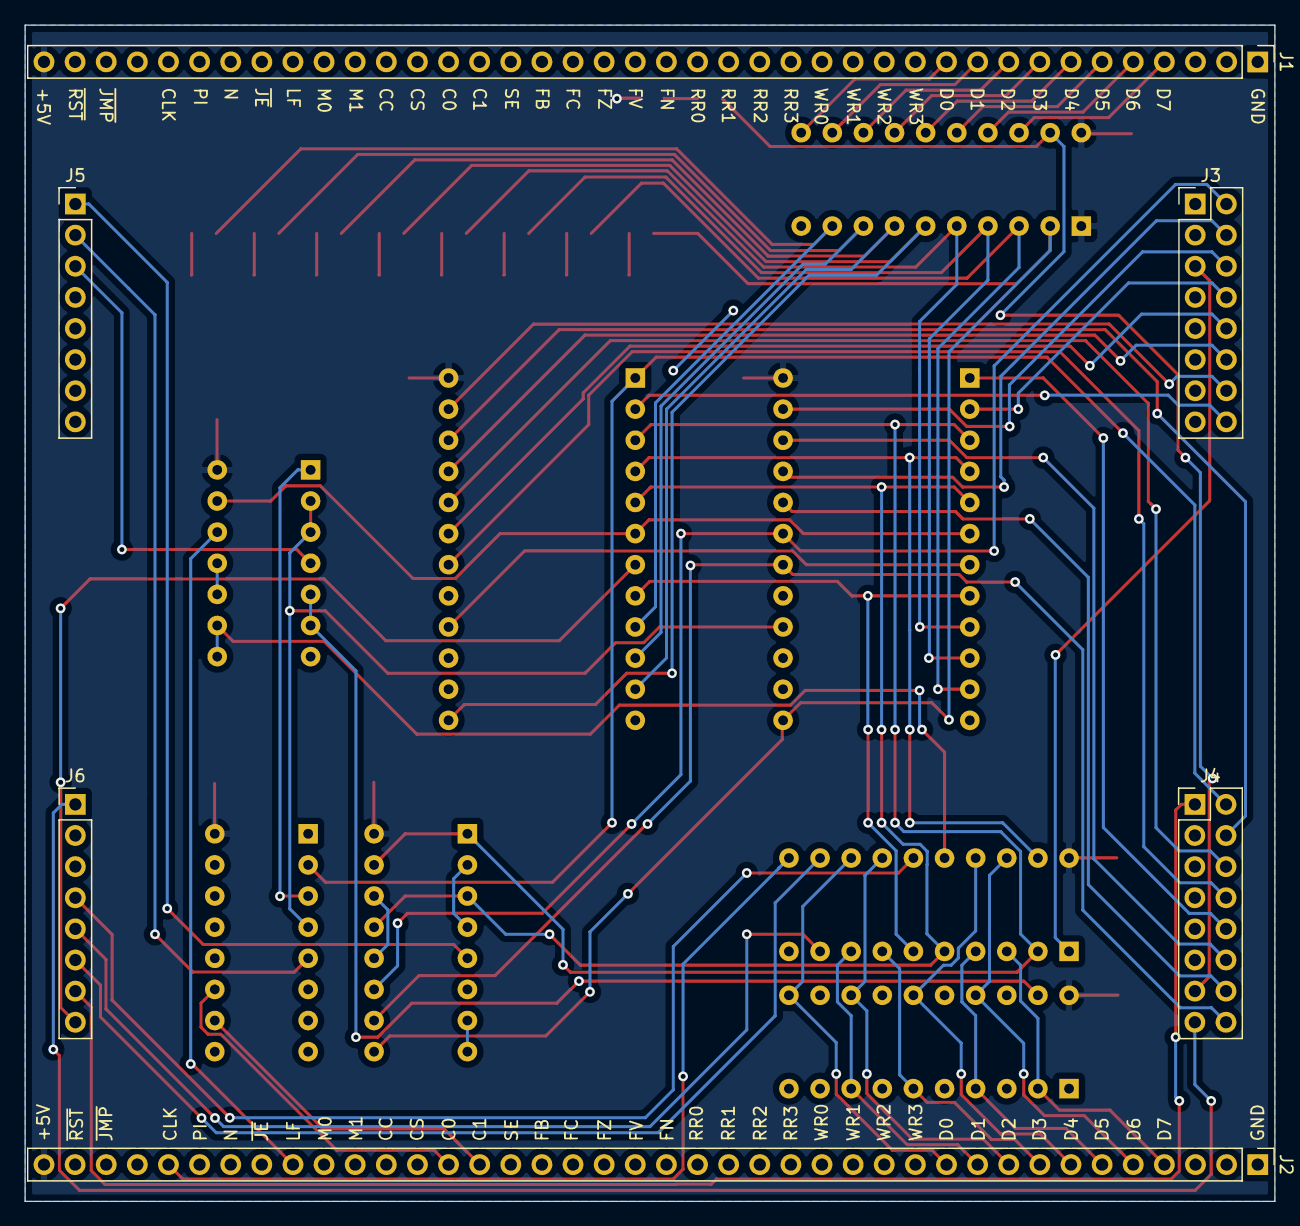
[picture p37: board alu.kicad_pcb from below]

Board: 2 copper layers, 102.0 x 96.0 mm, 40 parts (6 on the bottom side), 69 nets.

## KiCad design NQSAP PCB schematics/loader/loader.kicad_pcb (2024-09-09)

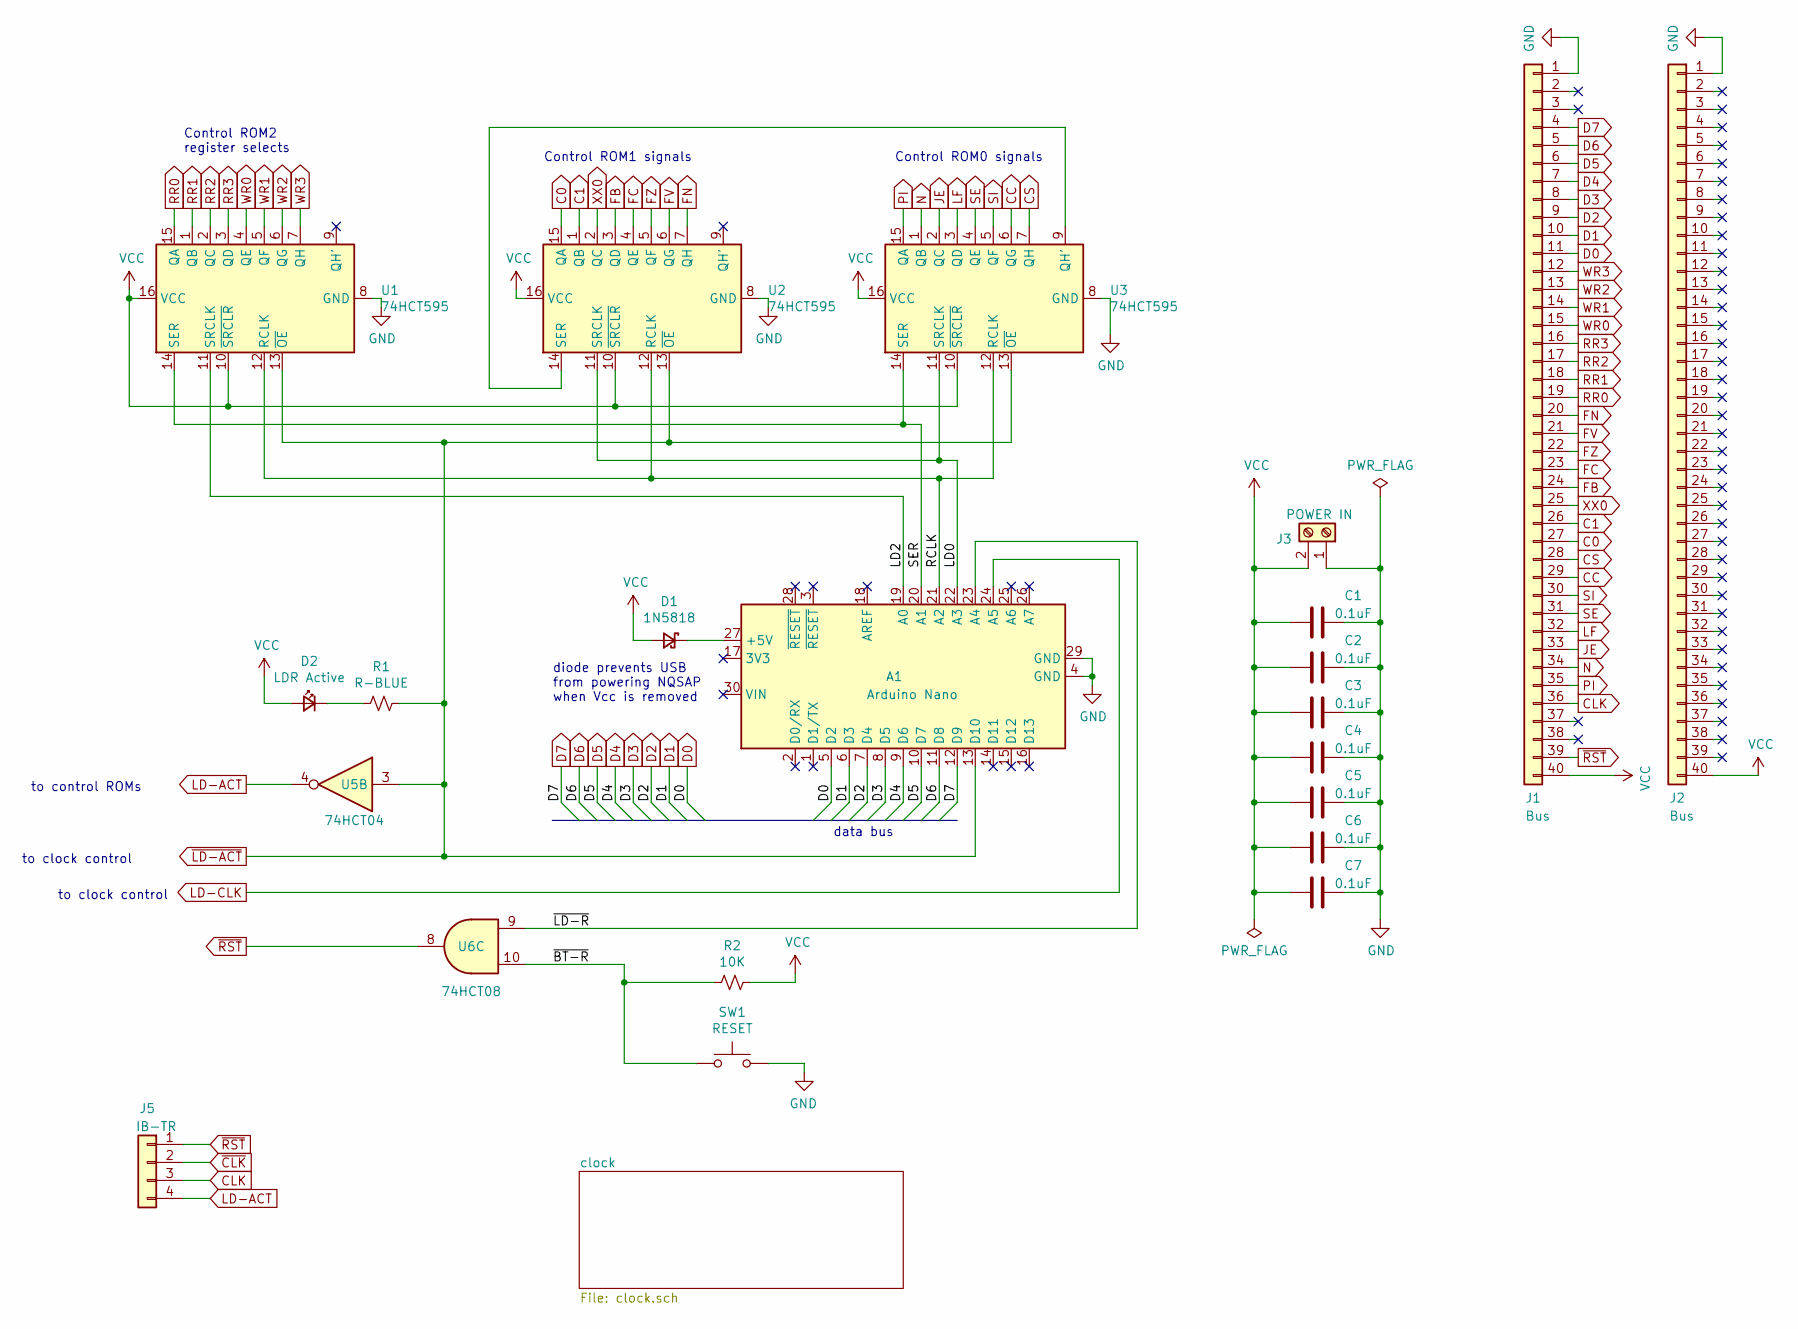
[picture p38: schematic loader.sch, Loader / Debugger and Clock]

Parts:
A1: Arduino Nano; Arduino_Nano
C1, C2, C3, C4, C5, C6, C7: 0.1uF; C_0805_2012Metric_Pad1.18x1.45mm_HandSolder
D1: 1N5818; D_DO-41_SOD81_P10.16mm_Horizontal
D2: LDR Active; LED_0805_2012Metric_Pad1.15x1.40mm_HandSolder
J1, J2: Bus; PinHeader_1x40_P2.54mm_Vertical
J3: POWER IN; TerminalBlock_RND_205-00012_1x02_P5.00mm_Horizontal
J5: IB-TR; PinHeader_1x04_P2.54mm_Vertical
R1: R-BLUE; R_0805_2012Metric_Pad1.20x1.40mm_HandSolder
R2: 10K; R_0805_2012Metric_Pad1.20x1.40mm_HandSolder
SW1: RESET; SW_PUSH_6mm
U1, U2, U3: 74HCT595; SOIC-16_3.9x9.9mm_P1.27mm
U5: 74HCT04; DIP-14_W7.62mm
U6: 74HCT08; DIP-14_W7.62mm

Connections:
/LD0: A1.22 (A3), U2.11 (SRCLK), U3.11 (SRCLK)
/LD2: A1.19 (A0), U1.11 (SRCLK)
/RCLK: A1.21 (A2), U1.12 (RCLK), U2.12 (RCLK), U3.12 (RCLK)
/SER: A1.20 (A1), U1.14 (SER), U3.14 (SER)
/~BT-R: R2.2, SW1.2, U6.10
/~LD-R: A1.23 (A4), U6.9
C0: J1.27, U2.15 (QA)
C1: J1.26, U2.1 (QB)
CC: J1.29, U3.6 (QG)
CLK: J1.36, J5.3; also elsewhere on the board
CS: J1.28, U3.7 (QH)
D0: A1.5 (D2), J1.11
D1: A1.6 (D3), J1.10
D2: A1.7 (D4), J1.9
D3: A1.8 (D5), J1.8
D4: A1.9 (D6), J1.7
D5: A1.10 (D7), J1.6
D6: A1.11 (D8), J1.5
D7: A1.12 (D9), J1.4
FB: J1.24, U2.3 (QD)
FC: J1.23, U2.4 (QE)
FN: J1.20, U2.7 (QH)
FV: J1.21, U2.6 (QG)
FZ: J1.22, U2.5 (QF)
GND: A1.4 (GND), A1.29 (GND), C1.1, C2.1, C3.1, C4.1, C5.1, C6.1, C7.1, J1.1, J2.1, J3.1, SW1.1, U1.8 (GND), U2.8 (GND), U3.8 (GND); also elsewhere on the board
JE: J1.33, U3.2 (QC)
LD-ACT: J5.4, U5.4
LD-CLK: A1.24 (A5); also elsewhere on the board
LF: J1.32, U3.3 (QD)
N: J1.34, U3.1 (QB)
unnamed: A1.27 (+5V), D1.1 (K)
unnamed: D2.1 (K), R1.2
unnamed: U2.14 (SER), U3.9 (QH')
PI: J1.35, U3.15 (QA)
RR0: J1.19, U1.15 (QA)
RR1: J1.18, U1.1 (QB)
RR2: J1.17, U1.2 (QC)
RR3: J1.16, U1.3 (QD)
SE: J1.31, U3.4 (QE)
SI: J1.30, U3.5 (QF)
VCC: C1.2, C2.2, C3.2, C4.2, C5.2, C6.2, C7.2, D1.2 (A), D2.2 (A), J1.40, J2.40, J3.2, R2.1, U1.10 (~SRCLR), U1.16 (VCC), U2.10 (~SRCLR), U2.16 (VCC), U3.10 (~SRCLR), U3.16 (VCC); also elsewhere on the board
WR0: J1.15, U1.4 (QE)
WR1: J1.14, U1.5 (QF)
WR2: J1.13, U1.6 (QG)
WR3: J1.12, U1.7 (QH)
XX0: J1.25, U2.2 (QC)
~CLK: J5.2; also elsewhere on the board
~LD-ACT: A1.13 (D10), R1.1, U1.13 (~OE), U2.13 (~OE), U3.13 (~OE), U5.3; also elsewhere on the board
~RST: J1.39, J5.1, U6.8

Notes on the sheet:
data bus
diode prevents USB from powering NQSAP when Vcc is removed
to control ROMs
to clock control
Control ROM2 register selects
Control ROM1 signals
Control ROM0 signals

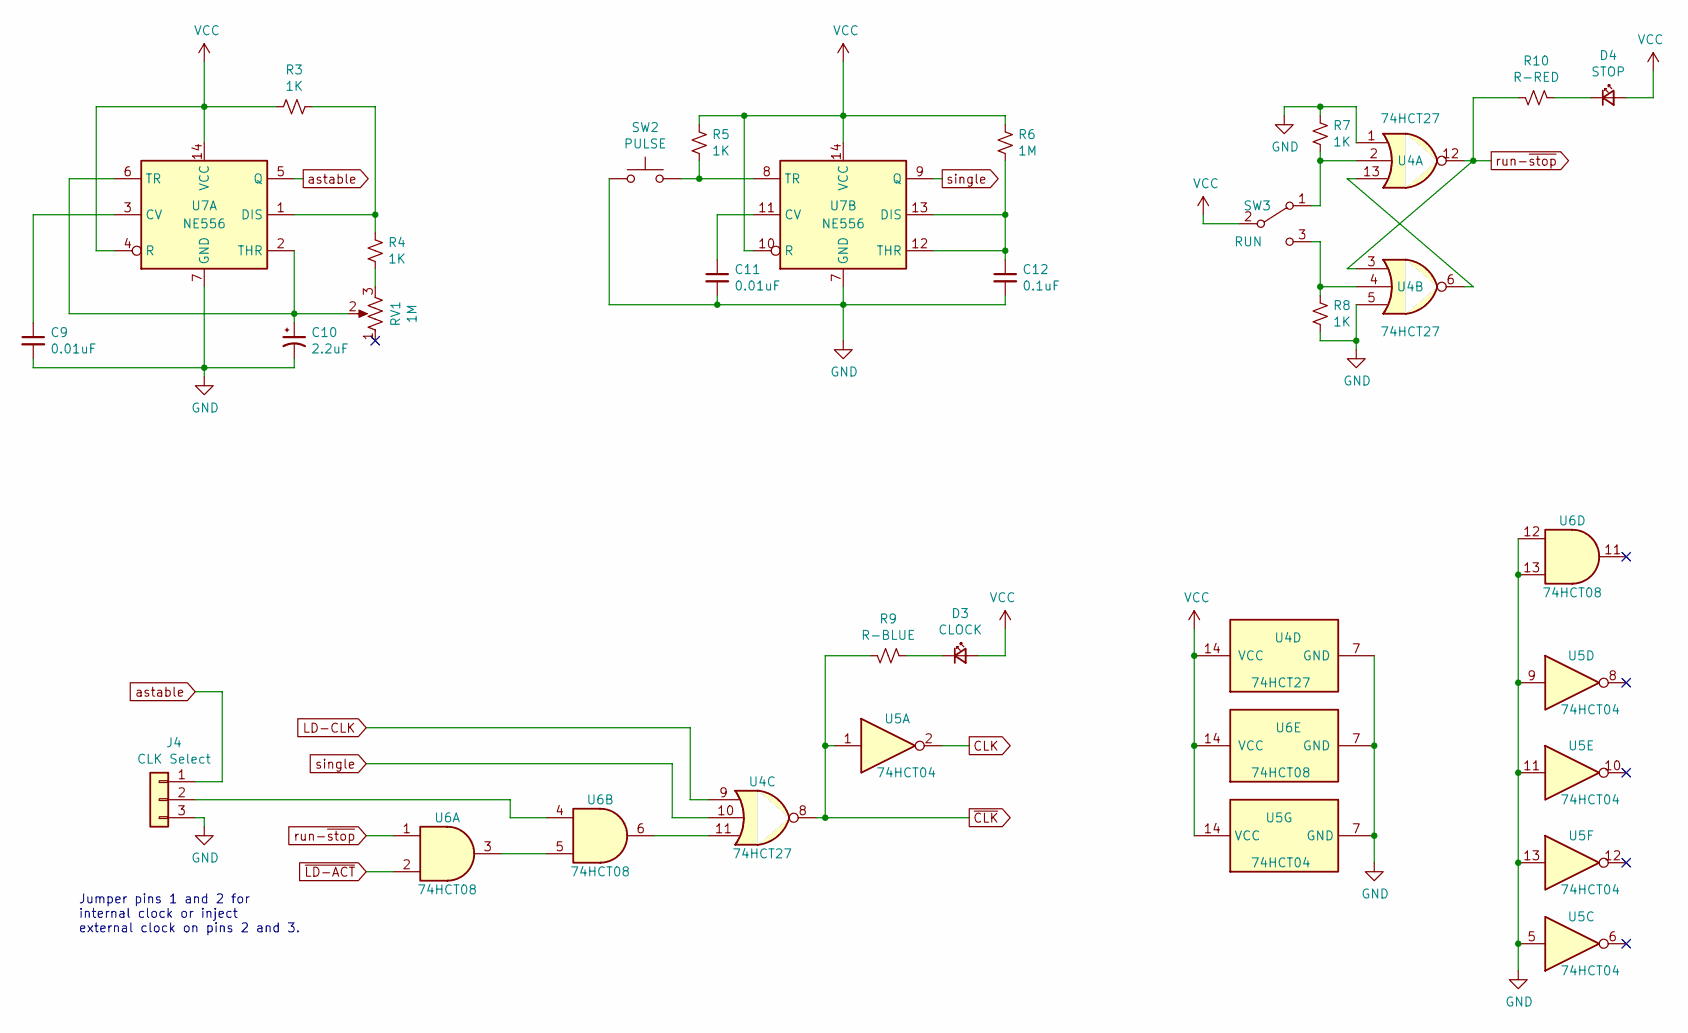
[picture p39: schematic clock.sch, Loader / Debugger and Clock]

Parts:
C9, C11: 0.01uF; C_0805_2012Metric_Pad1.18x1.45mm_HandSolder
C10: 2.2uF; C_0805_2012Metric_Pad1.18x1.45mm_HandSolder
C12: 0.1uF; C_0805_2012Metric_Pad1.18x1.45mm_HandSolder
D3: CLOCK; LED_0805_2012Metric_Pad1.15x1.40mm_HandSolder
D4: STOP; LED_0805_2012Metric_Pad1.15x1.40mm_HandSolder
J4: CLK Select; PinHeader_1x03_P2.54mm_Vertical
R3, R4, R5, R7, R8: 1K; R_0805_2012Metric_Pad1.20x1.40mm_HandSolder
R6: 1M; R_0805_2012Metric_Pad1.20x1.40mm_HandSolder
R9: R-BLUE; R_0805_2012Metric_Pad1.20x1.40mm_HandSolder
R10: R-RED; R_0805_2012Metric_Pad1.20x1.40mm_HandSolder
RV1: 1M; Potentiometer_Bourns_3386F_Vertical
SW2: PULSE; SW_PUSH-12mm
SW3: RUN; Switch_Slide_11.6x4mm_EG1218
U4: 74HCT27; DIP-14_W7.62mm
U5: 74HCT04; DIP-14_W7.62mm
U6: 74HCT08; DIP-14_W7.62mm
U7: NE556; DIP-14_W7.62mm

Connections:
CLK: U5.2; also elsewhere on the board
GND: C9.2, C10.2, C11.2, C12.2, J4.3, R7.1, R8.2, SW2.1, U4.1, U4.5, U4.7 (GND), U5.5, U5.7 (GND), U5.9, U5.11, U5.13, U6.7 (GND), U6.12, U6.13, U7.7 (GND); also elsewhere on the board
LD-CLK: U4.9; also elsewhere on the board
unnamed: C9.1, U7.3 (CV)
unnamed: C10.1, RV1.2, U7.2 (THR), U7.6 (TR)
unnamed: C11.1, U7.11 (CV)
unnamed: C12.1, R6.2, U7.12 (THR), U7.13 (DIS)
unnamed: D3.1 (K), R9.2
unnamed: D4.1 (K), R10.2
unnamed: J4.2, U6.4
unnamed: R3.1, R4.2, U7.1 (DIS)
unnamed: R4.1, RV1.3
unnamed: R5.2, SW2.2, U7.8 (TR)
unnamed: R7.2, SW3.1 (A), U4.2
unnamed: R8.1, SW3.3 (C), U4.4
unnamed: U4.11, U6.6
unnamed: U4.6, U4.13
unnamed: U6.3, U6.5
VCC: D3.2 (A), D4.2 (A), R3.2, R5.1, R6.1, SW3.2 (B), U4.14 (VCC), U5.14 (VCC), U6.14 (VCC), U7.4 (R), U7.10 (R), U7.14 (VCC); also elsewhere on the board
astable: J4.1, U7.5 (Q)
run-~stop: R10.1, U4.3, U4.12, U6.1
single: U4.10, U7.9 (Q)
~CLK: R9.1, U4.8, U5.1; also elsewhere on the board
~LD-ACT: U6.2; also elsewhere on the board

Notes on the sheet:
Jumper pins 1 and 2 for internal clock or inject external clock on pins 2 and 3.

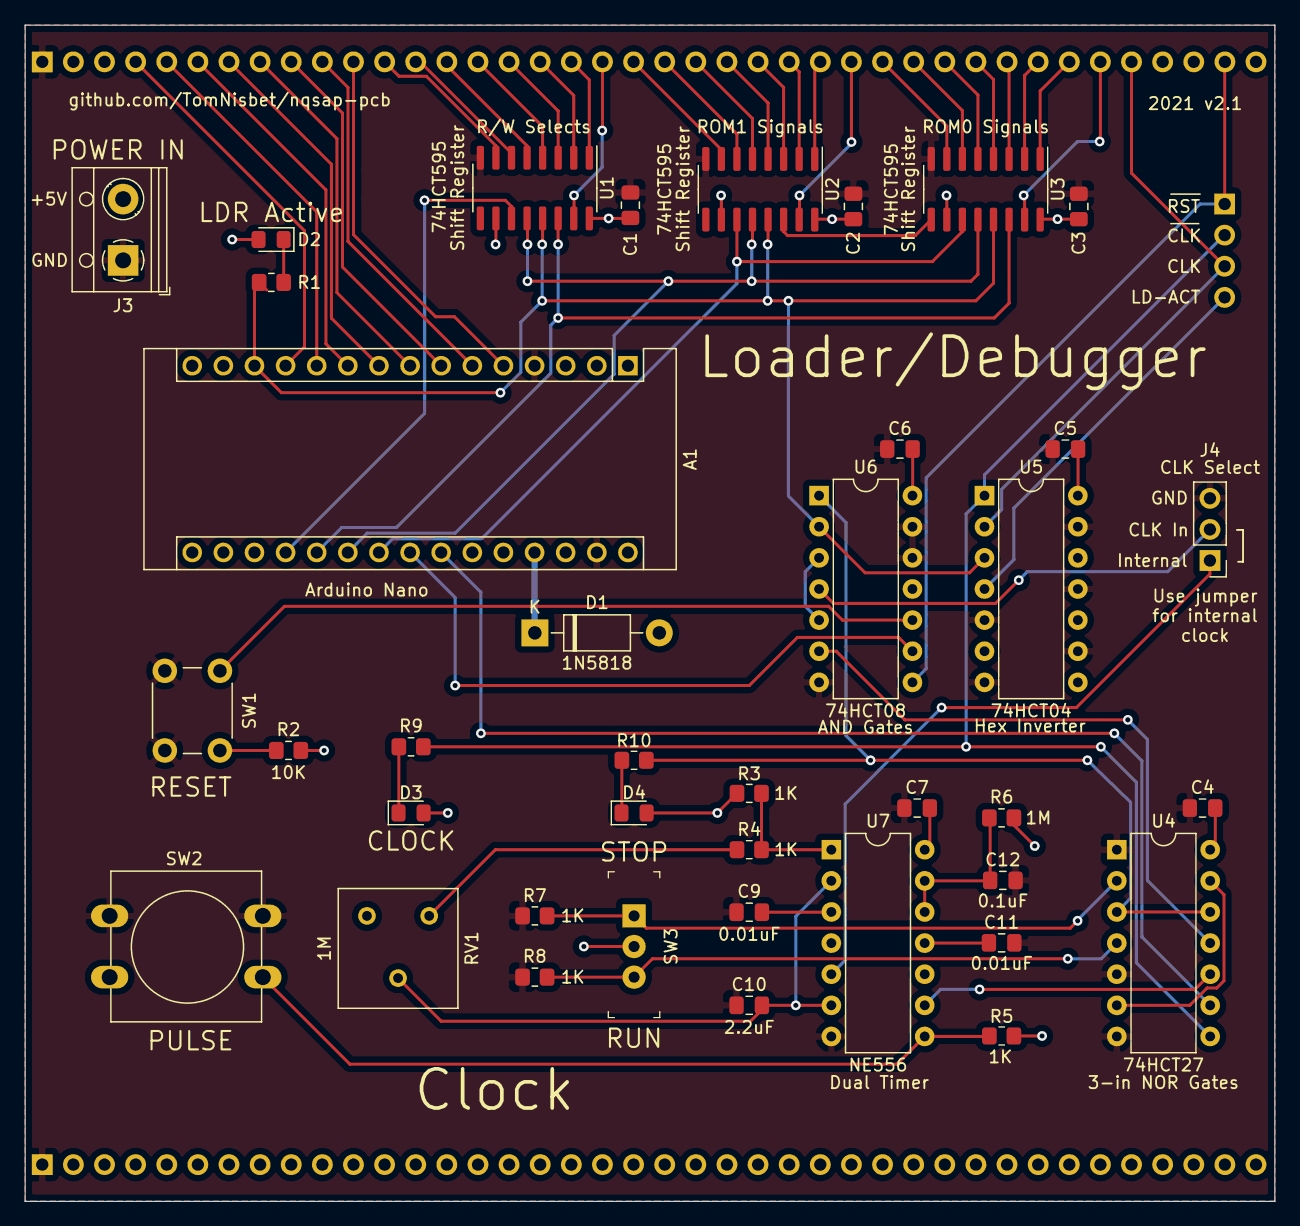
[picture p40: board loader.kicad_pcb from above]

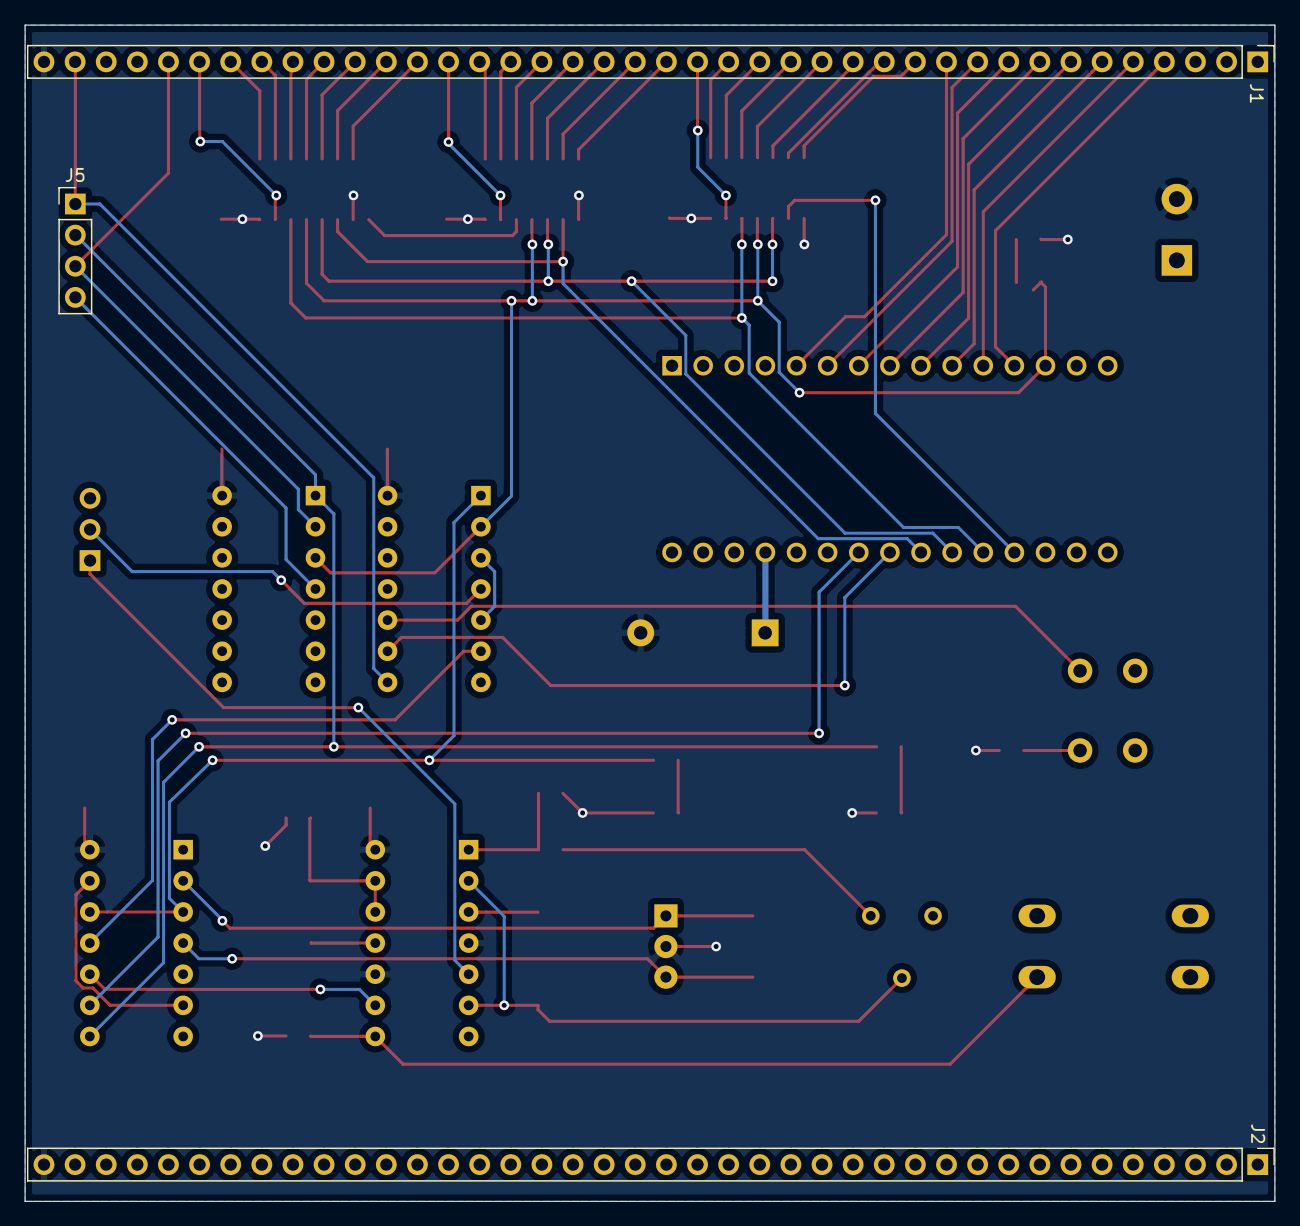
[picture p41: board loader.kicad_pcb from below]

Board: 2 copper layers, 102.0 x 96.0 mm, 42 parts (3 on the bottom side), 67 nets.

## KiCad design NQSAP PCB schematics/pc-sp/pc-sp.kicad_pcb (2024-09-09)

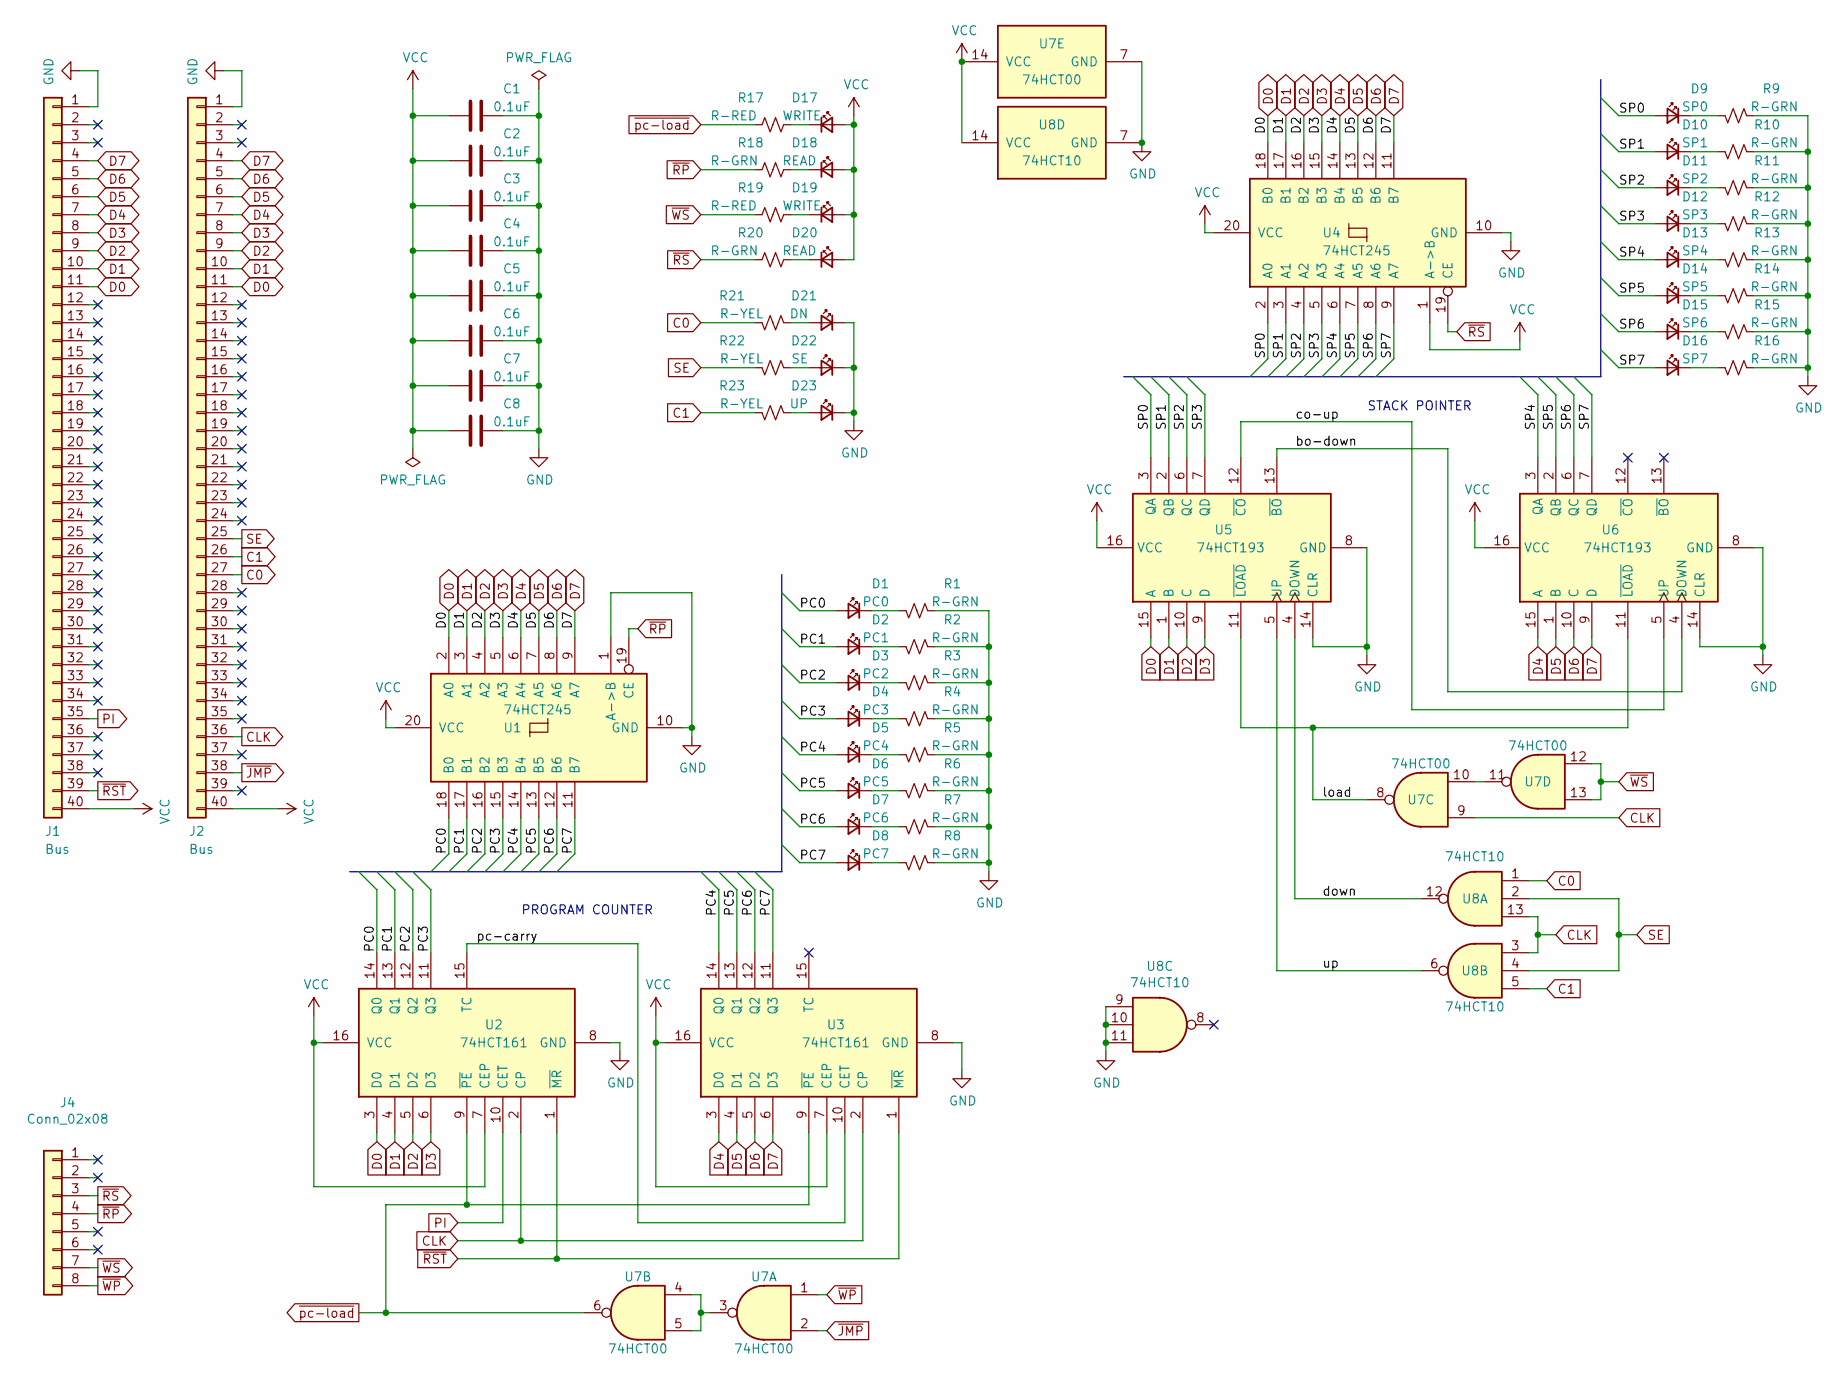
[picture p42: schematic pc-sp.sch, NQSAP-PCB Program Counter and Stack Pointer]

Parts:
C1, C2, C3, C4, C5, C6, C7, C8: 0.1uF; C_0805_2012Metric_Pad1.18x1.45mm_HandSolder
D1: PC0; LED_0805_2012Metric_Pad1.15x1.40mm_HandSolder
D2: PC1; LED_0805_2012Metric_Pad1.15x1.40mm_HandSolder
D3: PC2; LED_0805_2012Metric_Pad1.15x1.40mm_HandSolder
D4: PC3; LED_0805_2012Metric_Pad1.15x1.40mm_HandSolder
D5: PC4; LED_0805_2012Metric_Pad1.15x1.40mm_HandSolder
D6: PC5; LED_0805_2012Metric_Pad1.15x1.40mm_HandSolder
D7: PC6; LED_0805_2012Metric_Pad1.15x1.40mm_HandSolder
D8: PC7; LED_0805_2012Metric_Pad1.15x1.40mm_HandSolder
D9: SP0; LED_0805_2012Metric_Pad1.15x1.40mm_HandSolder
D10: SP1; LED_0805_2012Metric_Pad1.15x1.40mm_HandSolder
D11: SP2; LED_0805_2012Metric_Pad1.15x1.40mm_HandSolder
D12: SP3; LED_0805_2012Metric_Pad1.15x1.40mm_HandSolder
D13: SP4; LED_0805_2012Metric_Pad1.15x1.40mm_HandSolder
D14: SP5; LED_0805_2012Metric_Pad1.15x1.40mm_HandSolder
D15: SP6; LED_0805_2012Metric_Pad1.15x1.40mm_HandSolder
D16: SP7; LED_0805_2012Metric_Pad1.15x1.40mm_HandSolder
D17, D19: WRITE; LED_0805_2012Metric_Pad1.15x1.40mm_HandSolder
D18, D20: READ; LED_0805_2012Metric_Pad1.15x1.40mm_HandSolder
D21: DN; LED_0805_2012Metric_Pad1.15x1.40mm_HandSolder
D22: SE; LED_0805_2012Metric_Pad1.15x1.40mm_HandSolder
D23: UP; LED_0805_2012Metric_Pad1.15x1.40mm_HandSolder
J1, J2: Bus; PinHeader_1x40_P2.54mm_Vertical
J4: Conn_02x08; PinHeader_1x08_P2.54mm_Vertical
R1, R2, R3, R4, R5, R6, R7, R8, R9, R10, R11, R12, R13, R14, R15, R16, R18, R20: R-GRN; R_0805_2012Metric_Pad1.20x1.40mm_HandSolder
R17, R19: R-RED; R_0805_2012Metric_Pad1.20x1.40mm_HandSolder
R21, R22, R23: R-YEL; R_0805_2012Metric_Pad1.20x1.40mm_HandSolder
U1, U4: 74HCT245; DIP-20_W7.62mm
U2, U3: 74HCT161; DIP-16_W7.62mm
U5, U6: 74HCT193; DIP-16_W7.62mm
U7: 74HCT00; DIP-14_W7.62mm
U8: 74HCT10; DIP-14_W7.62mm

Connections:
/PC0: D1.2 (A), U1.18 (B0), U2.14 (Q0)
/PC1: D2.2 (A), U1.17 (B1), U2.13 (Q1)
/PC2: D3.2 (A), U1.16 (B2), U2.12 (Q2)
/PC3: D4.2 (A), U1.15 (B3), U2.11 (Q3)
/PC4: D5.2 (A), U1.14 (B4), U3.14 (Q0)
/PC5: D6.2 (A), U1.13 (B5), U3.13 (Q1)
/PC6: D7.2 (A), U1.12 (B6), U3.12 (Q2)
/PC7: D8.2 (A), U1.11 (B7), U3.11 (Q3)
/SP0: D9.2 (A), U4.2 (A0), U5.3 (QA)
/SP1: D10.2 (A), U4.3 (A1), U5.2 (QB)
/SP2: D11.2 (A), U4.4 (A2), U5.6 (QC)
/SP3: D12.2 (A), U4.5 (A3), U5.7 (QD)
/SP4: D13.2 (A), U4.6 (A4), U6.3 (QA)
/SP5: D14.2 (A), U4.7 (A5), U6.2 (QB)
/SP6: D15.2 (A), U4.8 (A6), U6.6 (QC)
/SP7: D16.2 (A), U4.9 (A7), U6.7 (QD)
/bo-down: U5.13 (~BO), U6.4 (DOWN)
/co-up: U5.12 (~CO), U6.5 (UP)
/down: U5.4 (DOWN), U8.12
/load: U5.11 (~LOAD), U6.11 (~LOAD), U7.8
/pc-carry: U2.15 (TC), U3.10 (CET)
/up: U5.5 (UP), U8.6
C0: J2.27, R21.1, U8.1
C1: J2.26, R23.1, U8.5
CLK: J2.36, U2.2 (CP), U3.2 (CP), U7.9, U8.3, U8.13
D0: J1.11, J2.11, U1.2 (A0), U2.3 (D0), U4.18 (B0), U5.15 (A)
D1: J1.10, J2.10, U1.3 (A1), U2.4 (D1), U4.17 (B1), U5.1 (B)
D2: J1.9, J2.9, U1.4 (A2), U2.5 (D2), U4.16 (B2), U5.10 (C)
D3: J1.8, J2.8, U1.5 (A3), U2.6 (D3), U4.15 (B3), U5.9 (D)
D4: J1.7, J2.7, U1.6 (A4), U3.3 (D0), U4.14 (B4), U6.15 (A)
D5: J1.6, J2.6, U1.7 (A5), U3.4 (D1), U4.13 (B5), U6.1 (B)
D6: J1.5, J2.5, U1.8 (A6), U3.5 (D2), U4.12 (B6), U6.10 (C)
D7: J1.4, J2.4, U1.9 (A7), U3.6 (D3), U4.11 (B7), U6.9 (D)
GND: C1.1, C2.1, C3.1, C4.1, C5.1, C6.1, C7.1, C8.1, D21.1 (K), D22.1 (K), D23.1 (K), J1.1, J2.1, R1.2, R2.2, R3.2, R4.2, R5.2, R6.2, R7.2, R8.2, R9.2, R10.2, R11.2, R12.2, R13.2, R14.2, R15.2, R16.2, U1.1 (A->B), U1.10 (GND), U2.8 (GND), U3.8 (GND), U4.10 (GND), U5.8 (GND), U5.14 (CLR), U6.8 (GND), U6.14 (CLR), U7.7 (GND), U8.7 (GND), U8.9, U8.10, U8.11
unnamed: D1.1 (K), R1.1
unnamed: D2.1 (K), R2.1
unnamed: D3.1 (K), R3.1
unnamed: D4.1 (K), R4.1
unnamed: D5.1 (K), R5.1
unnamed: D6.1 (K), R6.1
unnamed: D7.1 (K), R7.1
unnamed: D8.1 (K), R8.1
unnamed: D9.1 (K), R9.1
unnamed: D10.1 (K), R10.1
unnamed: D11.1 (K), R11.1
unnamed: D12.1 (K), R12.1
unnamed: D13.1 (K), R13.1
unnamed: D14.1 (K), R14.1
unnamed: D15.1 (K), R15.1
unnamed: D16.1 (K), R16.1
unnamed: D17.1 (K), R17.1
unnamed: D18.1 (K), R18.1
unnamed: D19.1 (K), R19.1
unnamed: D20.1 (K), R20.1
unnamed: D21.2 (A), R21.2
unnamed: D22.2 (A), R22.2
unnamed: D23.2 (A), R23.2
unnamed: U7.3, U7.4, U7.5
unnamed: U7.10, U7.11
PI: J1.35, U2.10 (CET)
SE: J2.25, R22.1, U8.2, U8.4
VCC: C1.2, C2.2, C3.2, C4.2, C5.2, C6.2, C7.2, C8.2, D17.2 (A), D18.2 (A), D19.2 (A), D20.2 (A), J1.40, J2.40, U1.20 (VCC), U2.7 (CEP), U2.16 (VCC), U3.7 (CEP), U3.16 (VCC), U4.1 (A->B), U4.20 (VCC), U5.16 (VCC), U6.16 (VCC), U7.14 (VCC), U8.14 (VCC)
~JMP: J2.38, U7.2
~RP: J4.4, R18.2, U1.19 (CE)
~RS: J4.3, R20.2, U4.19 (CE)
~RST: J1.39, U2.1 (~MR), U3.1 (~MR)
~WP: J4.8, U7.1
~WS: J4.7, R19.2, U7.12, U7.13
~pc-load: R17.2, U2.9 (~PE), U3.9 (~PE), U7.6

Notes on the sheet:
PROGRAM COUNTER
STACK POINTER

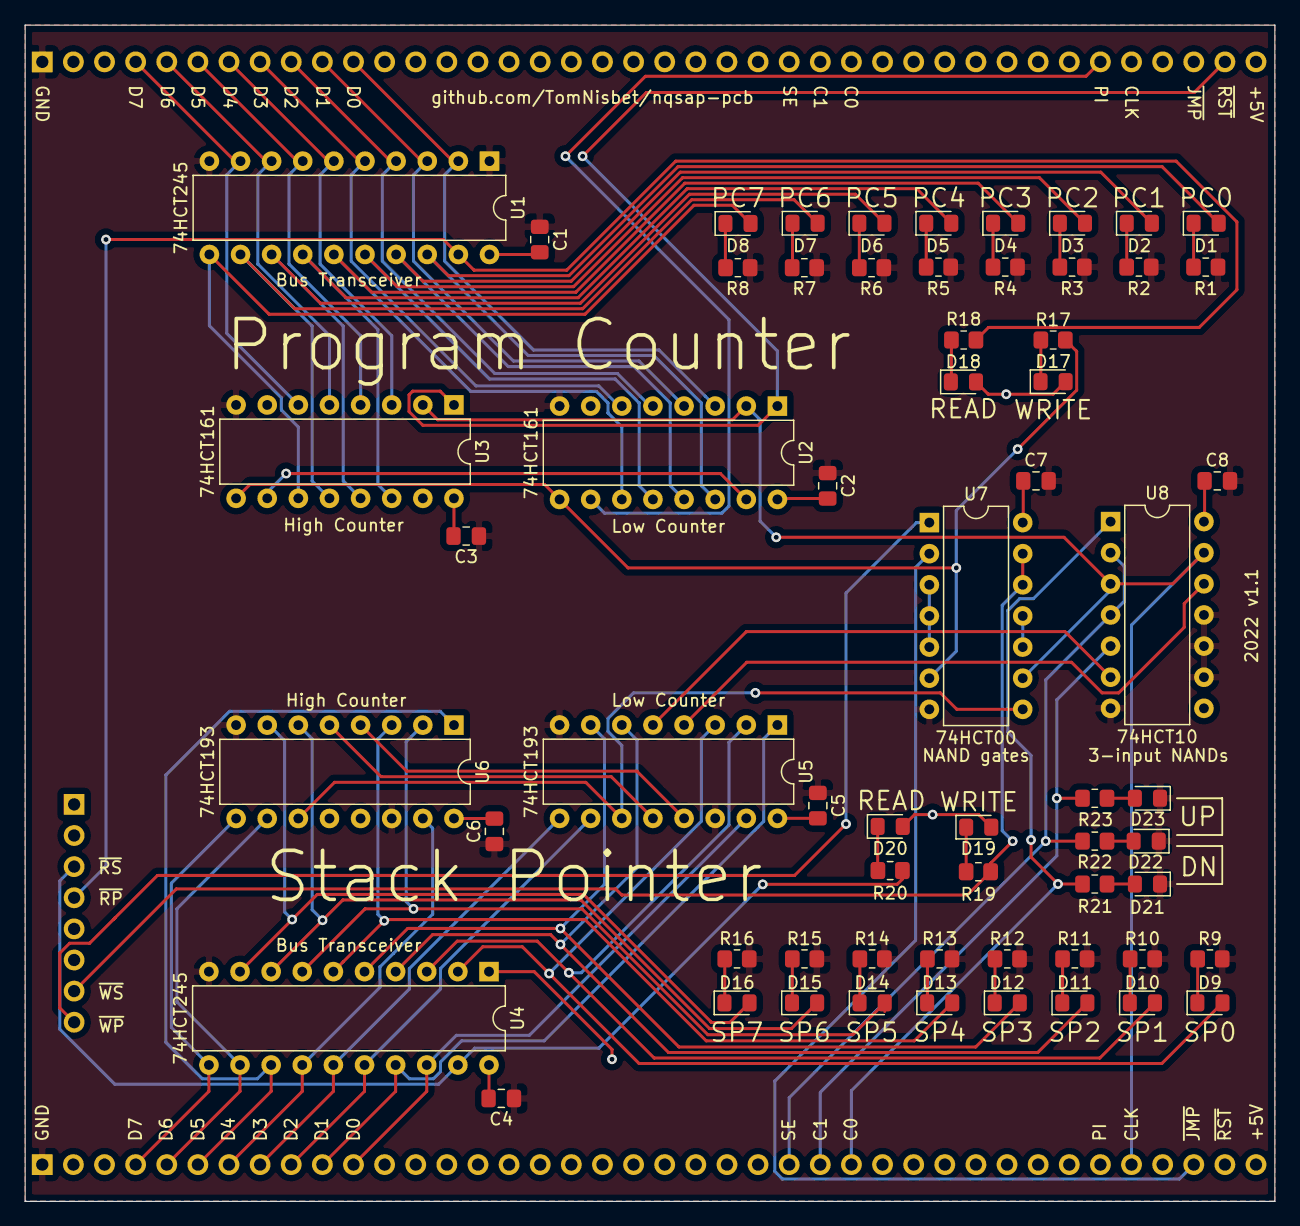
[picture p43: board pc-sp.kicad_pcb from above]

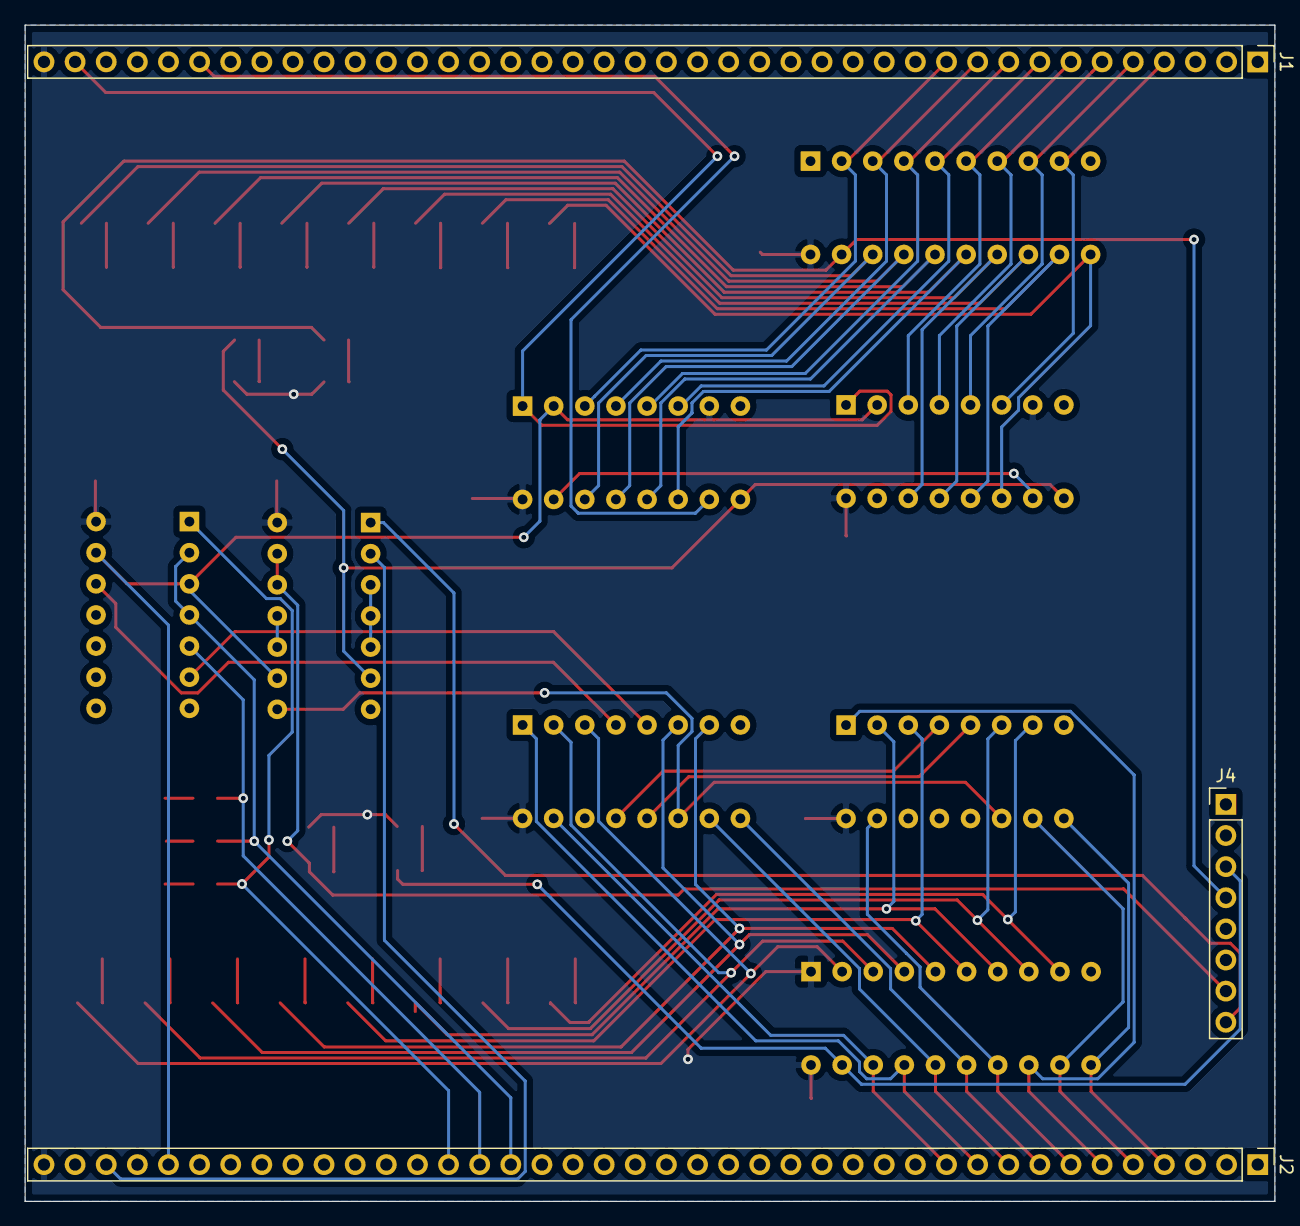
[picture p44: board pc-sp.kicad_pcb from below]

Board: 2 copper layers, 102.0 x 96.0 mm, 65 parts (3 on the bottom side), 69 nets.

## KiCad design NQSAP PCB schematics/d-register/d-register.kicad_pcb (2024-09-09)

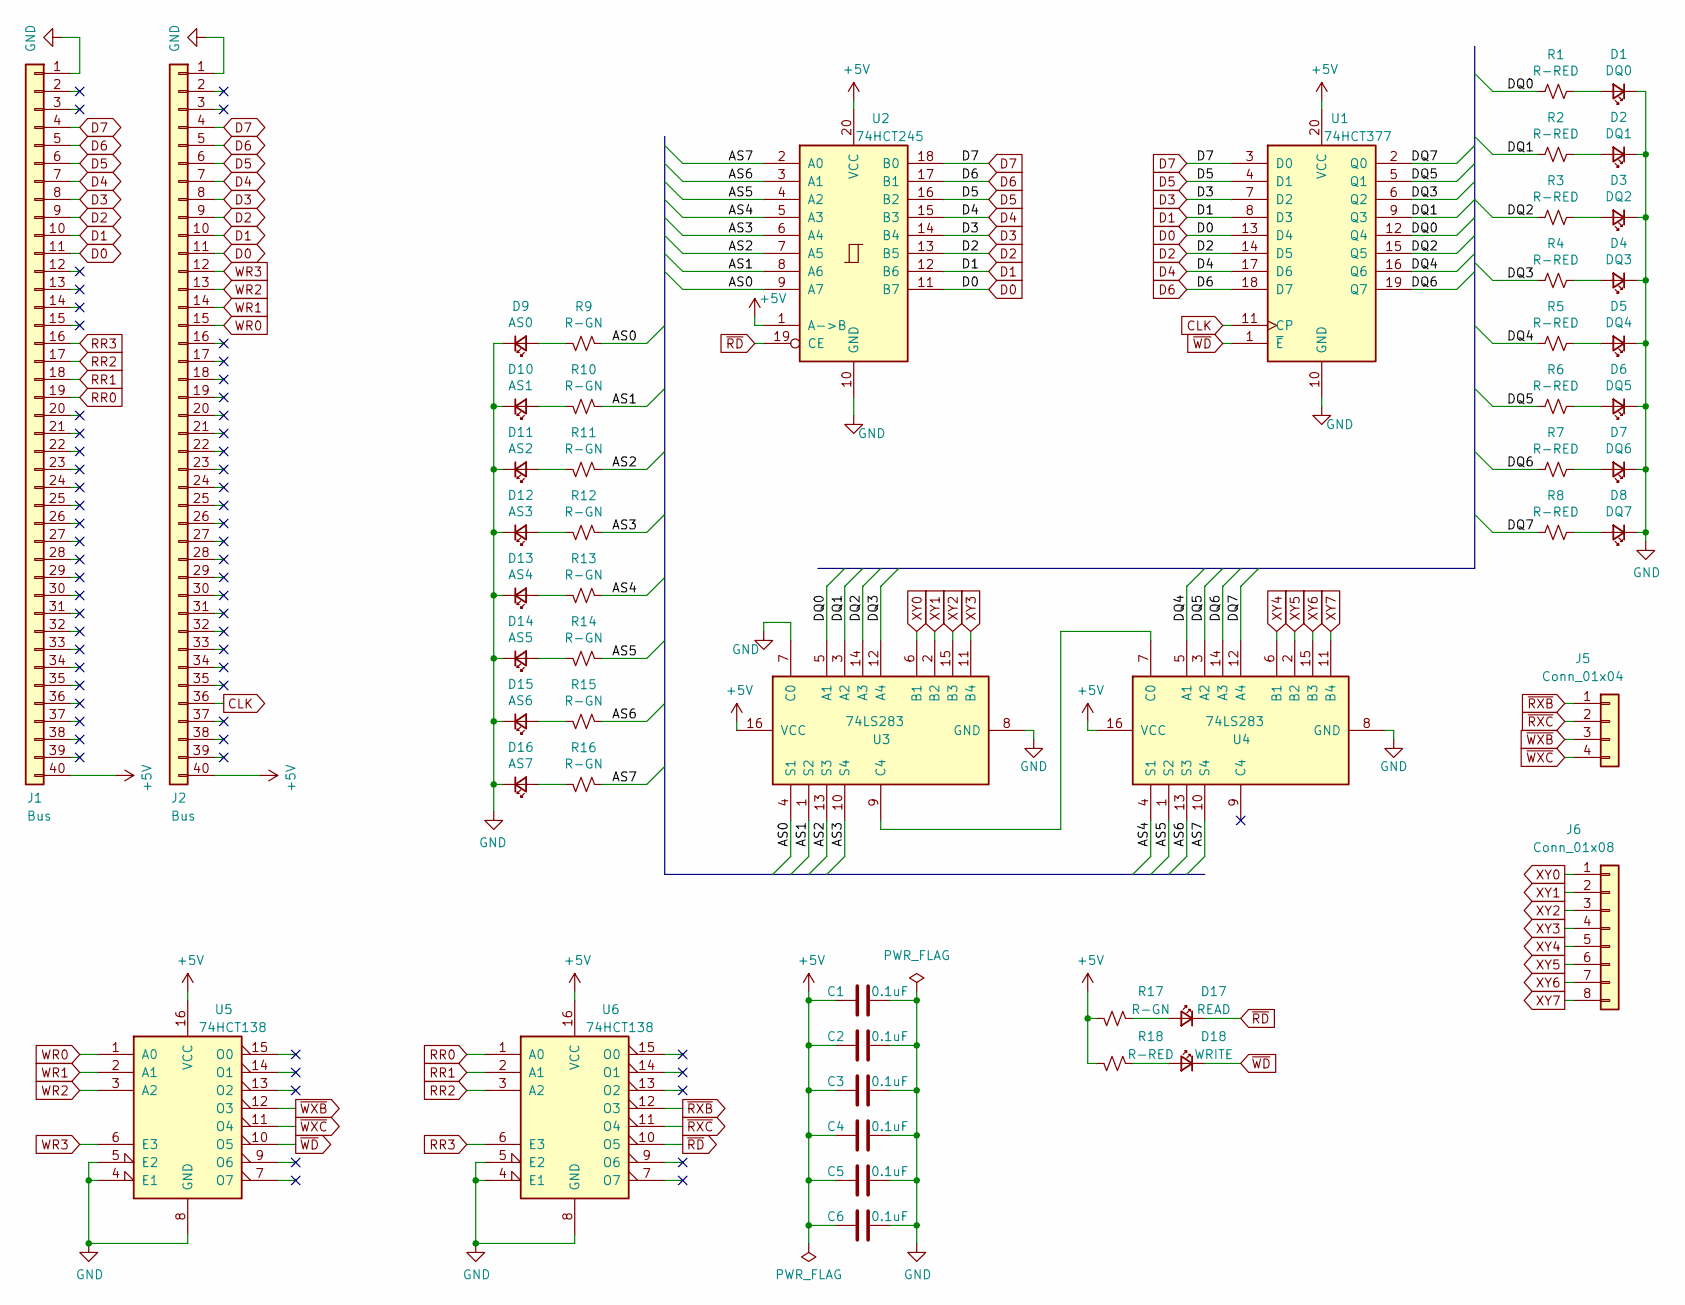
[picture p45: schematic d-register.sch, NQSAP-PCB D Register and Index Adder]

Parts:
C1, C2, C3, C4, C5, C6: 0.1uF; C_0805_2012Metric_Pad1.18x1.45mm_HandSolder
D1: DQ0; LED_0805_2012Metric_Pad1.15x1.40mm_HandSolder
D2: DQ1; LED_0805_2012Metric_Pad1.15x1.40mm_HandSolder
D3: DQ2; LED_0805_2012Metric_Pad1.15x1.40mm_HandSolder
D4: DQ3; LED_0805_2012Metric_Pad1.15x1.40mm_HandSolder
D5: DQ4; LED_0805_2012Metric_Pad1.15x1.40mm_HandSolder
D6: DQ5; LED_0805_2012Metric_Pad1.15x1.40mm_HandSolder
D7: DQ6; LED_0805_2012Metric_Pad1.15x1.40mm_HandSolder
D8: DQ7; LED_0805_2012Metric_Pad1.15x1.40mm_HandSolder
D9: AS0; LED_0805_2012Metric_Pad1.15x1.40mm_HandSolder
D10: AS1; LED_0805_2012Metric_Pad1.15x1.40mm_HandSolder
D11: AS2; LED_0805_2012Metric_Pad1.15x1.40mm_HandSolder
D12: AS3; LED_0805_2012Metric_Pad1.15x1.40mm_HandSolder
D13: AS4; LED_0805_2012Metric_Pad1.15x1.40mm_HandSolder
D14: AS5; LED_0805_2012Metric_Pad1.15x1.40mm_HandSolder
D15: AS6; LED_0805_2012Metric_Pad1.15x1.40mm_HandSolder
D16: AS7; LED_0805_2012Metric_Pad1.15x1.40mm_HandSolder
D17: READ; LED_0805_2012Metric_Pad1.15x1.40mm_HandSolder
D18: WRITE; LED_0805_2012Metric_Pad1.15x1.40mm_HandSolder
J1, J2: Bus; PinHeader_1x40_P2.54mm_Vertical
J5: Conn_01x04; PinHeader_1x04_P2.54mm_Vertical
J6: Conn_01x08; PinHeader_1x08_P2.54mm_Vertical
R1, R2, R3, R4, R5, R6, R7, R8, R18: R-RED; R_0805_2012Metric_Pad1.20x1.40mm_HandSolder
R9, R10, R11, R12, R13, R14, R15, R16, R17: R-GN; R_0805_2012Metric_Pad1.20x1.40mm_HandSolder
U1: 74HCT377; DIP-20_W7.62mm
U2: 74HCT245; DIP-20_W7.62mm
U3, U4: 74LS283; DIP-16_W7.62mm
U5, U6: 74HCT138; DIP-16_W7.62mm

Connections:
+5V: C1.2, C2.2, C3.2, C4.2, C5.2, C6.2, J1.40, J2.40, R17.1, R18.1, U1.20 (VCC), U2.1 (A->B), U2.20 (VCC), U3.16 (VCC), U4.16 (VCC), U5.16 (VCC), U6.16 (VCC)
/AS0: R9.2, U2.9 (A7), U3.4 (S1)
/AS1: R10.2, U2.8 (A6), U3.1 (S2)
/AS2: R11.2, U2.7 (A5), U3.13 (S3)
/AS3: R12.2, U2.6 (A4), U3.10 (S4)
/AS4: R13.2, U2.5 (A3), U4.4 (S1)
/AS5: R14.2, U2.4 (A2), U4.1 (S2)
/AS6: R15.2, U2.3 (A1), U4.13 (S3)
/AS7: R16.2, U2.2 (A0), U4.10 (S4)
/DQ0: R1.2, U1.12 (Q4), U3.5 (A1)
/DQ1: R2.2, U1.9 (Q3), U3.3 (A2)
/DQ2: R3.2, U1.15 (Q5), U3.14 (A3)
/DQ3: R4.2, U1.6 (Q2), U3.12 (A4)
/DQ4: R5.2, U1.16 (Q6), U4.5 (A1)
/DQ5: R6.2, U1.5 (Q1), U4.3 (A2)
/DQ6: R7.2, U1.19 (Q7), U4.14 (A3)
/DQ7: R8.2, U1.2 (Q0), U4.12 (A4)
CLK: J2.36, U1.11 (CP)
D0: J1.11, J2.11, U1.13 (D4), U2.11 (B7)
D1: J1.10, J2.10, U1.8 (D3), U2.12 (B6)
D2: J1.9, J2.9, U1.14 (D5), U2.13 (B5)
D3: J1.8, J2.8, U1.7 (D2), U2.14 (B4)
D4: J1.7, J2.7, U1.17 (D6), U2.15 (B3)
D5: J1.6, J2.6, U1.4 (D1), U2.16 (B2)
D6: J1.5, J2.5, U1.18 (D7), U2.17 (B1)
D7: J1.4, J2.4, U1.3 (D0), U2.18 (B0)
GND: C1.1, C2.1, C3.1, C4.1, C5.1, C6.1, D1.1 (K), D2.1 (K), D3.1 (K), D4.1 (K), D5.1 (K), D6.1 (K), D7.1 (K), D8.1 (K), D9.1 (K), D10.1 (K), D11.1 (K), D12.1 (K), D13.1 (K), D14.1 (K), D15.1 (K), D16.1 (K), J1.1, J2.1, U1.10 (GND), U2.10 (GND), U3.7 (C0), U3.8 (GND), U4.8 (GND), U5.4 (E1), U5.5 (E2), U5.8 (GND), U6.4 (E1), U6.5 (E2), U6.8 (GND)
unnamed: D1.2 (A), R1.1
unnamed: D2.2 (A), R2.1
unnamed: D3.2 (A), R3.1
unnamed: D4.2 (A), R4.1
unnamed: D5.2 (A), R5.1
unnamed: D6.2 (A), R6.1
unnamed: D7.2 (A), R7.1
unnamed: D8.2 (A), R8.1
unnamed: D9.2 (A), R9.1
unnamed: D10.2 (A), R10.1
unnamed: D11.2 (A), R11.1
unnamed: D12.2 (A), R12.1
unnamed: D13.2 (A), R13.1
unnamed: D14.2 (A), R14.1
unnamed: D15.2 (A), R15.1
unnamed: D16.2 (A), R16.1
unnamed: D17.2 (A), R17.2
unnamed: D18.2 (A), R18.2
unnamed: U3.9 (C4), U4.7 (C0)
RR0: J1.19, U6.1 (A0)
RR1: J1.18, U6.2 (A1)
RR2: J1.17, U6.3 (A2)
RR3: J1.16, U6.6 (E3)
WR0: J2.15, U5.1 (A0)
WR1: J2.14, U5.2 (A1)
WR2: J2.13, U5.3 (A2)
WR3: J2.12, U5.6 (E3)
XY0: J6.1, U3.6 (B1)
XY1: J6.2, U3.2 (B2)
XY2: J6.3, U3.15 (B3)
XY3: J6.4, U3.11 (B4)
XY4: J6.5, U4.6 (B1)
XY5: J6.6, U4.2 (B2)
XY6: J6.7, U4.15 (B3)
XY7: J6.8, U4.11 (B4)
~RD: D17.1 (K), U2.19 (CE), U6.10 (O5)
~RXB: J5.1, U6.12 (O3)
~RXC: J5.2, U6.11 (O4)
~WD: D18.1 (K), U1.1 (~E), U5.10 (O5)
~WXB: J5.3, U5.12 (O3)
~WXC: J5.4, U5.11 (O4)

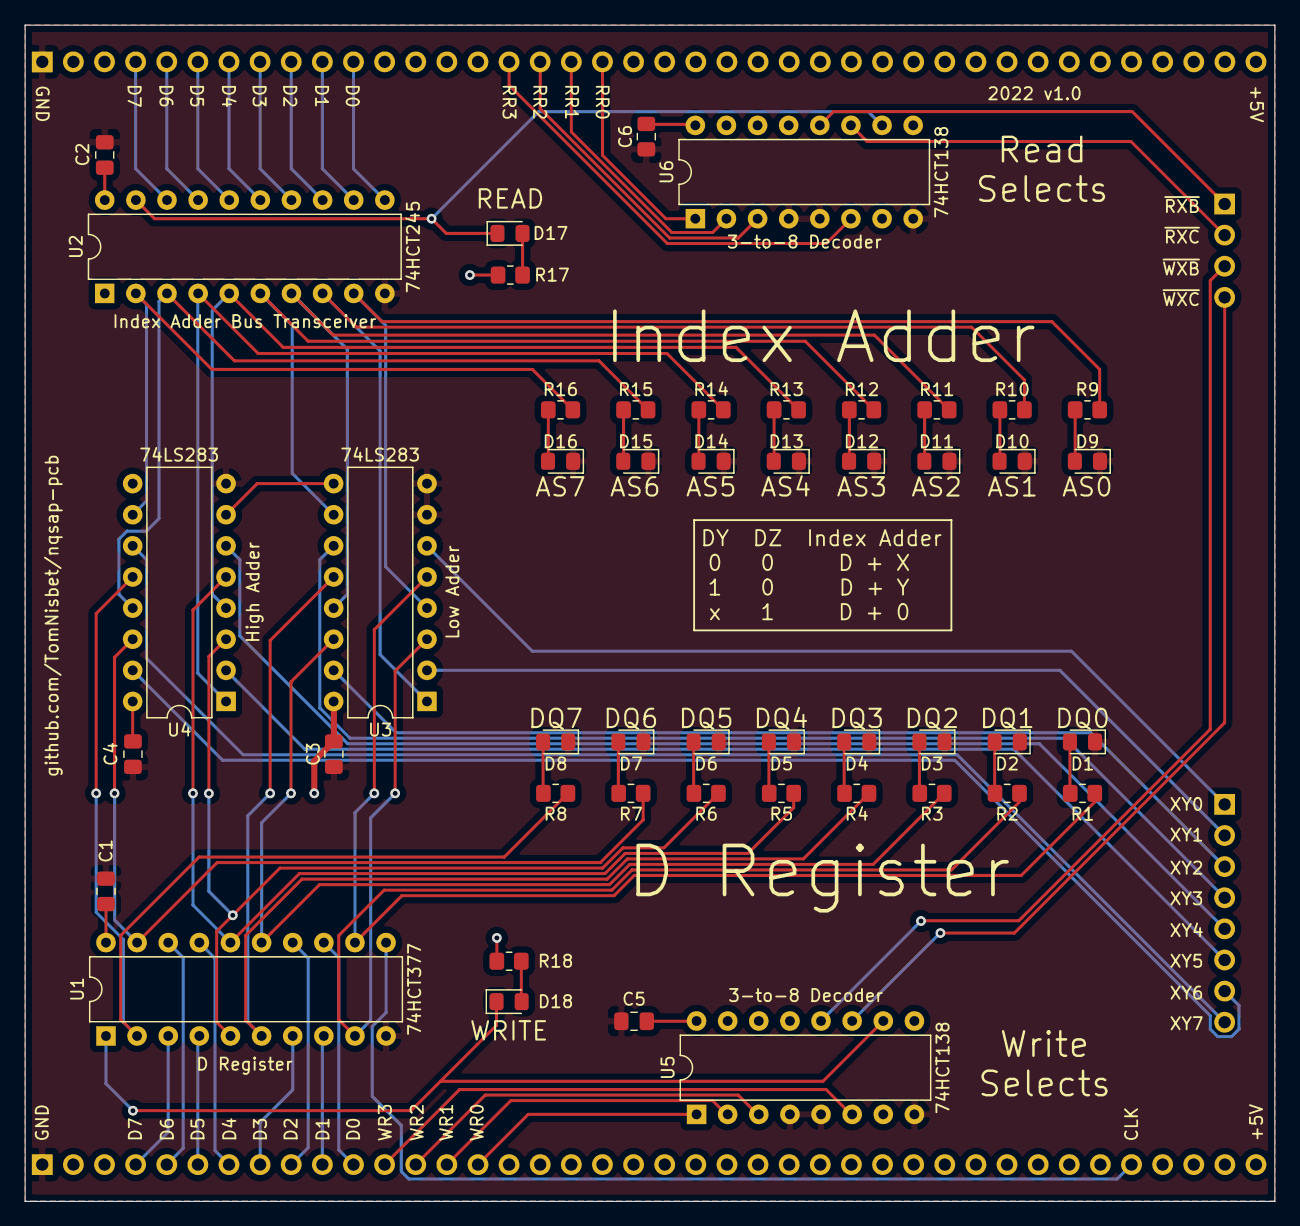
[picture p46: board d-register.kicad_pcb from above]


Board: 2 copper layers, 102.0 x 96.0 mm, 52 parts (4 on the bottom side), 68 nets.

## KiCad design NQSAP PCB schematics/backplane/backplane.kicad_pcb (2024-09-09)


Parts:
C1, C2, C3, C4, C5, C6, C7, C8, C9, C10, C11, C12: 10uF; C_Radial_D4.0mm_H5.0mm_P1.50mm
J1, J2, J3, J4, J5, J6, J7, J8, J9, J10: Bus; PinSocket_1x40_P2.54mm_Vertical
J19, J20, J21, J22, J23, J24, J25, J26: Conn_02x08; PinSocket_2x08_P2.54mm_Vertical
J27, J28, J29, J30: POWER IN; TerminalBlock_RND_205-00012_1x02_P5.00mm_Horizontal

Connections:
+5V: C1.1, C2.1, C3.1, C4.1, C5.1, C6.1, C7.1, C8.1, C9.1, C10.1, C11.1, C12.1, J1.40, J2.40, J3.40, J4.40, J5.40, J6.40, J7.40, J8.40, J9.40, J10.40, J27.2, J28.2, J29.1, J30.1; also elsewhere on the board
C0: J1.27, J2.27, J3.27, J4.27, J5.27, J6.27, J7.27, J8.27, J9.27, J10.27; also elsewhere on the board
C1: J1.26, J2.26, J3.26, J4.26, J5.26, J6.26, J7.26, J8.26, J9.26, J10.26; also elsewhere on the board
CC: J1.29, J2.29, J3.29, J4.29, J5.29, J6.29, J7.29, J8.29, J9.29, J10.29; also elsewhere on the board
CLK: J1.36, J2.36, J3.36, J4.36, J5.36, J6.36, J7.36, J8.36, J9.36, J10.36; also elsewhere on the board
CS: J1.28, J2.28, J3.28, J4.28, J5.28, J6.28, J7.28, J8.28, J9.28, J10.28; also elsewhere on the board
D0: J1.11, J2.11, J3.11, J4.11, J5.11, J6.11, J7.11, J8.11, J9.11, J10.11; also elsewhere on the board
D1: J1.10, J2.10, J3.10, J4.10, J5.10, J6.10, J7.10, J8.10, J9.10, J10.10; also elsewhere on the board
D2: J1.9, J2.9, J3.9, J4.9, J5.9, J6.9, J7.9, J8.9, J9.9, J10.9; also elsewhere on the board
D3: J1.8, J2.8, J3.8, J4.8, J5.8, J6.8, J7.8, J8.8, J9.8, J10.8; also elsewhere on the board
D4: J1.7, J2.7, J3.7, J4.7, J5.7, J6.7, J7.7, J8.7, J9.7, J10.7; also elsewhere on the board
D5: J1.6, J2.6, J3.6, J4.6, J5.6, J6.6, J7.6, J8.6, J9.6, J10.6; also elsewhere on the board
D6: J1.5, J2.5, J3.5, J4.5, J5.5, J6.5, J7.5, J8.5, J9.5, J10.5; also elsewhere on the board
D7: J1.4, J2.4, J3.4, J4.4, J5.4, J6.4, J7.4, J8.4, J9.4, J10.4; also elsewhere on the board
FB: J1.24, J2.24, J3.24, J4.24, J5.24, J6.24, J7.24, J8.24, J9.24, J10.24; also elsewhere on the board
FC: J1.23, J2.23, J3.23, J4.23, J5.23, J6.23, J7.23, J8.23, J9.23, J10.23; also elsewhere on the board
FN: J1.20, J2.20, J3.20, J4.20, J5.20, J6.20, J7.20, J8.20, J9.20, J10.20; also elsewhere on the board
FV: J1.21, J2.21, J3.21, J4.21, J5.21, J6.21, J7.21, J8.21, J9.21, J10.21; also elsewhere on the board
FZ: J1.22, J2.22, J3.22, J4.22, J5.22, J6.22, J7.22, J8.22, J9.22, J10.22; also elsewhere on the board
GND: C1.2, C2.2, C3.2, C4.2, C5.2, C6.2, C7.2, C8.2, C9.2, C10.2, C11.2, C12.2, J1.1, J2.1, J3.1, J4.1, J5.1, J6.1, J7.1, J8.1, J9.1, J10.1, J27.1, J28.1, J29.2, J30.2; also elsewhere on the board
JE: J1.33, J2.33, J3.33, J4.33, J5.33, J6.33, J7.33, J8.33, J9.33, J10.33; also elsewhere on the board
LF: J1.32, J2.32, J3.32, J4.32, J5.32, J6.32, J7.32, J8.32, J9.32, J10.32; also elsewhere on the board
M0: J1.31, J2.31, J3.31, J4.31, J5.31, J6.31, J7.31, J8.31, J9.31, J10.31; also elsewhere on the board
M1: J1.30, J2.30, J3.30, J4.30, J5.30, J6.30, J7.30, J8.30, J9.30, J10.30; also elsewhere on the board
N: J1.34, J2.34, J3.34, J4.34, J5.34, J6.34, J7.34, J8.34, J9.34, J10.34; also elsewhere on the board
unnamed: J19.1, J20.2
unnamed: J19.2, J20.1
unnamed: J19.3, J20.4
unnamed: J19.4, J20.3
unnamed: J19.5, J20.6
unnamed: J19.6, J20.5
unnamed: J19.7, J20.8
unnamed: J19.8, J20.7
unnamed: J19.9, J20.10
unnamed: J19.10, J20.9
unnamed: J19.11, J20.12
unnamed: J19.12, J20.11
unnamed: J19.13, J20.14
unnamed: J19.14, J20.13
unnamed: J19.15, J20.16
unnamed: J19.16, J20.15
unnamed: J21.1, J22.2
unnamed: J21.2, J22.1
unnamed: J21.3, J22.4
unnamed: J21.4, J22.3
unnamed: J21.5, J22.6
unnamed: J21.6, J22.5
unnamed: J21.7, J22.8
unnamed: J21.8, J22.7
unnamed: J21.9, J22.10
unnamed: J21.10, J22.9
unnamed: J21.11, J22.12
unnamed: J21.12, J22.11
unnamed: J21.13, J22.14
unnamed: J21.14, J22.13
unnamed: J21.15, J22.16
unnamed: J21.16, J22.15
unnamed: J23.1, J24.2
unnamed: J23.2, J24.1
unnamed: J23.3, J24.4
unnamed: J23.4, J24.3
unnamed: J23.5, J24.6
unnamed: J23.6, J24.5
unnamed: J23.7, J24.8
unnamed: J23.8, J24.7
unnamed: J23.9, J24.10
unnamed: J23.10, J24.9
unnamed: J23.11, J24.12
unnamed: J23.12, J24.11
unnamed: J23.13, J24.14
unnamed: J23.14, J24.13
unnamed: J23.15, J24.16
unnamed: J23.16, J24.15
unnamed: J25.1, J26.2
unnamed: J25.2, J26.1
unnamed: J25.3, J26.4
unnamed: J25.4, J26.3
unnamed: J25.5, J26.6
unnamed: J25.6, J26.5
unnamed: J25.7, J26.8
unnamed: J25.8, J26.7
unnamed: J25.9, J26.10
unnamed: J25.10, J26.9
unnamed: J25.11, J26.12
unnamed: J25.12, J26.11
unnamed: J25.13, J26.14
unnamed: J25.14, J26.13
unnamed: J25.15, J26.16
unnamed: J25.16, J26.15
PI: J1.35, J2.35, J3.35, J4.35, J5.35, J6.35, J7.35, J8.35, J9.35, J10.35; also elsewhere on the board
RR0: J1.19, J2.19, J3.19, J4.19, J5.19, J6.19, J7.19, J8.19, J9.19, J10.19; also elsewhere on the board
RR1: J1.18, J2.18, J3.18, J4.18, J5.18, J6.18, J7.18, J8.18, J9.18, J10.18; also elsewhere on the board
RR2: J1.17, J2.17, J3.17, J4.17, J5.17, J6.17, J7.17, J8.17, J9.17, J10.17; also elsewhere on the board
RR3: J1.16, J2.16, J3.16, J4.16, J5.16, J6.16, J7.16, J8.16, J9.16, J10.16; also elsewhere on the board
SE: J1.25, J2.25, J3.25, J4.25, J5.25, J6.25, J7.25, J8.25, J9.25, J10.25; also elsewhere on the board
WR0: J1.15, J2.15, J3.15, J4.15, J5.15, J6.15, J7.15, J8.15, J9.15, J10.15; also elsewhere on the board
WR1: J1.14, J2.14, J3.14, J4.14, J5.14, J6.14, J7.14, J8.14, J9.14, J10.14; also elsewhere on the board
WR2: J1.13, J2.13, J3.13, J4.13, J5.13, J6.13, J7.13, J8.13, J9.13, J10.13; also elsewhere on the board
WR3: J1.12, J2.12, J3.12, J4.12, J5.12, J6.12, J7.12, J8.12, J9.12, J10.12; also elsewhere on the board
nc1: J1.2, J2.2, J3.2, J4.2, J5.2, J6.2, J7.2, J8.2, J9.2, J10.2; also elsewhere on the board
nc2: J1.3, J2.3, J3.3, J4.3, J5.3, J6.3, J7.3, J8.3, J9.3, J10.3; also elsewhere on the board
nc3: J1.37, J2.37, J3.37, J4.37, J5.37, J6.37, J7.37, J8.37, J9.37, J10.37; also elsewhere on the board
~JMP: J1.38, J2.38, J3.38, J4.38, J5.38, J6.38, J7.38, J8.38, J9.38, J10.38; also elsewhere on the board
~RST: J1.39, J2.39, J3.39, J4.39, J5.39, J6.39, J7.39, J8.39, J9.39, J10.39; also elsewhere on the board

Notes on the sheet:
Additional Bus Connectors
18 Bus Connectors Total

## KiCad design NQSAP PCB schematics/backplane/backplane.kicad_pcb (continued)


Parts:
J11, J12, J13, J14, J15, J16, J17, J18: Bus; PinSocket_1x40_P2.54mm_Vertical

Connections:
+5V: J11.40, J12.40, J13.40, J14.40, J15.40, J16.40, J17.40, J18.40; also elsewhere on the board
C0: J11.27, J12.27, J13.27, J14.27, J15.27, J16.27, J17.27, J18.27; also elsewhere on the board
C1: J11.26, J12.26, J13.26, J14.26, J15.26, J16.26, J17.26, J18.26; also elsewhere on the board
CC: J11.29, J12.29, J13.29, J14.29, J15.29, J16.29, J17.29, J18.29; also elsewhere on the board
CLK: J11.36, J12.36, J13.36, J14.36, J15.36, J16.36, J17.36, J18.36; also elsewhere on the board
CS: J11.28, J12.28, J13.28, J14.28, J15.28, J16.28, J17.28, J18.28; also elsewhere on the board
D0: J11.11, J12.11, J13.11, J14.11, J15.11, J16.11, J17.11, J18.11; also elsewhere on the board
D1: J11.10, J12.10, J13.10, J14.10, J15.10, J16.10, J17.10, J18.10; also elsewhere on the board
D2: J11.9, J12.9, J13.9, J14.9, J15.9, J16.9, J17.9, J18.9; also elsewhere on the board
D3: J11.8, J12.8, J13.8, J14.8, J15.8, J16.8, J17.8, J18.8; also elsewhere on the board
D4: J11.7, J12.7, J13.7, J14.7, J15.7, J16.7, J17.7, J18.7; also elsewhere on the board
D5: J11.6, J12.6, J13.6, J14.6, J15.6, J16.6, J17.6, J18.6; also elsewhere on the board
D6: J11.5, J12.5, J13.5, J14.5, J15.5, J16.5, J17.5, J18.5; also elsewhere on the board
D7: J11.4, J12.4, J13.4, J14.4, J15.4, J16.4, J17.4, J18.4; also elsewhere on the board
FB: J11.24, J12.24, J13.24, J14.24, J15.24, J16.24, J17.24, J18.24; also elsewhere on the board
FC: J11.23, J12.23, J13.23, J14.23, J15.23, J16.23, J17.23, J18.23; also elsewhere on the board
FN: J11.20, J12.20, J13.20, J14.20, J15.20, J16.20, J17.20, J18.20; also elsewhere on the board
FV: J11.21, J12.21, J13.21, J14.21, J15.21, J16.21, J17.21, J18.21; also elsewhere on the board
FZ: J11.22, J12.22, J13.22, J14.22, J15.22, J16.22, J17.22, J18.22; also elsewhere on the board
GND: J11.1, J12.1, J13.1, J14.1, J15.1, J16.1, J17.1, J18.1; also elsewhere on the board
JE: J11.33, J12.33, J13.33, J14.33, J15.33, J16.33, J17.33, J18.33; also elsewhere on the board
LF: J11.32, J12.32, J13.32, J14.32, J15.32, J16.32, J17.32, J18.32; also elsewhere on the board
M0: J11.31, J12.31, J13.31, J14.31, J15.31, J16.31, J17.31, J18.31; also elsewhere on the board
M1: J11.30, J12.30, J13.30, J14.30, J15.30, J16.30, J17.30, J18.30; also elsewhere on the board
N: J11.34, J12.34, J13.34, J14.34, J15.34, J16.34, J17.34, J18.34; also elsewhere on the board
PI: J11.35, J12.35, J13.35, J14.35, J15.35, J16.35, J17.35, J18.35; also elsewhere on the board
RR0: J11.19, J12.19, J13.19, J14.19, J15.19, J16.19, J17.19, J18.19; also elsewhere on the board
RR1: J11.18, J12.18, J13.18, J14.18, J15.18, J16.18, J17.18, J18.18; also elsewhere on the board
RR2: J11.17, J12.17, J13.17, J14.17, J15.17, J16.17, J17.17, J18.17; also elsewhere on the board
RR3: J11.16, J12.16, J13.16, J14.16, J15.16, J16.16, J17.16, J18.16; also elsewhere on the board
SE: J11.25, J12.25, J13.25, J14.25, J15.25, J16.25, J17.25, J18.25; also elsewhere on the board
WR0: J11.15, J12.15, J13.15, J14.15, J15.15, J16.15, J17.15, J18.15; also elsewhere on the board
WR1: J11.14, J12.14, J13.14, J14.14, J15.14, J16.14, J17.14, J18.14; also elsewhere on the board
WR2: J11.13, J12.13, J13.13, J14.13, J15.13, J16.13, J17.13, J18.13; also elsewhere on the board
WR3: J11.12, J12.12, J13.12, J14.12, J15.12, J16.12, J17.12, J18.12; also elsewhere on the board
nc1: J11.2, J12.2, J13.2, J14.2, J15.2, J16.2, J17.2, J18.2; also elsewhere on the board
nc2: J11.3, J12.3, J13.3, J14.3, J15.3, J16.3, J17.3, J18.3; also elsewhere on the board
nc3: J11.37, J12.37, J13.37, J14.37, J15.37, J16.37, J17.37, J18.37; also elsewhere on the board
~JMP: J11.38, J12.38, J13.38, J14.38, J15.38, J16.38, J17.38, J18.38; also elsewhere on the board
~RST: J11.39, J12.39, J13.39, J14.39, J15.39, J16.39, J17.39, J18.39; also elsewhere on the board

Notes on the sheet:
Additional Backplane Connectors


Board: 2 copper layers, 360.0 x 128.0 mm, 42 parts (0 on the bottom side), 104 nets.

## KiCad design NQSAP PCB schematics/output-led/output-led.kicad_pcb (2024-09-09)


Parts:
C1, C2: 0.1uF; C_0805_2012Metric_Pad1.18x1.45mm_HandSolder
D1: LATCH; LED_0805_2012Metric_Pad1.15x1.40mm_HandSolder
J1, J2: Bus; PinHeader_1x40_P2.54mm_Vertical
J3: AVR PGM; PinHeader_2x03_P2.54mm_Vertical
J4: 7-Segment Common Anode Display; PinSocket_1x12_P2.54mm_Vertical
J5, J6: support; PinSocket_1x02_P2.54mm_Vertical
R1: R_RED; R_0805_2012Metric_Pad1.20x1.40mm_HandSolder
R2, R3, R4, R5: R_SEG; R_0805_2012Metric_Pad1.20x1.40mm_HandSolder
SW1: Mode 0; Switch_Slide_11.6x4mm_EG1218
SW2: Mode 1; Switch_Slide_11.6x4mm_EG1218
U1: ATmega328P; DIP-28_W7.62mm
U2: 74HCT138; DIP-16_W7.62mm

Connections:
+5V: C1.2, C2.2, J1.40, J2.40, J3.2, R1.2, SW1.1 (A), SW2.1 (A), U1.7 (VCC), U1.20 (AVCC), U2.16 (VCC)
/mode0: SW1.2 (B), U1.27 (PC4)
/mode1: SW2.2 (B), U1.28 (PC5)
/~latch: D1.1 (K), U1.13 (PD7), U2.13 (O2)
D0: J1.11, U1.14 (PB0)
D1: J1.10, U1.15 (PB1)
D2: J1.9, U1.16 (PB2)
D3: J1.8, J3.4, U1.17 (PB3)
D4: J1.7, J3.1, U1.18 (PB4)
D5: J1.6, J3.3, U1.19 (PB5)
D6: J1.5, U1.9 (XTAL1/PB6)
D7: J1.4, U1.10 (XTAL2/PB7)
GND: C1.1, C2.1, J1.1, J2.1, J3.6, SW1.3 (C), SW2.3 (C), U1.8 (GND), U1.22 (GND), U2.4 (E1), U2.5 (E2), U2.8 (GND)
L1: R2.2, U1.23 (PC0)
L2: R3.2, U1.24 (PC1)
L3: R4.2, U1.25 (PC2)
L4: R5.2, U1.26 (PC3)
unnamed: D1.2 (A), R1.1
unnamed: J4.1, R2.1
unnamed: J4.2, R3.1
unnamed: J4.3, R4.1
unnamed: J4.4, R5.1
SA: J4.5, U1.2 (PD0)
SB: J4.6, U1.3 (PD1)
SC: J4.7, U1.4 (PD2)
SD: J4.8, U1.5 (PD3)
SE: J4.9, U1.6 (PD4)
SF: J4.10, U1.11 (PD5)
SG: J4.11, U1.12 (PD6)
WR0: J1.15, U2.1 (A0)
WR1: J1.14, U2.2 (A1)
WR2: J1.13, U2.3 (A2)
WR3: J1.12, U2.6 (E3)
~RST: J1.39, J3.5, U1.1 (~RESET~/PC6)



Board: 2 copper layers, 102.0 x 96.0 mm, 18 parts (2 on the bottom side), 34 nets.

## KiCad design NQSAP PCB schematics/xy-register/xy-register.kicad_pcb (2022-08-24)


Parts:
C1, C2, C3, C4, C5, C6: 0.1uF; C_0805_2012Metric_Pad1.18x1.45mm_HandSolder
D1: X0; LED_0805_2012Metric_Pad1.15x1.40mm_HandSolder
D2: X1; LED_0805_2012Metric_Pad1.15x1.40mm_HandSolder
D3: X2; LED_0805_2012Metric_Pad1.15x1.40mm_HandSolder
D4: X3; LED_0805_2012Metric_Pad1.15x1.40mm_HandSolder
D5: X4; LED_0805_2012Metric_Pad1.15x1.40mm_HandSolder
D6: X5; LED_0805_2012Metric_Pad1.15x1.40mm_HandSolder
D7: X6; LED_0805_2012Metric_Pad1.15x1.40mm_HandSolder
D8: X7; LED_0805_2012Metric_Pad1.15x1.40mm_HandSolder
D9: Y0; LED_0805_2012Metric_Pad1.15x1.40mm_HandSolder
D10: Y1; LED_0805_2012Metric_Pad1.15x1.40mm_HandSolder
D11: Y2; LED_0805_2012Metric_Pad1.15x1.40mm_HandSolder
D12: Y3; LED_0805_2012Metric_Pad1.15x1.40mm_HandSolder
D13: Y4; LED_0805_2012Metric_Pad1.15x1.40mm_HandSolder
D14: Y5; LED_0805_2012Metric_Pad1.15x1.40mm_HandSolder
D15: Y6; LED_0805_2012Metric_Pad1.15x1.40mm_HandSolder
D16: Y7; LED_0805_2012Metric_Pad1.15x1.40mm_HandSolder
D17, D18: READ; LED_0805_2012Metric_Pad1.15x1.40mm_HandSolder
D19, D20: WRITE; LED_0805_2012Metric_Pad1.15x1.40mm_HandSolder
D21: DZ; LED_0805_2012Metric_Pad1.15x1.40mm_HandSolder
D22: DY; LED_0805_2012Metric_Pad1.15x1.40mm_HandSolder
J1, J2: Bus; PinHeader_1x40_P2.54mm_Vertical
J5: Conn_01x04; PinHeader_1x04_P2.54mm_Vertical
J6: Conn_01x08; PinHeader_1x08_P2.54mm_Vertical
R1, R2, R3, R4, R5, R6, R7, R8, R9, R10, R11, R12, R13, R14, R15, R16, R19, R20: R-RED; R_0805_2012Metric_Pad1.20x1.40mm_HandSolder
R17, R18: R-GN; R_0805_2012Metric_Pad1.20x1.40mm_HandSolder
R21, R22: R-YEL; R_0805_2012Metric_Pad1.20x1.40mm_HandSolder
U1, U3: 74HCT377; DIP-20_W7.62mm
U2, U4: 74HCT245; DIP-20_W7.62mm
U5, U6: 74HCT157; DIP-16_W7.62mm

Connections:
+5V: C1.2, C2.2, C3.2, C4.2, C5.2, C6.2, J1.40, J2.40, R17.1, R18.1, R19.2, R20.1, U1.20 (VCC), U2.1 (A->B), U2.20 (VCC), U3.20 (VCC), U4.20 (VCC), U5.16 (VCC), U6.16 (VCC)
/X0: R1.2, U1.12 (Q4), U2.9 (A7), U6.11 (I0c)
/X1: R2.2, U1.9 (Q3), U2.8 (A6), U6.5 (I0b)
/X2: R3.2, U1.15 (Q5), U2.7 (A5), U6.14 (I0d)
/X3: R4.2, U1.6 (Q2), U2.6 (A4), U6.2 (I0a)
/X4: R5.2, U1.16 (Q6), U2.5 (A3), U5.11 (I0c)
/X5: R6.2, U1.5 (Q1), U2.4 (A2), U5.5 (I0b)
/X6: R7.2, U1.19 (Q7), U2.3 (A1), U5.14 (I0d)
/X7: R8.2, U1.2 (Q0), U2.2 (A0), U5.2 (I0a)
/Y0: R9.2, U3.12 (Q4), U4.11 (B7), U6.10 (I1c)
/Y1: R10.2, U3.9 (Q3), U4.12 (B6), U6.6 (I1b)
/Y2: R11.2, U3.15 (Q5), U4.13 (B5), U6.13 (I1d)
/Y3: R12.2, U3.6 (Q2), U4.14 (B4), U6.3 (I1a)
/Y4: R13.2, U3.16 (Q6), U4.15 (B3), U5.10 (I1c)
/Y5: R14.2, U3.5 (Q1), U4.16 (B2), U5.6 (I1b)
/Y6: R15.2, U3.19 (Q7), U4.17 (B1), U5.13 (I1d)
/Y7: R16.2, U3.2 (Q0), U4.18 (B0), U5.3 (I1a)
CLK: J1.36, J2.36, U1.11 (CP), U3.11 (CP)
D0: J1.11, J2.11, U1.13 (D4), U2.11 (B7), U3.13 (D4), U4.9 (A7)
D1: J1.10, J2.10, U1.8 (D3), U2.12 (B6), U3.8 (D3), U4.8 (A6)
D2: J1.9, J2.9, U1.14 (D5), U2.13 (B5), U3.14 (D5), U4.7 (A5)
D3: J1.8, J2.8, U1.7 (D2), U2.14 (B4), U3.7 (D2), U4.6 (A4)
D4: J1.7, J2.7, U1.17 (D6), U2.15 (B3), U3.17 (D6), U4.5 (A3)
D5: J1.6, J2.6, U1.4 (D1), U2.16 (B2), U3.4 (D1), U4.4 (A2)
D6: J1.5, J2.5, U1.18 (D7), U2.17 (B1), U3.18 (D7), U4.3 (A1)
D7: J1.4, J2.4, U1.3 (D0), U2.18 (B0), U3.3 (D0), U4.2 (A0)
DY: J2.27, R22.2, U5.1 (S), U6.1 (S)
DZ: J2.26, R21.2, U5.15 (E), U6.15 (E)
GND: C1.1, C2.1, C3.1, C4.1, C5.1, C6.1, D1.1 (K), D2.1 (K), D3.1 (K), D4.1 (K), D5.1 (K), D6.1 (K), D7.1 (K), D8.1 (K), D9.1 (K), D10.1 (K), D11.1 (K), D12.1 (K), D13.1 (K), D14.1 (K), D15.1 (K), D16.1 (K), D21.1 (K), D22.1 (K), J1.1, J2.1, U1.10 (GND), U2.10 (GND), U3.10 (GND), U4.1 (A->B), U4.10 (GND), U5.8 (GND), U6.8 (GND)
unnamed: D1.2 (A), R1.1
unnamed: D2.2 (A), R2.1
unnamed: D3.2 (A), R3.1
unnamed: D4.2 (A), R4.1
unnamed: D5.2 (A), R5.1
unnamed: D6.2 (A), R6.1
unnamed: D7.2 (A), R7.1
unnamed: D8.2 (A), R8.1
unnamed: D9.2 (A), R9.1
unnamed: D10.2 (A), R10.1
unnamed: D11.2 (A), R11.1
unnamed: D12.2 (A), R12.1
unnamed: D13.2 (A), R13.1
unnamed: D14.2 (A), R14.1
unnamed: D15.2 (A), R15.1
unnamed: D16.2 (A), R16.1
unnamed: D17.2 (A), R17.2
unnamed: D18.2 (A), R18.2
unnamed: D19.2 (A), R19.1
unnamed: D20.2 (A), R20.2
unnamed: D21.2 (A), R21.1
unnamed: D22.2 (A), R22.1
XY0: J6.1, U6.9 (Zc)
XY1: J6.2, U6.7 (Zb)
XY2: J6.3, U6.12 (Zd)
XY3: J6.4, U6.4 (Za)
XY4: J6.5, U5.9 (Zc)
XY5: J6.6, U5.7 (Zb)
XY6: J6.7, U5.12 (Zd)
XY7: J6.8, U5.4 (Za)
~RX: D17.1 (K), J5.1, U2.19 (CE)
~RY: D18.1 (K), J5.2, U4.19 (CE)
~WX: D19.1 (K), J5.3, U1.1 (~E)
~WY: D20.1 (K), J5.4, U3.1 (~E)



Board: 2 copper layers, 102.0 x 96.0 mm, 60 parts (4 on the bottom side), 63 nets.

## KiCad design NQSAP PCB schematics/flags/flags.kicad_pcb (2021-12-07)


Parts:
C1, C2, C3, C4, C5, C6, C7: 0.1uF; C_0805_2012Metric_Pad1.18x1.45mm_HandSolder
D1: C; LED_0805_2012Metric_Pad1.15x1.40mm_HandSolder
D2: Z; LED_0805_2012Metric_Pad1.15x1.40mm_HandSolder
D3: V; LED_0805_2012Metric_Pad1.15x1.40mm_HandSolder
D4: N; LED_0805_2012Metric_Pad1.15x1.40mm_HandSolder
D5: JUMP; LED_0805_2012Metric_Pad1.15x1.40mm_HandSolder
J1, J2: Bus; PinHeader_1x40_P2.54mm_Vertical
J3, J4: IC-TL; PinHeader_1x08_P2.54mm_Vertical
R1, R2, R3, R4: R_YEL; R_0805_2012Metric_Pad1.20x1.40mm_HandSolder
R5: R_RED; R_0805_2012Metric_Pad1.20x1.40mm_HandSolder
R6: 1K; R_0805_2012Metric_Pad1.20x1.40mm_HandSolder
U1: 74HCT157; DIP-16_W7.62mm
U2, U3: 74HCT74; DIP-14_W7.62mm
U4: 74HCT151; DIP-16_W7.62mm
U5: 74HCT245; DIP-20_W7.62mm
U6: 74HCT08; DIP-14_W7.62mm
U7: 74HCT02; DIP-14_W7.62mm

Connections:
/FC-D: U1.9 (Zc), U2.12 (D)
/FN-D: U1.4 (Za), U3.2 (D)
/FV-D: U1.12 (Zd), U3.12 (D)
/FZ-D: U1.7 (Zb), U2.2 (D)
C: U2.9 (Q), U4.4 (I0), U5.11 (B7), U7.5
CC: J2.29, U7.2
CLK: J1.36, U6.2, U6.4, U6.10, U6.12
CS: J2.28, U7.6
D0: J1.11, J2.11, U1.10 (I1c), U5.9 (A7)
D1: J1.10, J2.10, U1.6 (I1b), U5.8 (A6)
D2: J2.9, U5.7 (A5)
D3: J2.8, U5.6 (A4)
D4: J2.7, U5.5 (A3)
D5: J2.6, U5.4 (A2)
D6: J1.5, J2.5, U1.13 (I1d), U5.3 (A1)
D7: J1.4, J2.4, U1.2 (I0a), U1.3 (I1a), U5.2 (A0)
FB: J1.24, U1.1 (S)
FC: J1.23, U6.9
FC-IN: J3.2, U1.11 (I0c)
FN: J1.20, U6.1
FV: J1.21, U6.13
FV-IN: J3.1, U1.14 (I0d)
FZ: J1.22, U6.5
FZ-IN: J3.3, U1.5 (I0b)
GND: C1.1, C2.1, C3.1, C4.1, C5.1, C6.1, C7.1, J1.1, J2.1, R6.2, U1.8 (GND), U1.15 (E), U2.7 (GND), U3.7 (GND), U4.8 (GND), U5.1 (A->B), U5.10 (GND), U6.7 (GND), U7.7 (GND)
H-CIN: J4.7, U7.1, U7.11, U7.12
IR-Q0: J4.6, U4.11 (S0)
IR-Q1: J4.5, U4.10 (S1)
IR-Q2: J4.4, U4.9 (S2)
JE: J2.33, U7.8, U7.9
L-CIN: J4.8, U7.13
N: U3.5 (Q), U4.13 (I6), U5.18 (B0)
unnamed: D1.1 (K), R1.1
unnamed: D2.1 (K), R2.1
unnamed: D3.1 (K), R3.1
unnamed: D4.1 (K), R4.1
unnamed: D5.1 (K), R5.1
unnamed: R6.1, U5.13 (B5), U5.14 (B4), U5.15 (B3), U5.16 (B2)
unnamed: U2.3 (C), U6.6
unnamed: U2.11 (C), U6.8
unnamed: U3.3 (C), U6.3
unnamed: U3.11 (C), U6.11
unnamed: U4.7 (~E), U7.10
unnamed: U7.3, U7.4
V: U3.9 (Q), U4.15 (I4), U5.17 (B1)
VCC: C1.2, C2.2, C3.2, C4.2, C5.2, C6.2, C7.2, D1.2 (A), D2.2 (A), D3.2 (A), D4.2 (A), D5.2 (A), J1.40, J2.40, U1.16 (VCC), U2.1 (~R), U2.4 (~S), U2.10 (~S), U2.13 (~R), U2.14 (VCC), U3.1 (~R), U3.4 (~S), U3.10 (~S), U3.13 (~R), U3.14 (VCC), U4.16 (VCC), U5.20 (VCC), U6.14 (VCC), U7.14 (VCC)
Z: U2.5 (Q), U4.2 (I2), U5.12 (B6)
~C: R1.2, U2.8 (~Q), U4.3 (I1)
~JMP: J1.38, J2.38, R5.2, U4.6 (~Z)
~N: R4.2, U3.6 (~Q), U4.12 (I7)
~RF: J4.1, U5.19 (CE)
~V: R3.2, U3.8 (~Q), U4.14 (I5)
~Z: R2.2, U2.6 (~Q), U4.1 (I3)

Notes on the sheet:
Jump Control



Board: 2 copper layers, 102.0 x 96.0 mm, 29 parts (4 on the bottom side), 53 nets.

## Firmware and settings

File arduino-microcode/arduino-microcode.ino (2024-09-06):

#include "Arduino.h"

static const char * MY_VERSION = "1.1";

// Must define one of these to select the PROM type
#define PROM_IS_28C256
//#define PROM_IS_SST39SF

// IO lines for the EEPROM device control
// Pins D2..D9 are used for the data bus.
#define WE              A0
#define CE              A1
#define OE              A2
#define ADDR_CLK_HI     A3
#define ADDR_CLK_LO     A4
#define ADDR_DATA       A5

#define RED_LED         13


void burnMicrocodeRoms();
void initializeProm();
byte readByte(uint32_t address);
bool burnByte(byte value, uint32_t address);
bool burnBlock(byte data[], uint32_t len, uint32_t address);
bool waitForWriteCycleEnd(byte lastValue);
void setByte(byte value, uint32_t address);
void setAddress(uint32_t address);
void setAddressRegister(uint8_t clkPin, byte addr);
bool writeData(byte data[], uint32_t len, uint32_t address);
void setDataBusMode(uint8_t mode);
byte readDataBus();
void writeDataBus(byte data);

// Set the status of the device control pins
static void enableChip()       { digitalWrite(CE, LOW); }
static void disableChip()      { digitalWrite(CE, HIGH);}
static void enableOutput()     { digitalWrite(OE, LOW); }
static void disableOutput()    { digitalWrite(OE, HIGH);}
static void enableWrite()      { digitalWrite(WE, LOW); }
static void disableWrite()     { digitalWrite(WE, HIGH);}


void setup() {
    // The address control pins are always outputs.
    pinMode(ADDR_DATA, OUTPUT);
    pinMode(ADDR_CLK_LO, OUTPUT);
    pinMode(ADDR_CLK_HI, OUTPUT);
    digitalWrite(ADDR_DATA, LOW);
    digitalWrite(ADDR_CLK_LO, LOW);
    digitalWrite(ADDR_CLK_HI, LOW);
    DDRB |= 0x1c; // Set D10..D12 as outputs

    // To save time, the setAddress only writes the hi byte if it has changed.
    // The value used to detect the change is initialized to a non-zero value,
    // so set an initial address to avoid the the case where the first address
    // written is the 'magic' initial address.
    setAddress(0x0000);

    // Define the data bus as input initially so that it does not put out a
    // signal that could collide with output on the data pins of the EEPROM.
    setDataBusMode(INPUT);

    // Define the EEPROM control pins as output, making sure they are all
    // in the disabled state.
    digitalWrite(OE, HIGH);
    pinMode(OE, OUTPUT);
    digitalWrite(CE, HIGH);
    pinMode(CE, OUTPUT);
    digitalWrite(WE, HIGH);
    pinMode(WE, OUTPUT);

    pinMode(RED_LED, OUTPUT);

    Serial.begin(115200);
    Serial.print("\nBurning NQSAP-PCB microcode version ");
    Serial.println(MY_VERSION);
    initializeProm();
    delay(100);
    burnMicrocodeRoms();
    Serial.println(F("burn complete"));
}

void loop() {
    digitalWrite(RED_LED, HIGH);
    delay(500);
    digitalWrite(RED_LED, LOW);
    delay(500);
}

void fail() {
    Serial.println(F("Write FAILED"));
    while (1) {
      digitalWrite(RED_LED, HIGH);
      delay(200);
      digitalWrite(RED_LED, LOW);
      delay(200);
      digitalWrite(RED_LED, HIGH);
      delay(200);
      digitalWrite(RED_LED, LOW);
      delay(200);
      digitalWrite(RED_LED, HIGH);
      delay(200);
      digitalWrite(RED_LED, LOW);
      delay(600);
    }
}

// Get rid of Arduino macro definitions that conflict with control signal names
#undef PI

//               ROM2    ROM1    ROM0
//             +------++------++------+
// ROM2        WWWWRRRR7654321076543210
#define W3   0b100000000000000000000000L  // 1 Write bit 3
#define W2   0b010000000000000000000000L  // 1 Write bit 2
#define W1   0b001000000000000000000000L  // 1 Write bit 1
#define W0   0b000100000000000000000000L  // 1 Write bit 0
#define R3   0b000010000000000000000000L  // 8 Read bit 3
#define R2   0b000001000000000000000000L  // 8 Read bit 2
#define R1   0b000000100000000000000000L  // 8 Read bit 1
#define R0   0b000000010000000000000000L  // 8 Read bit 0

// ROM1
#define FN   0b000000001000000000000000L  // 80 load Negative flag
#define FV   0b000000000100000000000000L  // 40 load oVerflow flag
#define FZ   0b000000000010000000000000L  // 20 load Zero flag
#define FC   0b000000000001000000000000L  // 10 load Carry flag
#define FB   0b000000000000100000000000L  // 08 use bus values to load Flags
#define SCE  0b000000000000010000000000L  // 04 SP Count Enable
#define C1   0b000000000000001000000000L  // 02 Carry source select 1
#define C0   0b000000000000000100000000L  // 01 Carry source select 0

// ROM0
#define CS   0b000000000000000010000000L  // 80 Carry flag force Set
#define CC   0b000000000000000001000000L  // 40 Carry flag force Clear
#define M1   0b000000000000000000100000L  // 20 Memory select 1
#define M0   0b000000000000000000010000L  // 10 Memory select 0
#define LF   0b000000000000000000001000L  // 08 ALU Force subtraction
#define JE   0b000000000000000000000100L  // 04 conditional Jump Enable
#define N    0b000000000000000000000010L  // 02 Next Instruction (clear RC)
#define PI   0b000000000000000000000001L  // 01 PC Increment


// Microinstruction bit aliases
#define RPI   RP | PI       // Read PC and post increment
#define FA    RPI | WM      // Fetch argument (operand) step 1
#define SD    SCE | C0      // Stack Pointer decrement
#define SI    SCE | C1      // Stack Pointer increment
#define RDZ   RD | C0       // Read D+zero (read D)
#define RDX   RD            // Read D+X
#define RDY   RD | C1       // Read D+Y
#define CL    0             // 0 - Carry source ALU
#define CI    C0            // 1 - Carry source ALU inverted
#define CH    C1            // 2 - Carry source shift right (B lsb)


#define WR   W0             // 1 Write RAM
#define WM   W1             // 2 Write MAR (Memory Address)
#define WX3  W1|W0          // 3
#define WX4  W2             // 4
#define WX5  W2|W0          // 5
#define WS   W2|W1          // 6 Write SP
#define WP   W2|W1|W0       // 7 Write PC (Jump)
#define WA   W3             // 8 Write A
#define WB   W3|W0          // 9 Write B
#define WO   W3|W1          // A Write Output
#define WX   W3|W1|W0       // B Write X
#define WY   W3|W2          // C Write Y
#define WD   W3|W2|W0       // D Write D (Adder)
#define WXE  W3|W2|W1       // E
#define WI   W3|W2|W1|W0    // F Write IR

#define RR   R0             // 1 Read RAM
#define RX2  R1             // 2
#define RX3  R1|R0          // 3
#define RX4  R2             // 4
#define RX5  R2|R0          // 5
#define RS   R2|R1          // 6 Read SP
#define RP   R2|R1|R0       // 7 Read PC
#define RA   R3             // 8 Read A
#define RB   R3|R0          // 9 Read B
#define RH   R3|R1          // A Read H (sHift register (ALU B)
#define RX   R3|R1|R0       // B Read X
#define RY   R3|R2          // C Read Y
#define RD   R3|R2|R0       // D Read D
#define RL   R3|R2|R1       // E Read L (ALU result)
#define RF   R3|R2|R1|R0    // Read Flags

#define FF    FC|FZ|FV|FN   // Set all flags
#define FCZN  FC|FV|FN      // Set C,V,N flags
#define FZN   FZ|FN         // Set Z,N flags

// Note that the carry clear (CC) and carry set (CS) signals force a value of the
// carry flag for use by the ALU and H register.  The ALU uses negative logic for the
// flag, so clear=1 and set=0. There is an inverter before the ALU carry input, so the CC
// signal will present a one to the H register, but will present a zero to the ALU.

#define CMP   RL|FCZN|CS    // compare operation reads ALU into flags register during sub
#define ASL   RL|FCZN|CI|CC // use the ALU A+A op, set CZN flags, set carry from ALU, clr ALU carry in
#define ROL   RL|FCZN|CI    // use the ALU A+A op, set CZN flags, set carry from ALU, carry in to ALU
#define LSR   RH|FCZN|CH|CC // use H right shifter, set CZN flags, set carry from H, clr H carry in
#define ROR   RH|FCZN|CH    // use H right shifter, set CZN flags, set carry from H, carry in to H
#define DCR   RL|FZN|CC     // use ALU A-1 op, set ZN flags, clr ALU carry in
#define INC   RL|FZN|CS     // Use ALU A+1 op, set ZN flags, set ALU carry in


// Instruction opcodes.  Those marked with an asterisk use the ALU and thus must have
// specific opcodes that match the bits that are hardwired from the IR to the ALU control.
enum {
    IP_NOP = 0x00,  //   no operation
    AA_INA = 0x01,  // * increment A
    AB_INC = 0x02,  // * increment memory
    AX_INC = 0x03,  // * increment memory
    IP_INX = 0x05,  // * increment X
    IP_INY = 0x06,  // * increment Y
    AA_NOT = 0x08,  // * NOT A
    IP_OUT = 0x10,  //   output A
    IM_LDA = 0x11,  //   load immediate to A
    AB_LDA = 0x12,  //   load A from memory
    AX_LDA = 0x13,  //   load A from memory
    AY_LDA = 0x14,  //   load A from memory
    IX_LDA = 0x15,  //   load A from memory
    IY_LDA = 0x16,  //   load A from memory
    IM_LDX = 0x19,  //   load immediate to X
    AB_LDX = 0x1a,  //   load X from memory
    IP_TAX = 0x1b,  //   transfer A to X
    AY_LDX = 0x1c,  //   load X from memory
    IP_TSX = 0x1d,  //   transfer SP to X
    AB_STA = 0x22,  //   store A to memory
    AX_STA = 0x23,  //   store A to memory
    AY_STA = 0x24,  //   store A to memory
    IX_STA = 0x25,  //   store A to memory
    IY_STA = 0x26,  //   store A to memory
    AB_STX = 0x2a,  //   store X to memory
    IP_TXA = 0x2b,  //   transfer X to A
    AY_STX = 0x2c,  //   store X to memory
    IP_TXS = 0x2d,  //   transfer X to SP
    IP_CLC = 0x30,  // * clear carry flag
    IP_SEC = 0x31,  // * set carry flag
    IP_CLV = 0x32,  // * clear overflow flag
    IM_LDY = 0x39,  //   load immediate to Y
    AB_LDY = 0x3a,  //   load Y from memory
    AX_LDY = 0x3b,  //   load Y from memory
    IP_TAY = 0x3c,  //   transfer A to Y
    AB_STY = 0x4a,  //   store Y to memory
    AX_STY = 0x4b,  //   store Y to memory
    IP_TYA = 0x4c,  //   transfer Y to A
    IM_CPX = 0x60,  // * compare X immediate
    IM_SBC = 0x61,  // * subtract with carry
    AB_SBC = 0x62,  // * subtract with carry memory
    AX_SBC = 0x63,  // * subtract with carry memory
    AY_SBC = 0x64,  // * subtract with carry memory
    IX_SBC = 0x65,  // * subtract with carry memory
    IY_SBC = 0x66,  // * subtract with carry memory
    AB_CPX = 0x67,  // * compare X
    IP_PHA = 0x68,  //   push A
    IM_EOR = 0x69,  // * exlcusive OR A
    AB_EOR = 0x6a,  // * exlcusive OR A
    AX_EOR = 0x6b,  // * exlcusive OR A
    AY_EOR = 0x6c,  // * exlcusive OR A
    IX_EOR = 0x6d,  // * exlcusive OR A
    IY_EOR = 0x6e,  // * exlcusive OR A
    IM_CPY = 0x70,  // * compare Y immediate
    IM_CMP = 0x71,  // * compare A immediate
    AB_CMP = 0x72,  // * compare A
    AX_CMP = 0x73,  // * compare A
    AY_CMP = 0x74,  // * compare A
    IX_CMP = 0x75,  // * compare A
    IY_CMP = 0x76,  // * compare A
    AB_CPY = 0x77,  // * compare Y
    IP_PHP = 0x90,  //   push PS
    IM_ADC = 0x91,  // * add with carry A
    AB_ADC = 0x92,  // * add with carry memory
    AX_ADC = 0x93,  // * add with carry memory
    AY_ADC = 0x94,  // * add with carry memory
    IX_ADC = 0x95,  // * add with carry memory
    IY_ADC = 0x96,  // * add with carry memory
    IP_RTS = 0xa0,  //   return from subroutine
    AB_JSR = 0xa2,  //   jump to subroutine
    IN_JMP = 0xb0,  //   jump
    AB_JMP = 0xb2,  //   jump
    AB_BIT = 0xb8,  // * bit test A with memory
    IM_AND = 0xb9,  // * AND A
    AB_AND = 0xba,  // * AND A
    AX_AND = 0xbb,  // * AND A
    AY_AND = 0xbc,  // * AND A
    IX_AND = 0xbd,  // * AND A
    IY_AND = 0xbe,  // * AND A
    AA_ASL = 0xc0,  // * arithmetic shift left A
    AB_ASL = 0xc2,  // * arithmetic shift left memory
    AX_ASL = 0xc3,  // * arithmetic shift left memory
    AA_ROL = 0xc4,  // * rotate left thru carry
    AB_ROL = 0xc6,  // * rotate left thru carry memory
    AX_ROL = 0xc7,  // * rotate left thru carry memory
    RE_BCS = 0xc8,  //   branch if carry set
    RE_BCC = 0xc9,  //   branch if carry clear
    RE_BEQ = 0xca,  //   branch if equal (zero set)
    RE_BNE = 0xcb,  //   branch if not equal (zero clear)
    RE_BVS = 0xcc,  //   branch if overflow set
    RE_BVC = 0xcd,  //   branch if overflow clear
    RE_BMI = 0xce,  //   branch if plus (negative set)
    RE_BPL = 0xcf,  //   branch if plus (negative clear)
    AA_LSR = 0xd0,  //   logical shift right A
    AB_LSR = 0xd2,  //   logical shift right memory
    AX_LSR = 0xd3,  //   logical shift right memory
    AA_ROR = 0xd4,  //   rotate right thru carry
    AB_ROR = 0xd6,  //   rotate right thru carry memory
    AX_ROR = 0xd7,  //   rotate right thru carry memory
    AB_JCS = 0xd8,  //   jump if carry set
    AB_JCC = 0xd9,  //   jump if carry clear
    AB_JEQ = 0xda,  //   jump if equal (zero set)
    AB_JNE = 0xdb,  //   jump if not equal (zero clear)
    AB_JVS = 0xdc,  //   jump if overflow set
    AB_JVC = 0xdd,  //   jump if overflow clear
    AB_JMI = 0xde,  //   jump if plus (negative set)
    AB_JPL = 0xdf,  //   jump if plus (negative clear)
    IP_PLA = 0xe8,  //   pull A
    IM_ORA = 0xe9,  // * OR A
    AB_ORA = 0xea,  // * OR A
    AX_ORA = 0xeb,  // * OR A
    AY_ORA = 0xec,  // * OR A
    IX_ORA = 0xed,  // * OR A
    IY_ORA = 0xee,  // * OR A
    IP_PLP = 0xf0,  //   pull PS
    AA_DEA = 0xf1,  // * decrement A
    AB_DEC = 0xf2,  // * decrement memory
    AX_DEC = 0xf3,  // * decrement memory
    IP_DEX = 0xf5,  // * decrement X
    IP_DEY = 0xf6   // * decrement Y
};


// SSSSMxxx - Mapping of ALU control bits to opcode bits
enum {
    // The ALU operation is determined by the Mode bit (Arithmetic/Logic), the Select
    // bits, and the CARRY-IN bit. The Mode bit and the four Select bits of the ALU are
    // connected directly to the Instruction Register so that 5 additional microcode ROM
    // bits are not consumed. This means that, other than the CARRY-IN bit, all ALU
    // instructions can have identical microcode.  The bits below match the wiring of the
    // IR to the ALU and therefore also match the upper 5 bits of the 8-bit instruction
    // opcode. The CARRY-IN flag is not wired to the Instruction Register, so it is not
    // encoded as part of the instruction.
    ALU_S3 =              0b10000000,
    ALU_S2 =              0b01000000,
    ALU_S1 =              0b00100000,
    ALU_S0 =              0b00010000,
    ALU_M =               0b00001000
};

// Many of the combinations of control bits in the ALU do not map to useful operations, so
// this is a small subset of the complete 74181 ALU operation set.  Note that some ALU
// operations are unary operations or ALU operations that might be used by the underlying
// microcode, but are not useful as standalone instructions.  For example, the all-zeroes
// or all-ones operations are used by the microcode to clear and set flag registers.

enum {
    ALU_INC = 0,                                          // 00 A plus 1
    ALU_NOT =                                     ALU_M,  // 08 not A
    ALU_ZRO =                   ALU_S1 | ALU_S0,          // 30 all zero (-1 with carry)
    ALU_SUB =          ALU_S2 | ALU_S1,                   // 60 A minus B
    ALU_XOR =          ALU_S2 | ALU_S1          | ALU_M,  // 68 A xor B
    ALU_ADD = ALU_S3                   | ALU_S0,          // 90 A plus B
    ALU_B   = ALU_S3          | ALU_S1          | ALU_M,  // a8 returns B
    ALU_ASL = ALU_S3 | ALU_S2,                            // c0 A + A
    ALU_AND = ALU_S3          | ALU_S1 | ALU_S0 | ALU_M,  // b8 A and B
    ALU_OR  = ALU_S3 | ALU_S2 | ALU_S1          | ALU_M,  // e8 A or B
    ALU_DEC = ALU_S3 | ALU_S2 | ALU_S1 | ALU_S0           // f0 A minus 1
};


// Bits 7..3 of the Instruction Register are hard-wired to the ALU's S4..S0 and M bits.
// This dictates that all instructions that use a particular ALU operation are grouped
// together with the same values in the highest five bits of their opcodes.  This also
// means that only eight different instructions are possible that use any given ALU
// operation.
//
// Although it isn't reqired, many of the other instructions also follow the top-5 bit
// grouping, so that all of the STA instructions appear together, for example.
//
// By convention, the lowest three bits of the instruction are used to indicte the
// addressing mode for ALU instructions.
//
// The instructionGroupDefinitions table is used to create multiple versions of each
// instruction with different argument processing. For example, "ADD A to immediate value"
// and  "ADD A to value from memory indexed by X".  All of the two-argument ALU operations
// with  the same addressing mode, like ADD immediate and XOR immediate, share the same
// microcode.  This code is generated programmatically based on a selected argument
// addressing mode.
//
// The lowest three bits of the Instruction Register, and thus the opcode, are hard-wired
// to the flag-select bits of the jump control register.  This means that the conditional
// jump instructions all share the same microcode and their differents are determined by
// the opcode itself.

// There is one workaround for the eight instruction per ALU function limitation. The LF
// signal forces the S0 bit of the ALU to logic one, allowing eight additional
// instructions for some operations.  This is used to allow the SBC and CMP instructions
// to all use the ALU A-B function.
//

enum { GEN_COPY, GEN_ALU, GEN_BRANCH, GEN_JUMP };
struct InstructionGroupDefinition {
    uint8_t  gen;       // How are instructions generated
    uint32_t mcode;     // Additional microcode bits for flags
} instructionGroupDefinitions[] = {
    { GEN_COPY,   0       },   // 00 ALU increment operations
    { GEN_COPY,   0       },   // 08 ALU invert operations
    { GEN_COPY,   0       },   // 10 copy from template
    { GEN_COPY,   0       },   // 18 copy from template
    { GEN_COPY,   0       },   // 20 copy from template
    { GEN_COPY,   0       },   // 28 copy from template
    { GEN_COPY,   0       },   // 30 ALU zeros or ones to set and clear flags
    { GEN_COPY,   0       },   // 38 copy from template
    { GEN_COPY,   0       },   // 40 copy from template
    { GEN_COPY,   0       },   // 48 copy from template
    { GEN_COPY,   0       },   // 50 copy from template
    { GEN_COPY,   0       },   // 58 copy from template
    { GEN_ALU,    FF      },   // 60 SUB
    { GEN_ALU,    FZN     },   // 68 XOR
    { GEN_COPY,   0       },   // 70 ALU sub used for compare instructions
    { GEN_COPY,   0       },   // 78 copy from template
    { GEN_COPY,   0       },   // 80 copy from template
    { GEN_COPY,   0       },   // 88 copy from template
    { GEN_ALU,    FF      },   // 90 ADD
    { GEN_COPY,   0       },   // 98 copy from template
    { GEN_COPY,   0       },   // a0 copy from template
    { GEN_COPY,   0       },   // a8 copy from template
    { GEN_COPY,   0       },   // b0 copy from template
    { GEN_ALU,    FZN     },   // b8 AND
    { GEN_COPY,   0       },   // c0 ALU A+A for left shift instructions
    { GEN_BRANCH, 0       },   // c8 Conditional Branch
    { GEN_COPY,   0       },   // d0 copy from template
    { GEN_JUMP,   0       },   // d8 Conitional Jump
    { GEN_COPY,   0       },   // e0 copy from template
    { GEN_ALU,    FZN     },   // e8 OR
    { GEN_COPY,   0       },   // f0 copy from template
    { GEN_COPY,   0       }    // f8 copy from template
};


// ROM addressing 32K = 15 address bits
// rruiiii iiiissss
// rr                4 ROM chips possible (32 bit microinstruction word)
//   u               1 unused bit
//    iiii iiii      256 instructions
//             ssss  16 steps (max) per instruction
//
// To simplify microcode ROM burning and management, the microcode for all four chips is
// burned into every chip and the ROMs have the uppermost two address bits hardwired to
// determine which part of the microcode a chip is providing.  This means that all chips
// can be burned identically and that any chip can be installed in any slot.
//
// Rather than leaving parts of the EEPROM blank, duplicate copies of the microcode are
// burned for all of the values of the unused bits.

enum {
    NUM_ROMS = 4,
    NUM_FLAG_COMBOS = 2,
    NUM_INSTRUCTIONS = 256,
    NUM_STEPS = 16,
    NUM_TEMPLATE_STEPS = 8, // 2 hard-coded fetch steps plus 8 template steps

    GROUP_MASK = 0xf8,
    GROUP_SHIFT = 3
};

// Instruction addressing modes
enum {
    ADDR_MODE_00 = 0x00,    // No ALU instructions
    ADDR_MODE_IM = 0x01,    // #20 immediate value
    ADDR_MODE_AB = 0x02,    // $20 absolute memory location
    ADDR_MODE_AX = 0x03,    // $20,X absolute memory location + X
    ADDR_MODE_AY = 0x04,    // $20,Y absolute memory location + Y
    ADDR_MODE_IX = 0x05,    // ($20,X) indexed indirect memory location + X
    ADDR_MODE_IY = 0x06,    // ($20),Y indirect indexed memory location + Y
    ADDR_MODE_07 = 0x07,    // No ALU instructions

    ADDR_MODE_MASK = 0x07   // lowest 3 bits of opcode are the address mode
};

typedef uint32_t microcode_t;
typedef microcode_t template_t[256][NUM_TEMPLATE_STEPS];
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

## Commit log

2021-10-07 add kicad files
    [.sch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]
2021-10-12 Add Microcode and IR/RC modules. Add clock circuit to Loader module.
    [clock.sch, ir-rc.kicad_pcb, ir-rc.sch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]
2021-10-31 Add RAM, update and add gerbers for new boards
    [ab-register.kicad_pcb, ab-register.sch, backplane-conn.sch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]
2021-11-08 arduino code for loader v2
    [loader-B_Cu.gbl, loader-B_Mask.gbs, loader-B_Paste.gbp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]
2021-11-28 First set of microcode
    [in-general.csv, in-specific.csv]
2021-12-07 updated KiCads and gerbers for the AB Registers and IR/RC module
    [ab-register-B_Cu.gbl, ab-register-B_Mask.gbs, ab-register-B_Paste.gbp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]
2021-12-07 KiCad schematics, PCBs, and gerbers for the ALU and flags modules
    [alu-B_Cu.gbl, alu-B_Mask.gbs, alu-B_Paste.gbp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]
2021-12-18 fix typos in instruction set
    [in-specific.csv]
2021-12-18 conditional jump error in microcode
    [arduino-loader.ino, arduino-microcode.ino]
2021-12-30 document 3rd set of boards
2022-01-18 schematics and layouts for build 4 (output, PC-SP)
    [output-led-B_Cu.gbl, output-led-B_Mask.gbs, output-led-B_Paste.gbp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]
2022-01-18 normailize file line endings
    [in-specific.csv]
2022-08-24 XY index adder docs
    [d-register-B_Cu.gbl, d-register-B_Mask.gbs, d-register-B_Paste.gbp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]
2024-09-09 build 5 board updates
    [backplane-B_Cu.gbl, backplane-B_Mask.gbs, backplane-B_Paste.gbp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]
